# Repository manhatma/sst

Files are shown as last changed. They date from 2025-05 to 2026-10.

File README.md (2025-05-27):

Sufni Suspension Telemetry
==========================

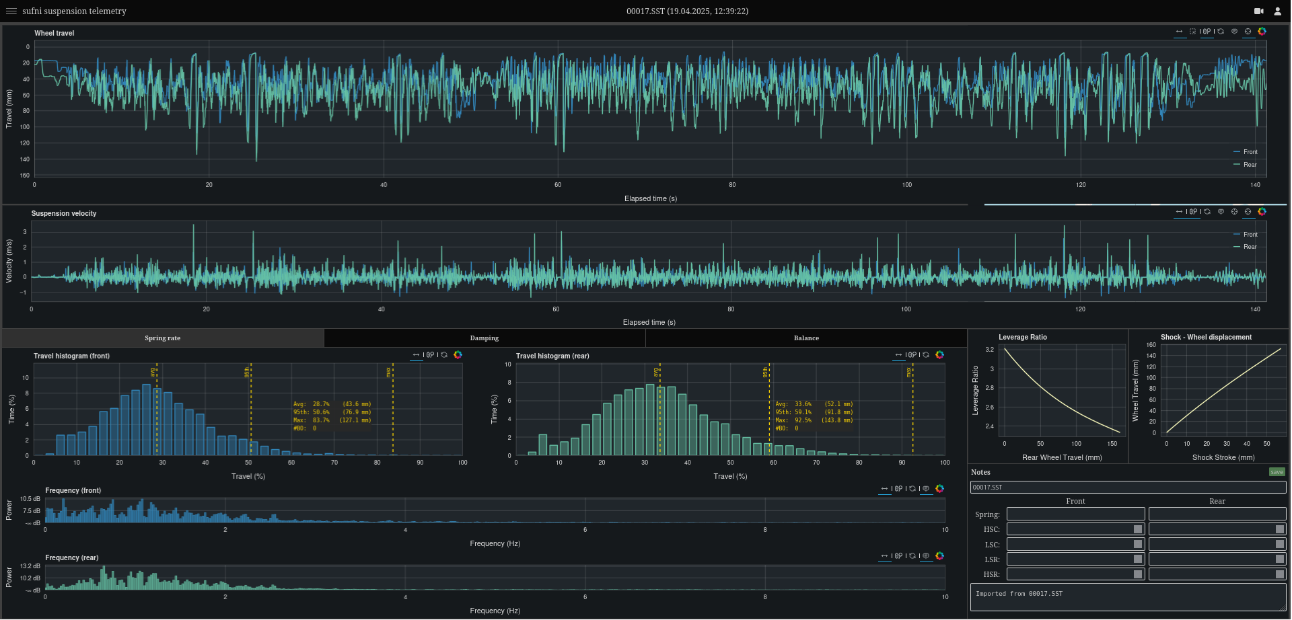
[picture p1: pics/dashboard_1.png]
dashboard

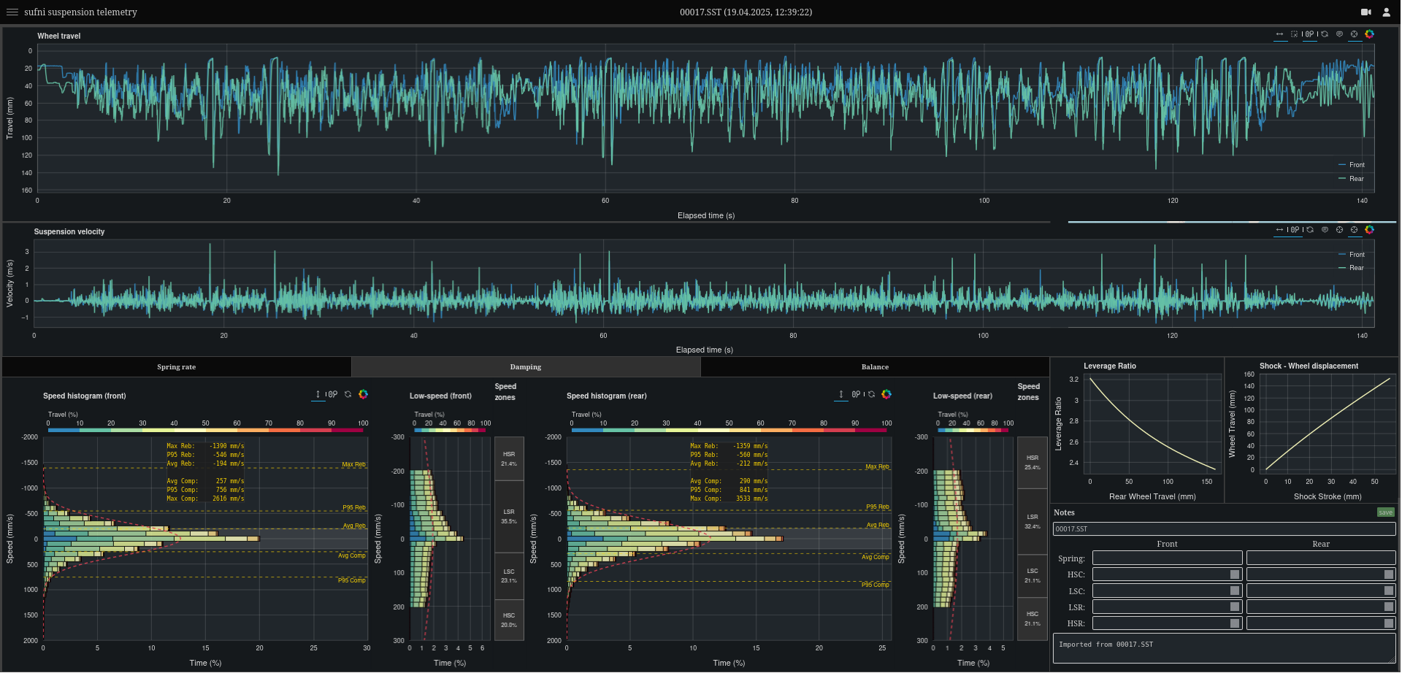
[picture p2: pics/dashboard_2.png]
dashboard


Sufni\* Suspension Telemetry is a mountain bike suspension telemetry system that
was born out of sheer curiosity. The [data acquisition unit](https://github.com/sghctoma/sst/wiki/02-Data-Acquisition-Unit) is built around the
Raspberry Pi Pico W and uses affordable off-the-shelf components, so anybody
with a bit of soldering skills can build it.

Contrary to most (all?) suspension telemetry systems, Sufni uses rotary encoders
to measure movement. They are cheap, reasonably accurate, and can reach pretty
high sample rates. An additional benefit is that on some frames they are easier
to attach to rear shocks than linear sensors, because they can fit into much
tigther spaces.

The DAQ uses a WiFi network to send recorded sessions to the backend server.
When processing is done, data can be analyzed on the [web user interface](https://github.com/sghctoma/sst/wiki/03-Dashboard) that
provides plots useful for setting up the spring rate, damping and the bike's
overall balance. GPX tracks can also be uploaded, and MP4 videos can be opened
from the local machine. These are synchronized to the travel plot, so you can
easily find how your suspension behaved on a certain part of the trail.

The user interface has two additional functionalities:

 - New bike setups can be created, and they can be associated with a DAQ unit
   based on the Pico's uniqe identifer.
 - Normalized (travel percentage, or a number between 0 and 1) data can also be
   [imported](https://github.com/sghctoma/sst/wiki/04-Importing-normalized-data) from CSV files, so you can use the webapp without being tied to
   Sufni's hardware.

Please refer to the wiki for a [quickstart guide](https://github.com/sghctoma/sst/wiki/01-Quickstart-guide), build instructions, and a full
tour on the user interface, plots etc.

\* *The word "sufni" (pronounced SHOOF-nee) means tool shed in Hungarian, but
also used as an adjective denoting something as DIY, garage hack, etc.*

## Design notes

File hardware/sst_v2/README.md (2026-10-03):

# SST v2 Mainboard — Rev. 3 (KiCad)

DAQ-Mainboard für Sufni Suspension Telemetry: 24-bit-ADC für Fork- und Shock-Poti,
Takt für vier IMUs, microSD, RTC, Pico 2 W. Entwurfsgrundlage und Begründungen:
`firmware/docs/plan-ads131m04-icm42686.md`.

```bash
open -a "KiCad" /Users/niels/Telemetry/sst/hardware/sst_v2/sst_v2.kicad_pro
```

Nur diesen Ordner bearbeiten. Vor Skript-Änderungen KiCad schließen
(`~*.lck`), sonst überschreibt die GUI beim Speichern.

## Platine

60 × 90 mm, 4 Lagen, 1,6 mm FR4, ENIG. 4× M3-NPTH (H1–H4).

Platzierung:

- Oben: Pico 2 W auf Buchsenleisten, U1 bei (134,4 / 59,8). Der Körper liegt bei x 84,7–137,1 mm. Das Antennenende liegt am linken Platinenrand (Kante 84,5 mm), wie Raspberry Pi es empfiehlt. Das USB-Ende liegt bei x 137,1 mm. Vor dem USB-Ende liegen 7,4 mm Platine (Rand 144,5 mm).
- Links: Poti-Eingang (J_POT1 am Rand, ESD D2–D4, CMCs), darunter Analogblock (LDO, ADC, Opamp, RC-Netz). Der Analogblock liegt weit weg von Funkmodul und SMPS des Pico.
- Mitte: RTC-Batterie BT1 unter dem Pico, Öffnung zum Pico. Der Bereich zwischen BT1 und den Pico-Buchsenleisten ist frei von Bauteilen, damit die Zelle heraus- und hineingleitet.
- Rechts: OLED- und Taster-Stecker am Rand neben ihren Pico-Pins, Buzzer BZ1, Stromversorgung (D1, D_VSYS1, C26), microSD. Der Körper von J_SD1 endet 0,25 mm vor der Platinenkante.
- Oberkante (x 113–123,6 mm, y 48,3–55,2 mm, zwischen Q_RP1 und J_DEBUG1, außerhalb des Pico): Lader U_CHG1 mit C_CHG1/C_CHG2, R_PROG, R_STAT1/R_STAT2. Thermalfläche: Zone „Lader Thermal“ (GND, F.Cu, Priorität 2, volle Anbindung) über den Laderbereich und den Streifen über J_DEBUG1, gefüllt 0,77 cm² zusammenhängend (0,49 cm² im Laderbereich). Sechs GND-Vias 0,6/0,3 mm links neben dem VSS-Pad (Pin 2) zur GND-Lage In1. +VBUS und +VBAT kommen auf B.Cu, F.Cu bleibt dort fast ganz GND.
- Unter dem Pico: R50 (ADC_RST) bei (110,0 / 62,3) neben GP7 (Pin 10). Soft-Power-Steuerung (U_PWR1, C_PWR1, Q_PWR2, Q_PWR3, R_PWR2–R_PWR4, D_PWR1) und Fuel Gauge (U_FG1, C_FG1) zwischen den Buchsenleisten bei x 120–135 mm, y 61–74 mm (Bauhöhe ≤ 1,1 mm, Buchsenleisten 8,5 mm). `sst_v2.kicad_dru` erlaubt die Courtyard-Überdeckung mit U1 nur für diese Teile.
- Unter der unteren Pico-Buchsenleiste (außerhalb des Pico): Lastschalter Q_PWR1 (119,6 / 82,1) mit Gate-Pull-up R_PWR1 (122,9 / 82,1), direkt vor C26.
- Pico-Antenne (Ende gegenüber USB, x < 94 mm, am linken Rand): Rule Area „Pico antenna: keepout“ auf allen Kupferlagen, ohne Leiterbahnen, Vias und Pours. Sie deckt den Raum zwischen den Buchsenleisten (x 84,5–94,0 mm, y 61,3–76,1 mm) und das Pico-Ende über die volle Breite ab (x 84,5–85,1 mm, y 57,1–80,2 mm). Der Rand von 1 mm liegt außerhalb der Platine, die Fläche endet an der Kante. Die Streifen der Buchsenleisten bleiben frei, damit die Leitungen an Pin 17–24 nach außen laufen. In1 (GND) und In2 (+3V3_DIG) haben dort eine Aussparung.
- Fiducials FID1–FID3 (1 mm, Maske 3 mm) auf F.Cu: (135,95 / 54,8), (89,5 / 106,8), (136,95 / 101,3). Alle ≥ 5 mm von der Kante, außerhalb von Pico und Steckern.
- Montagelöcher: Alle Courtyards liegen ≥ 3,5 mm von der Bohrungsmitte (Platz für Schraubenkopf oder Scheibe Ø 7 mm).
- Unten: IMU-Stecker, Taktteiler und Taktpuffer.
- Digitalleitungen (IMU, SD, UI) laufen außerhalb des Analogblocks. Die ADC-SPI-Leitungen laufen im Poti-Block nur auf B.Cu, getrennt durch die GND-Lage In1.

| Lage | Inhalt |
|---|---|
| F.Cu | Bauteile, Signale, GND-Pour |
| In1.Cu | GND, durchgehend |
| In2.Cu | +3V3_DIG; Insel +3V0_ANA unter der analogen Seite von LDO/ADC/Opamp (x 94,3–108,5 mm, y 112,2–132,5 mm, dazu Streifen y 107,8–112,2 mm ab x 84,9 mm). Die digitale Seite von LDO und ADC (x < 94,3 mm) liegt über +3V3_DIG. |
| B.Cu | Signale, GND-Pour |

Fertigungsregeln (PCBWay): Leiterbahn/Abstand ≥ 0,2 mm, Via 0,6/0,3 mm (+3V3_DIG: 0,7/0,4 mm,
Power: 0,8/0,4 mm), Via-Restring ≥ 0,15 mm, Kupfer–Kante ≥ 0,3 mm, Lötstopp-Steg ≥ 0,1 mm
(grüner Lötstopp). Silkscreen: Strichbreite ≥ 0,15 mm, Texthöhe ≥ 0,8 mm (PCBWay-Minimum). `sst_v2.kicad_pro`
prüft Restring und Textstrich mit 0,15 mm, Texthöhe mit 0,8 mm.

## Schaltung

| Block | Bauteile | Kurzbeschreibung |
|---|---|---|
| ADC | U2 ADS131M04 | CH0 Fork, CH1 Shock, CH2 Poti-Speisung (ratiometrisch), CH3 an GND. AVDD 3,0 V, DVDD = Netz +3V3_DVDD aus +3V3_DIG über FB1 (Logikpegel = Pico-Pegel, PWR_FLAG hinter FB1). CAP 220 nF. SYNC/RESET (ADC_RST) über R50 100 Ω an GP7 (ADC_RST_MCU), Pull-up R1, C4. |
| Analog-LDO | U_ANA_LDO1 TPS7A4700 (RGW) | 3,3 V → 3,0 V, ANY-OUT: nur 1P6V (Pin 8) an GND, übrige ANY-Pins offen. SENSE an OUT. NR 10 nF (C25), IN 10 µF (C22), OUT 22 µF (C6). |
| Poti-Speisung | U_AAF1 TLV4333 (A), R32/R33 20k/10k 0,1 %, C35 | 1,0 V Referenz, gepuffert, 47 Ω (R34) auf POT_EXC, Messung über R35/C36 an AIN2P. |
| Schleifer | U_AAF1 (B, C), R36/R37, R8/R14, C9/C12 | Opamp-Puffer, danach 1 kΩ + 10 nF an AINxP. AINxN = Poti-Masse (Remote Sense), R9/R15 0 Ω als Sternpunkt. |
| Poti-Stecker | J_POT1 JST-SH 6 → HR30 6p | 1 POT_EXC, 2 Fork-Schleifer, 3 Fork-Masse, 4 Shock-Schleifer, 5 Shock-Masse, 6 Schirm/GND. ESD D2–D4, CMC L_FORK/L_SHOCK (DLW5BTM251SQ2L). |
| Takt | Y1 ECS-2520MVLC 8,192 MHz, U_DIV1 74HC4040, U_CLKBUF1 74LVC125 | XO → 33 Ω → ADC CLKIN; XO → 4040 Q7 = 32,000 kHz → 2 Puffer → 33 Ω → IMU-CLKIN A/B. |
| IMU | J_IMU_A1/B1 JST-SH 12 → HR30 12p | 1 IMU_3V3 (FB2), 3 SCLK, 5 MOSI, 7 MISO, 8 CLKIN, 10/11 CS, 2/4/6/9/12 GND. 33 Ω in allen DAQ-Ausgängen. |
| Strom | J_BAT1, Q_RP1, Q_PWR1, D1, D_VSYS1 | LiPo (JST-PH) → Q_RP1 DMG2305UX (Verpolschutz) → +VBAT → Q_PWR1 DMG2305UX (Soft-Power-Schalter) → +VBAT_SW (TVS D1, C26–C28) → D_VSYS1 PMEG3020EH → VSYS. D_VSYS1 verhindert, dass USB-VBUS direkt in den Akku speist. Kein externer Schalter mehr (J_PWR1 entfällt). |
| Soft-Power | U_PWR1 MAX16150AUT+T, Q_PWR1 DMG2305UX, Q_PWR2/Q_PWR3 2N7002, R_PWR1–R_PWR4 100k, C_PWR1 100 nF, D_PWR1 RB751S40 | U_PWR1 VCC an +VBAT. Taster SW_L1 → PWR_BTN → PB_IN (interner Pull-up 1,2–2,0 MΩ an VCC). Drücken > 50 ms: OUT (PSW_EN) high → Q_PWR2 zieht PSW_GATE auf GND → Q_PWR1 leitet. R_PWR1 hält Q_PWR1 sonst aus, R_PWR2 hält Q_PWR2 aus, solange OUT undefiniert ist. Aus per Firmware: GP28 (PWR_OFF) high → Q_PWR3 zieht ~CLR low → OUT low. R_PWR4 hält Q_PWR3 ohne Firmware aus. ~CLR-Pull-up R_PWR3 an OUT (Datenblatt-Empfehlung): kein VBAT-Pegel an einem GPIO. Halten > 8 s (Version A): OUT low, Hardware-Aus. ~INT offen. BTN_L (GP4, R27 10k an +3V3_DIG) liegt über D_PWR1 (Anode BTN_L, Kathode PWR_BTN) am Taster: SW_L1 bleibt UI-Taste. |
| Fuel Gauge | U_FG1 MAX17048G+T10, C_FG1 100 nF | VDD (Messeingang) und CELL an +VBAT, dauerhaft versorgt. I2C 0x36 am PIO-I2C (DISP_SDA/DISP_SCL, R25/R26). CTG, QSTRT, EP an GND, ~ALRT offen (kein GPIO frei). |
| Lader | U_CHG1 MCP73831T-2ACI/OT, C_CHG1/C_CHG2 4,7 µF, R_PROG 3,3k, R_STAT1/R_STAT2 10k/10k | Platz an der Oberkante außerhalb des Pico, mit Thermalfläche (GND-Zone 0,77 cm² an VSS, 6 Vias zu In1). VDD an +VBUS (Pico Pin 40), Ausgang an +VBAT (vor dem Schalter): Laden auch bei ausgeschaltetem Gerät (Q_PWR1 offen). 4,20 V, 300 mA (I = 1000 V / R_PROG; 500 mA mit 2,0k). STAT über Teiler 10k/10k an GP6 (CHG_STAT): Laden = 0 V, fertig = 0,5 × VBUS (2,5 V bei 5,0 V, max. 2,6 V bei 5,25 V), ohne VBUS hochohmig → 0 V. USB kommt über ein Kabel von einer Gehäusebuchse in die Micro-USB-Buchse des Pico. |
| RTC | U3 DS3231SN, BT1 CR1220 | VBAT direkt an der Zelle, RST offen. I2C gemeinsam mit OLED und U_FG1 (PIO, R25/R26 4,7k). |
| microSD | J_SD1 DM3AT | SPI0. Pull-ups: SD_CS 10k (R31), DAT1 47k (R48), DAT2 47k (R49). |
| UI | SW_L1/SW_R1 (JST-SH 2), BZ1 PS1240P02BT, J_OLED1, J_DEBUG1 | Taster mit 10k-Pull-up. SW_L1 ist zusätzlich die Power-Taste (siehe Soft-Power). Buzzer über 47 Ω an GP22. J_DEBUG1: 1 RX (GP1), 2 TX (GP0), 3 GND. SWD direkt am Pico. |
| MCU | U1 Pico 2 W | Steckt in 2× 1×20-Buchsenleisten (8,5 mm). 3V3_EN offen (interner Pull-up). |

### Pico-Pinbelegung

| GP | Netz | GP | Netz |
|---:|---|---:|---|
| 0/1 | UART TX/RX | 14 | IMU_MISO |
| 2/3 | DISP_SDA/SCL (PIO I2C, RTC + OLED + Fuel Gauge) | 15 | IMU_CS0 |
| 4/5 | BTN_L (über D_PWR1 auch Power-Taste)/BTN_R | 16–19 | SD MISO/CS/SCK/MOSI (SPI0) |
| 6 | CHG_STAT (Lader, Teiler 10k/10k) | 20 | ADC_DRDY |
| 7 | ADC_RST_MCU → R50 100 Ω → ADC_RST (SYNC/RESET) | 21 | IMU_CS1 |
| 8/9 | IMU_SCLK/MOSI (PIO-SPI) | 22 | Buzzer |
| 10–12 | ADC SCK/SDI/SDO (SPI1) | 26/27 | IMU_CS2/CS3 |
| 13 | ADC_CS | 28 | PWR_OFF (high = Abschalten, Q_PWR3 → MAX16150 ~CLR) |

## Fertigungsdaten (`fab/`)

- `gerber/` + `sst_v2_gerber.zip`: Gerber (Protel-Endungen), Excellon PTH/NPTH, Bohrpläne, Job-Datei.
- `sst_v2_BOM_PCBWay.csv`, `sst_v2_CPL_PCBWay.csv`: 111 Positionen. Der Pico wird nicht bestückt, nur die Buchsenleisten.
  H1–H4, FID1–FID3 und TP1–TP15 stehen nicht in BOM und CPL.

Bestellhinweis PCBWay:

| Parameter | Wert |
|---|---|
| Größe | 60 × 90 mm (die Job-Datei meldet 60,1 × 90,1 mm wegen der Breite der Konturlinie) |
| Lagen | 4, Lagenzuordnung: L1 `sst_v2-F_Cu.gtl`, L2 `sst_v2-GND.g1`, L3 `sst_v2-PWR.g2`, L4 `sst_v2-B_Cu.gbl` |
| Dicke | 1,6 mm FR4 |
| Oberfläche | ENIG |
| Lötstopp / Bestückungsdruck | grün / weiß |
| Fiducials | FID1–FID3 auf F.Cu |

Export (Ordner `hardware/sst_v2`):

```bash
kicad-cli pcb export gerbers -l "F.Cu,In1.Cu,In2.Cu,B.Cu,F.Paste,B.Paste,F.Silkscreen,B.Silkscreen,F.Mask,B.Mask,Edge.Cuts" --subtract-soldermask -o fab/gerber/ sst_v2.kicad_pcb
kicad-cli pcb export drill --format excellon --excellon-separate-th --excellon-units mm --generate-map --map-format gerberx2 -o fab/gerber/ sst_v2.kicad_pcb
```

## Testpads (Unterseite)

15 SMD-Pads D 1,0 mm (`TestPoint:TestPoint_Pad_D1.0mm`) auf B.Cu, nur B.Mask, keine Paste.
Nicht bestückt: nicht in BOM und CPL (`in_bom no`, `exclude_from_bom`, `exclude_from_pos_files`).
Beschriftung = Wert auf B.Silkscreen (0,8 mm, Strich 0,15 mm, von unten lesbar), Referenz verborgen.
Im Schaltplan als Gruppe „Testpads (Unterseite, nicht bestückt)“ rechts unten.

| TP | Netz | Beschriftung | Lage B-Seite (x/y mm) | Anbindung | Zweck |
|---|---|---|---|---|---|
| TP1 | GND | GND | 93,00 / 121,00 | GND-Pour B.Cu | Masse Analogteil (U2/LDO) |
| TP2 | GND | GND | 110,00 / 57,00 | GND-Pour B.Cu | Masse Stromversorgung (Lader, Q_RP1) |
| TP3 | GND | GND | 89,80 / 126,11 | GND-Pour B.Cu | Masse für Taktmessung, 2,55 mm neben TP6 |
| TP4 | +3V0_ANA | 3V0A | 96,46 / 114,05 | auf vorhandener Via | Analog-LDO-Ausgang |
| TP5 | +3V3_DVDD | DVDD | 86,80 / 128,68 | neue Via im Pad, F.Cu 0,6 mm | ADC-DVDD hinter FB1 |
| TP6 | ADC_CLKIN | CLK | 92,30 / 126,61 | neue Via im Pad, direkt auf der Leiterbahn (kein Stich) | 8,192-MHz-Takt am ADC (zwischen R38 und U2 Pin 17) |
| TP7 | +VBAT_SW | VBSW | 123,38 / 106,85 | Via + 1,0 mm B.Cu | Akku nach Q_PWR1 (Soft-Power) |
| TP8 | +VBAT | VBAT | 115,70 / 52,55 | auf vorhandener Via | Akku vor Q_PWR1 / Laderausgang |
| TP9 | EXC_REF | REF | 104,93 / 110,25 | neue Via im Pad, auf der Leiterbahn | Referenzspannung (R32/R33/C35, U_AAF1 Pin 3) |
| TP10 | POT_EXC | EXC | 90,95 / 87,84 | auf vorhandener Via | Poti-Speisung am Stecker |
| TP11 | FORK_AIN_P | FORK | 100,83 / 126,54 | Via + 1,0 mm B.Cu | ADC-Eingang Gabel |
| TP12 | SHOCK_AIN_P | SHCK | 100,92 / 123,39 | neue Via (F.Cu 0,6 mm) + 1,0 mm B.Cu | ADC-Eingang Dämpfer |
| TP13 | IMU_CLK32K | 32K | 117,75 / 121,65 | neue Via im Pad, auf der Leiterbahn | 32,768-kHz-Takt der IMUs |
| TP14 | IMU_3V3 | IMU | 126,50 / 134,81 | auf vorhandener Via | IMU-Versorgung |
| TP15 | GND | GND | 114,30 / 127,25 | GND-Pour B.Cu | Masse Takt-/IMU-Bereich (U_DIV1) |

Abstand Pad zu Pad ≥ 2,54 mm. Keine Pads in der Pico-Antennenfläche. Vias 228 → 233.

## Prüfstand (2026-10-03)

- ERC: 0 Fehler. 2 Warnungen, bewusst: MP-Pins von SW_L1/SW_R1.
- DRC mit Schaltplan-Parität (`--refill-zones --all-track-errors --severity-all`): 0 Fehler, 0 offene Verbindungen,
  0 Paritätsfehler. 6 Warnungen `lib_footprint_mismatch`, bewusst:
  H1–H4 ohne Courtyard, J_SD1 mit um 0,4 mm gekürzten vorderen Schirm-Pads (Kupfer–Kante 0,3 mm),
  U1 ohne Silkscreen-Linien am USB-Ende (lag bis 2026-10-03 am Platinenrand).
- Alle Referenzen stehen auf dem Silkscreen mit 0,8 mm Höhe und 0,15 mm Strich, von Hand positioniert (2026-10-03). Nur H1, H2 und FID1–FID3 haben die Referenz auf F.Fab. Referenzen unter dem Pico (R2, R27–R29, R41, R42, R44–R46, R50) sind nach dem Aufstecken verdeckt.
- U_AAF1: Referenz im Gehäuseumriss (links davon sitzt jetzt C1).
- U1: Die Silkscreen-Markierung im USB-Bereich unter dem Pico ist entfernt (lag über den früheren Lader-Pads).
- Zonen sind gefüllt gespeichert. Leiterbahnlänge 2658 → 2644 mm, Vias 225 → 228 (Lader an der Oberkante).
- Soft-Power + Fuel Gauge (2026-10-03): ERC und DRC wie oben (keine neue Warnung). Leiterbahnlänge 2649 → 2697 mm, Vias 233 → 250. Neue Verbindungen mit einem Rasterrouter (Raster 0,05 mm, Abstand netzklassengerecht), danach DRC. Neue Referenzen unter dem Pico (U_PWR1, C_PWR1, D_PWR1, Q_PWR2, Q_PWR3, R_PWR2–R_PWR4, U_FG1, C_FG1) sind nach dem Aufstecken verdeckt.
- Pico 7 mm nach links (2026-10-03): ERC und DRC wie oben (keine neue Warnung). Leiterbahnlänge 2697 → 2735 mm, Vias 250 → 264. Details im Review unten.
- Doppelte UUIDs: TP1–TP15 teilten sich 5 UUIDs (Pad und Grafik, 70 Duplikate aus dem Kopier-Skript). Alle Duplikate haben jetzt eigene UUIDs.

## Review Rev. 3 (2026-10-03): Pico 7 mm nach links

| Änderung | Grund |
|---|---|
| U1 (Pico 2 W) 7,0 mm nach links: (141,4 / 59,8) → (134,4 / 59,8). Körper x 84,7–137,1 mm. Vor dem USB-Ende liegen jetzt 7,4 mm Platine (vorher 0,4 mm). | Gehäusegröße: Der 90°-Micro-USB-Stecker brauchte 9 mm über den Platinenrand. Er ragt jetzt 7 mm weniger heraus. |
| Antennenende am linken Rand (Körper 84,7 mm, Kante 84,5 mm). Rule Area „Pico antenna: keepout“ um 7 mm mit verschoben und an der Kante abgeschnitten: x 84,5–94,0 mm (vorher 90,7–101,0 mm). | Raspberry Pi empfiehlt die Antenne am Platinenrand. Unter der Antenne liegt kein Kupfer, auch nicht in In1/In2. |
| R50 6,6 mm nach links: (116,6 / 62,3) → (110,0 / 62,3). | Der Serienwiderstand bleibt direkt an GP7 (Pin 10). ADC_RST_MCU ist 1,5 mm lang. |
| Leitungen am Pico neu geroutet: Rasterrouter (Raster 0,05 mm, Abstand netzklassengerecht, Rip-up bei Konflikten). Entfernt: Leiterbahnen und Vias der Pico-Netze im Band y 56,6–84 mm, dazu IMU_CS0, IMU_MOSI, IMU_SCLK und ADC_RST im selben Band. Die neuen Leitungen schließen an die vorhandenen Leitungen unterhalb von y 84 mm und an der Oberkante an. | Die Pins liegen 7 mm weiter links. Die alten Leitungen kreuzten die neuen Pads. Analogblock und Poti-Block bleiben unverändert. |
| +VBAT (0,5 mm) unter dem Pico 0,62 mm nach rechts. PSW_GATE an Pin 34 vorbei neu gelegt. | Beide Leitungen liefen durch die neuen Pad-Positionen. Die Lücken der Buchsenleisten liegen jetzt 0,62 mm weiter rechts. |
| ADC-SPI im Poti-Block weiter nur auf B.Cu, keine neuen Vias dort. Unter den linken unteren Pico-Pins (y 78,4–85 mm) laufen die SD-Leitungen nur auf F.Cu und die ADC-Leitungen nur auf B.Cu, dort ohne Vias. | Die ADC-Leitungen kommen jetzt zwischen den Buchsenleisten herunter (x 94–102 mm) und laufen unter den SD-Abgängen zum linken Rand. Die GND-Lage In1 trennt beide Gruppen. |
| +VBUS (0,5 mm) von Pin 40 über den Streifen rechts vom Pico (x 135,1–135,7 mm), F.Cu bei y 53,25 mm, B.Cu zum Lader. VSYS (0,5 mm) auf F.Cu von Pin 39 zu D_VSYS1. | Die Power-Leitungen laufen nicht durch die Lücken der Buchsenleisten. |
| 2 GND-Vias 0,6/0,3 mm mit 0,25-mm-Leitung an U1 Pin 3 (128,27 / 58,95) und Pin 28 (103,92 / 78,93). | DRC `starved_thermal`: An Pin 28 war die F.Cu-Pour-Fläche eine Insel. An Pin 3 erreichte nur ein Steg den Pour. |
| Texte „SSDAQ v1 Rev 3“ und „10/2026“ an den rechten Rand (x 139,6 / 142,0 mm). | Der alte Platz links vom Pico liegt jetzt unter dem Pico. |

Ergebnis: ERC 0 Fehler (2 bekannte MP-Warnungen). DRC 0 Fehler, 0 offene Verbindungen, 0 Paritätsfehler, 6 bekannte `lib_footprint_mismatch`. Leiterbahnlänge 2697 → 2735 mm, Vias 250 → 264 (Pico-Netze 1135 → 1175 mm, 33 → 44 Vias). Gerber, Bohrdaten, ZIP, CPL (U1, R50) und `enclosure/sst_v2_board.step` neu erzeugt. BOM unverändert.

## Review Rev. 3 (2026-10-03): Soft-Power MAX16150 + Fuel-Gauge MAX17048

| Änderung | Grund |
|---|---|
| J_PWR1 (externer Schalter) entfernt. Q_PWR1 DMG2305UX als High-Side-Schalter zwischen +VBAT und +VBAT_SW, gesteuert von U_PWR1 MAX16150AUT+T über Q_PWR2 2N7002. | Ein- und Ausschalten mit der linken Panel-Taste. Die Firmware kann das Gerät selbst abschalten. |
| SW_L1 Pin 2 → PWR_BTN (PB_IN). BTN_L über D_PWR1 RB751S40 an PWR_BTN. | Die Taste bleibt UI-Taste. Gedrückt: BTN_L = VF ≈ 0,3 V (low). Losgelassen: Diode sperrt, kein Strom in den GPIO. Pico ohne Spannung: Diode sperrt, nur Leckstrom. |
| GP28: VBAT_SENSE → PWR_OFF. R19/R20/C29 entfernt. GP28 → Q_PWR3 2N7002 → ~CLR. R_PWR3 100k von ~CLR an OUT. | Kein GPIO frei. Die Akkuspannung misst jetzt U_FG1. ~CLR nur an OUT hochgezogen: Im Aus-Zustand liegt kein VBAT-Pegel an einem Pin des Pico. |
| U_FG1 MAX17048G+T10 mit C_FG1 an +VBAT und PIO-I2C (0x36). | Ladezustand (SOC), Zellspannung (VCELL) und Lade-/Entladerate (CRATE) über I2C. |
| Netzklassen-Muster VBAT_SENSE aus `sst_v2.kicad_pro` entfernt. Courtyard-Regel für die Teile unter dem Pico in `sst_v2.kicad_dru`. | Netz existiert nicht mehr. Teile sitzen absichtlich unter dem Pico. |
| Langer Leiterzug von der Oberkante (früher +VBAT_SW ab J_PWR1) ist jetzt +VBAT. Q_PWR1 sitzt am unteren Ende vor C26. | Leistungspfad bleibt 0,5 mm breit und kurz. +VBAT liegt damit auch für U_PWR1 und U_FG1 bereit (Zuleitung 0,3/0,25 mm, µA-Lasten). |

Datenblattwerte:

- **MAX16150A** (Datenblatt Rev 4, 1/21): VCC 1,3–5,5 V. ISB ≤ 20 nA (VCC 5 V, OUT low, −40…+70 °C), 10/40 nA typ/max bis +85 °C. ICC 15/30 µA nur während PB_IN-Erkennung oder INT-Puls. PB_IN-Pull-up 1,2/1,4/2,0 MΩ an VCC, Eingang ±60 V. VIH 0,7 × VCC, VIL 0,3 × VCC. tDB 50 ms, tSO 8 s (±20 %). ~CLR wird bei OUT low ignoriert und nach OUT high für 1,6–2,4 × tINT (51–77 ms). OUT = VCC − 0,1 V bei 20 mA. Das Datenblatt empfiehlt Pull-up von ~CLR/~INT an OUT.
- **Q_PWR1 DMG2305UX:** RDS(on) ≤ 52 mΩ (typ 40) bei VGS −4,5 V, ≤ 100 mΩ (typ 52) bei −2,5 V. Bei leerem Akku (VGS −3,0 V) also ≤ 100 mΩ: 0,5 A → ≤ 50 mV, ≤ 25 mW. VGS(th) −0,5…−0,9 V, IDSS ≤ 1 µA.
- **Q_PWR2/Q_PWR3 2N7002 (Diodes):** VGS(th) 1,0–2,5 V, IDSS ≤ 1 µA (60 V), IGSS ≤ 10 nA. Last nur 42 µA (4,2 V / 100k): bei VGS 3,0 V (Akku leer) bzw. 3,3 V (GP28) sicher durchgeschaltet.
- **D_PWR1 RB751S40 (Nexperia):** VF ≤ 370 mV bei 1 mA. Kurve: ≈ 0,27 V bei 0,33 mA (25 °C), ≈ 0,36 V bei −40 °C. RP2350 VIL ≤ 0,8 V: BTN_L ist sicher low. IR ≤ 0,5 µA bei 30 V. Kurve: ≈ 15 nA bei 4 V / 25 °C, ≈ 1,5 µA bei 85 °C. Spannungsabfall an PB_IN im Aus-Zustand: 15 nA × 1,4 MΩ = 21 mV (25 °C), ≈ 0,4 V bei 60 °C (2,0 MΩ). PB_IN bleibt über 0,7 × VCC.
- **MAX17048** (Datenblatt Rev 7): VDD 2,5–4,5 V. Aktiv 23/40 µA, Hibernate 3/5 µA (VRESET.Dis = 1) bzw. 4 µA typ (Komparator an), Sleep 0,5/2 µA (≤ 50 °C). Sleep nur mit MODE.EnSleep = 1 und SDA und SCL < VIL (0,5 V) für tSLEEP 1,75–2,5 s; eine steigende Flanke an SDA oder SCL weckt den Baustein. SDA/SCL haben 0,2/0,4 µA Pull-down (Erkennung „Bus offen“). Datenpins −0,3…+5,5 V unabhängig von VDD, SDA Open Drain, SCL Eingang: kein Rückspeisen in den 3V3-Bus. VIH 1,4 V. Im Sleep erkennt der Baustein keine Selbstentladung. Laden weckt ihn: USB versorgt den Pico, der Bus geht high.

### Ruhestrom im Aus-Zustand (USB ab, Pico ohne Spannung, 25 °C)

| Teil | typ | max | Bemerkung |
|---|---:|---:|---|
| U_PWR1 MAX16150 (ISB) | < 20 nA | 20 nA | Grenzwert bei 5 V, ≤ 70 °C |
| D_PWR1 Leckstrom über PB_IN-Pull-up | 15 nA | 0,5 µA | max = IR-Grenzwert bei 30 V |
| U_FG1 MAX17048, Sleep (EnSleep = 1) | 0,5 µA | 2 µA | ohne EnSleep: Hibernate 3 µA typ / 5 µA max |
| U_CHG1 MCP73831, Rückstrom (VDD offen) | 0,25 µA | 2 µA | |
| Q_PWR1 IDSS in die +VBAT_SW-Last | < 0,01 µA | 1 µA | max bei −20 V |
| Q_PWR2 IDSS über R_PWR1 | < 0,01 µA | 1 µA | max bei 60 V |
| R_PWR1–R_PWR4, C_PWR1, C_FG1 | 0 | – | ohne Spannung bzw. MLCC |
| **Summe** | **≈ 0,8 µA** | **≈ 6,5 µA** | Hibernate statt Sleep: ≈ 3,3 / 9,5 µA |

1200 mAh / 0,8 µA ≈ 170 Jahre, bei 6,5 µA ≈ 21 Jahre. Die Selbstentladung des LiPo (einige %/Monat) dominiert.

### Firmware-Folgen

1. **Abschalten:** SD-Datei schließen (Puffer schreiben, `f_close`, `f_sync`), dann GP28 high. Ohne USB fällt die Versorgung sofort. Mit USB läuft der Pico weiter: GP28 nach ≥ 100 ms wieder low setzen. Sonst schaltet ein Tastendruck nach der ~CLR-Sperrzeit (≈ 64 ms) sofort wieder ab.
2. **GP28 beim Start:** so früh wie möglich als Ausgang low. R_PWR4 hält Q_PWR3 bis dahin aus.
3. **BTN_L:** bleibt UI-Taste (GP4, aktiv low, Pegel ≈ 0,3 V). Der Einschalt-Druck ist beim Booten oft noch aktiv: BTN_L erst nach dem ersten Loslassen auswerten. Halten > 8 s = Hardware-Aus ohne Dateiabschluss. Darum: bei Halten ≥ 3 s die Datei schließen und selbst über GP28 abschalten.
4. **Akku:** Spannung und Ladezustand aus U_FG1 (VCELL 0x02: 78,125 µV/LSB, SOC 0x04: 1/256 %, CRATE 0x16: 0,208 %/h) statt VSYS-Teiler an GP28. Nach jedem Start STATUS.RI prüfen; wenn gesetzt, Konfiguration schreiben (MODE.EnSleep = 1, ggf. RCOMP) und RI löschen.
5. **Neuer Zustand CHARGING:** Start mit USB (VBUS über CYW43 WL_GPIO2) und ohne USB-Host → Anzeige „CHARGING“, SOC-Balken, Restzeit aus CRATE; „FULL“ bei CHG_STAT high (GP6). Host meldet sich an → MSC wie bisher. SW_L1-Druck → normaler Betrieb (der Druck schaltet zugleich Q_PWR1 ein).

## Review Rev. 3 (2026-09-30)

| Änderung | Grund |
|---|---|
| 23 Vias +3V3_DIG 0,6/0,4 → 0,7/0,4 mm; `min_via_annular_width` 0,15 | PCBWay: Restring ≥ 0,15 mm (vorher 0,10 mm). Keine neuen Abstandsfehler. |
| 347 Silkscreen-Linien 0,12 → 0,15 mm; Referenzen 0,8 → 1,0 mm Höhe, Strich 0,15 mm; `min_text_thickness` 0,15 | PCBWay: Strich ≥ 0,15 mm, Höhe ≥ 0,8 mm, Verhältnis 1:5. |
| R_STAT2 20k → 10k | CHG_STAT-Teiler: „fertig“ = 0,5 × VBUS = 2,6 V bei 5,25 V (mit 20k: 3,5 V über IOVDD 3,3 V). |
| Rule Area „Pico antenna: keepout“: alle Kupferlagen, keine Leiterbahnen, Vias, Pours; volle Pico-Breite + 1 mm am Ende | Vorher nur Pour-Verbot auf F.Cu/B.Cu. ADC_CS, ADC_SCK, ADC_SDI, ADC_SDO liefen durch die Antennenfläche. Neu geroutet (Rasterrouter): ADC_CS/ADC_SCK rechts der Fläche (x > 101 mm), ADC_SDI/ADC_SDO über die Oberkante und links der Fläche (x ≈ 90,1/90,55 mm). Analogblock unverändert. |
| C1 an U_AAF1 Pin 4 (0,55 mm Pad-zu-Pad, vorher 3,8 mm), eigene GND-Via | Abblockung V+ direkt am Pin. POT_EXC dafür auf F.Cu 0,8 mm nach links verlegt. |
| C_CHG1 (VBUS) und C_CHG2 (VBAT) getauscht: C_CHG1 1,6 mm Pad-zu-Pad an U_CHG1 Pin 4 (vorher 4,2 mm) | Eingangskondensator direkt am VDD-Pin. +VBUS läuft von Pin 40 über C_CHG1 zu Pin 4, +VBAT zu C_CHG2 links vorbei. |
| R50 100 Ω 0603 zwischen GP7 (ADC_RST_MCU) und ADC_RST (R1/C4/U2 Pin 11), unter dem Pico an Pin 10 | Serienwiderstand gegen Überschwinger und Querstrom auf der langen Reset-Leitung. |
| Netz +3V0_DVDD → +3V3_DVDD, PWR_FLAG hinter FB1 | Name entsprach nicht der Spannung; ERC-Warnung „power pin not driven“ an U2 Pin 20 entfällt. |
| Fiducials FID1–FID3 (Schaltplan + Layout) | Passermarken für die Bestückung. Freie Plätze mit ≥ 1,6 mm Abstand zu Kupfer und Silkscreen. |
| Titelblock Rev. „3“ (Schaltplan, Layout) | Job-Datei meldete Revision „A“. |
| Lader umgesetzt: U_CHG1, C_CHG1/C_CHG2, R_PROG, R_STAT1/R_STAT2 von unter dem Pico (141/69) an die Oberkante (x 113–123,6, y 48,3–55,2). GND-Zone „Lader Thermal“ 0,77 cm², 6 GND-Vias am VSS-Pad. C_CHG1 0,75 mm Pad-zu-Pad an VDD, C_CHG2 0,72 mm an VBAT, R_PROG 0,68 mm an PROG. +VBUS 49 mm (Pin 40 → F.Cu x 143,1 → B.Cu y 57,5 → Lader), +VBAT ab J_PWR1 10 mm (vorher 34 mm), CHG_STAT gerade zu GP6. Courtyard-Ausnahmen der sechs Teile aus `sst_v2.kicad_dru` entfernt. R42-Referenz links neben R42. | Unter dem Pico staute sich die Wärme (θJA 230 K/W, 0,4–0,6 W beim Laden) ohne Kupferfläche und ohne Luft. Jetzt liegt der Lader frei, mit Kupfer an VSS und Vias zur GND-Lage. |

## Review Rev. 3 (2026-09-27) — behobene Fehler

| Fehler | Behebung |
|---|---|
| TPS7A4700-Symbol mit falscher Pinbelegung (GND-Pin an 3,3 V, OUT/IN vertauscht, ANY-OUT an 3,3 V) | Symbol nach SBVS204G, Footprint Texas RGW0020A, LDO-Bereich neu geroutet, Eingangs-C ergänzt |
| USB-VBUS speiste über die Pico-Schottky in den Akku | D_VSYS1 zwischen +VBAT_SW und VSYS |
| RTC-Backup-Diode verpolt | Diode entfernt, CR1220 direkt an VBAT |
| Buzzer-Footprint 7,6 mm statt 5 mm Raster | Footprint Buzzer_TDK_PS1240P02BT |
| R18 zog 3V3_EN auf die eigene Ausgangsspannung | R18 entfernt |
| DS3231 RST fest an 3,3 V | RST offen |
| ADS131M04 DVDD 3,0 V bei 3,3-V-Logik | DVDD aus +3V3_DIG über FB1 |
| CMC gegenphasig beschaltet (Gleichtaktdämpfung unwirksam) | Beschaltung nach Murata-Ersatzschaltbild: Eingänge ②/③, Ausgänge ①/④ |
| SWD-Pins am Header ohne Verbindung | J_DEBUG1 als 1×3 UART |
| DRC: 40 Lötstopp-Stege, 17 Thermals, 4 Randabstände | Regeln an PCBWay angepasst, volle Anbindung, J_SD1-Pads gekürzt |

Zusätzlich umgesetzt: Verpolschutz Q_RP1, Polymer-Tantal C26, 1 µF direkt an AVDD
(C23), 100 nF direkt an 74HC4040 (C44), DAT1-Pull-up R48, Montagelöcher im Schaltplan,
Silkscreen bereinigt.

## Umplatzierung (2026-09-27)

| Änderung | Grund |
|---|---|
| Pico 2,0 mm nach links | USB-Buchse ragte 1,6 mm über den Platinenrand. |
| Poti-Eingang nach links, OLED/Taster nach rechts | Poti-Leitungen liefen quer über die Platine durch den Digitalbereich; UI-Leitungen ebenso in Gegenrichtung. |
| Analogblock 2 mm nach rechts, In2-Insel verkleinert | Mehr Platz für die ADC-SPI-Leitungen an der digitalen Seite von U2; +3V3-Pads des LDO erreichen die +3V3-Ebene. |
| R34/R35 um 180° gedreht, R2 zum Pico, C26 zu D1/D_VSYS1 | Kürzere Wege für POT_EXC, ADC_CS und +VBAT_SW. |
| R49 (47k) an SD_DAT2 | DAT2 war offen. |
| Y1-3D-Modell SG210 (gleiches 2520-Gehäuse), U1 als Pico W | ECS-Modell fehlt in KiCad 10. |

Neu geroutet: Freerouting für die Digitalnetze (mit Sperrfläche über dem Analogblock), dann die Analognetze;
die lokalen Analogverbindungen um LDO/ADC/Opamp aus dem vorherigen Layout übernommen; Reste mit einem Rasterrouter.
Ergebnis: Leiterbahnlänge 2922 → 2597 mm, Vias 328 → 221; Poti-Analogpfade 350 → 272 mm, 34 → 14 Vias.

## Nacharbeit (2026-09-28)

| Änderung | Grund |
|---|---|
| J_SD1 0,35 mm nach links, 1,25 mm nach oben | Körper ragte 0,1 mm über die Kante; Abstand zu H4. |
| BT1 und BZ1 getauscht, BT1 bei (112,7 / 98,3) | Vor der Öffnung von BT1 lagen C26, R19–R21 u. a.: Die Zelle ließ sich nicht einschieben. Jetzt ist der Weg zum Pico frei. R29 sitzt am Pico-Pin. |
| C3 neben U2 Pin 18 (1,9 mm statt 5,4 mm) | CAP-Kondensator direkt am Pin. |
| C40 neben U_CLKBUF1 VCC (2,7 mm statt 6,8 mm), R39 auf den alten Platz von C40 | Abblockung direkt am IC. U_CLKBUF1 und C33 0,25 mm nach oben. |
| FB1, Y1, C19 von H3 weg; R49, R48 neu gesetzt | Schraubenkopf-Freiraum ≥ 3,5 mm. |
| Lader MCP73831 unter dem Pico, GP6 = CHG_STAT | Laden über USB (Plan „USB-Buchse für Laden + MSC“). Pico-Pin VBUS im Symbol als Power-Ausgang. |

Neu geroutet: alle Digitalnetze mit Freerouting (Sperrfläche über dem Analogblock), Reste mit Rasterrouter.
Keine Digitalleitung im Analogbereich. Leiterbahnlänge 2577 → 2633 mm (Lader +VBAT, 34 mm), Vias 223 → 221.

## Offene Punkte

- **microSD:** Eine gesteckte Karte ragt 5,2 mm über die Platinenkante (Push-Push, Karte zum Greifen). Gehäuse braucht an dieser Stelle einen Schlitz.
- **USB im Gehäuse:** Wasserdichte USB-C-Panelbuchse mit 5,1 kΩ an CC1/CC2 (sonst liefert ein C-auf-C-Netzteil keine Spannung), kurzes Kabel mit 90°-Micro-B-Stecker in den Pico. Seit 2026-10-03 liegen vor dem USB-Ende 7,4 mm Platine. Der Stecker ragt damit 7 mm weniger über die Kante (vorher 9 mm). Maß am Muster prüfen.
- **Lader im Gehäuse:** IC-Temperatur beim Laden (300 mA) im geschlossenen Gehäuse messen. Der Lader sitzt jetzt an der Oberkante mit Thermalfläche 0,77 cm². Wenn U_CHG1 trotzdem zu heiß wird (thermische Regelung senkt den Strom), R_PROG 5k (200 mA).
- **Akku-Polarität** am JST-PH prüfen: Pin 1 = Plus. Q_RP1 schützt bei Verpolung.
- **Gehäuse:** J_POT1 liegt jetzt am linken Rand, J_OLED1/SW_L1/SW_R1 am rechten Rand. Kabelwege im Gehäuse anpassen.
- **Autorouting prüfen:** Die Digitalnetze stammen aus Freerouting, einzelne Reste (IMU_CS0/CS1, SD_MISO/MOSI, +VBAT_SW) und die ADC-SPI-Leitungen am Pico-Ende (2026-09-30) aus einem Rasterrouter mit Glättung. Die Leitungen am Pico (2026-10-03) stammen aus einem Rasterrouter mit Rip-up, ohne Glättung. BTN_R hat 6 Vias. Elektrisch geprüft (DRC), Sichtprüfung im KiCad empfohlen.
- **Testpads Sichtprüfung:** Lage und Beschriftung (B-Seite) im KiCad prüfen. TP4–TP6, TP8–TP10, TP13, TP14 haben eine Via im Pad (offen, nicht bestückt, für Prüfspitzen unkritisch).
- **Soft-Power, Zustand nach Akku-Einstecken:** Laut MAX16150-Datenblatt (Rev 4) ist OUT nach dem ersten Anlegen von VCC nicht festgelegt („use PB_IN or CLR to set OUT“). Das Gerät kann beim Einstecken des Akkus einschalten. Die Firmware schaltet dann normal ab. Am Muster prüfen.
- **Fuel Gauge, Messpunkt:** U_FG1 misst an der +VBAT-Abzweigung ≈ 25 mm hinter Q_RP1, nicht mit eigener Leitung am Akku. Fehler ≈ (Q_RP1 ≈ 52 mΩ + Leiterzug ≈ 25 mΩ) × Laststrom: ≈ 10 mV bei 130 mA, ≈ 40 mV bei 0,5 A Spitze. ModelGauge glättet das. Der SOC unter Last ist etwas zu niedrig.
- **Teile unter dem Pico:** Sichtprüfung und Nacharbeit von U_PWR1, U_FG1 und den Kleinteilen nur ohne gesteckten Pico. Der Pico ist gesteckt, also lösbar.
- **Temperatur im Aus-Zustand:** Der Leckstrom von D_PWR1 steigt stark mit der Temperatur (≈ 1,5 µA bei 85 °C). Ab ≈ 80 °C (IR ≈ 1 µA, Pull-up bis 2,0 MΩ) kann PB_IN unter 0,3 × VCC fallen: Das Gerät schaltet von selbst ein. Die LiPo-Lagergrenze (60 °C) liegt darunter.
- **Gehäuse:** Externer Schalter entfällt. Die linke Panel-Taste (SW_L1) ist die Power-Taste.
- **Firmware:** Soft-Power und Fuel Gauge umsetzen (siehe „Firmware-Folgen“).
- **Firmware:** `PICO_BOARD pico_w` → `pico2_w` (`firmware/CMakeLists.txt`).

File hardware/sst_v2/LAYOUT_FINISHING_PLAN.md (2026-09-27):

# SST v2 — PCB Finishing-Plan

Erledigt. Das Layout Rev. 3 ist vollständig geroutet und DRC-sauber (Stand 2026-09-27).
Beschreibung, Prüfstand und offene Punkte: `README.md`.

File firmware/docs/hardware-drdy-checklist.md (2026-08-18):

# Hardware-Checkliste: DRDY-Verdrahtung + I²C-Pull-ups + AIN1-Abgriff

Umsetzung von AP1 aus [plan-drdy-resampling.md](plan-drdy-resampling.md), plus das,
was AP0 Test 2 physisch voraussetzt, plus der ratiometrische AIN1-Abgriff (eigenes
Thema, aber dasselbe offene Gehäuse). Parallel zur Software-Kette abarbeitbar.

**Abhängigkeit:** Phase A blockiert AP0 Test 2 (der Showstopper-Test zählt Flanken an
GP21/GP27 — ohne Drähte kein Test). Phase B und E sind unabhängig und jederzeit
möglich. Phase 0 muss vor allem anderen laufen.

## Material

| Menge | Teil |
|---|---|
| 4 | Widerstand 2,2 kΩ, 1/4 W (Wert unkritisch, 1,8–2,7 kΩ tut es auch) |
| 2 | Draht DRDY, so kurz wie möglich, AWG 26–30 |
| 2 | Draht GND für Verdrillung (optional, s. A4) |
| 2 | Draht AIN1-Abgriff (Phase E) |

Werkzeug: Lötkolben, Multimeter (Durchgang + Widerstand + DC-Spannung).
Kein Oszilloskop nötig — das macht der Pico in AP0 Test 2.

---

## Phase 0 — vor jedem Eingriff

- [ ] **0.1 Referenzaufnahme.** Ruheaufnahme bei stehendem Fahrwerk mit der
      **jetzigen** Firmware, Datei sichern und eindeutig benennen
      (`ref-vor-drdy.SST`). Ohne sie fehlt in AP8.3 der Vergleich für den
      ~28-Hz-Buckel im Differenzenquotienten — nachträglich nicht mehr herstellbar.
- [ ] **0.2 Fotos vom offenen Gehäuse**, bevor irgendwas abgelötet/verlegt wird.
- [ ] **0.3 VDD-Check am ADS1115-Modul (Gate).** Gerät an, Multimeter zwischen
      Modul-`VDD` und `GND`.
      - **3,3 V → weiter.**
      - **5 V → STOP, nicht mit GP21/GP27 verbinden.** Der ALRT-Pull-up läge dann auf
        5 V und der RP2040 ist nicht 5-V-tolerant. (Sehr unwahrscheinlich: die
        Modul-Pull-ups auf SDA/SCL lägen dann ebenfalls auf 5 V und hätten den Pico
        längst beschädigt. Der Check kostet 10 s, also trotzdem machen.)
      - Beide Module einzeln prüfen.

---

## Phase A — DRDY-Verdrahtung (blockiert AP0 Test 2)

- [ ] **A1 ALRT-Pin identifizieren.** AZ-Delivery-Board, 10-poliger Header, von
      rechts: `VDD, GND, SCL, SDA, ADDR, ALRT, A0, A1, A2, A3`.
      → **ALRT = 6. von rechts, sitzt zwischen `ADDR` und `A0`.**
      Nichts nachrüsten: Pull-up (10 kΩ) ist bestückt und gemessen (AP0).
- [ ] **A2 Fork-Modul `ALRT` → Pico `GP21`** (Header-Pin **27**).
- [ ] **A3 Shock-Modul `ALRT` → Pico `GP27`** (Header-Pin **32**).
      Zuordnung nicht vertauschen — die Intervall-Gate-Schwellen in AP3 sind
      kanalindividuell (Fork ~832 SPS, Shock ~850–859 SPS).
- [ ] **A4 Verlegung — die eigentliche Maßnahme.** Beide Drähte **weg von der
      SD-Verdrahtung GP16–19** (6,75 MHz, burstartig 8 KB alle ~2,4 s → garantiert
      gleichzeitig mit DRDY-Kanten). Die ALRT-Leitung ist mit 10 kΩ hochimpedant, eine
      eingekoppelte falsche fallende Flanke erzeugt ein Phantom-Sample.
      - Nicht parallel zu den SD-Drähten führen; wenn kreuzen, dann im 90°-Winkel.
      - Am Header ist der Abstand unvermeidbar klein (GP19 = Pin 25, GP21 = Pin 27).
        Das ist unkritisch — es geht um die Strecke, nicht um den letzten Zentimeter.
      - Optional, billig, wirksam: jeden DRDY-Draht mit einem GND-Draht verdrillen,
        GND an Pin **28** (nicht Pin 33 = AGND, die soll ruhig bleiben — dort hängt
        die VSYS-Messung mit dran).
- [ ] **A5 Kein Kondensator, kein Serienwiderstand** an DRDY. Filter verschmieren den
      Zeitstempel; Entstörung passiert über das Software-Intervall-Gate (AP3).
      Ausnahme s. „Reserve" unten.

**Danach ist AP0 Test 2 fahrbar.** Erwartung dort: ~8320 Counts (Fork) /
~8500–8590 (Shock) in 10 s, Puls ~8 µs, aktiv low.

---

## Phase B — I²C-Pull-ups (unabhängig, jederzeit)

Grund: der Bus läuft heute mit 1 MHz an 8,5 kΩ (10 kΩ Modul ∥ ~56 kΩ Pico intern)
→ t_r ≈ 216 ns gegen 120 ns Spec. Läuft, aber ohne Marge. Erklärt jedes
`i2c_err_count > 0` in AP8.

- [ ] **B1 Vorher-Messung** (Gerät **aus**), je Bus zwischen SDA und 3V3:
      Erwartung **~10 kΩ**. Bestätigt, dass Modul-Pull-up und 3V3-Rail derselbe Netz
      sind wie gedacht. Gleiches für SCL.
- [ ] **B2 Fork-Bus (i2c0):** 2,2 kΩ von **GP8/SDA** (Pin 11) nach 3V3,
      2,2 kΩ von **GP9/SCL** (Pin 12) nach 3V3.
- [ ] **B3 Shock-Bus (i2c1):** 2,2 kΩ von **GP14/SDA** (Pin 19) nach 3V3,
      2,2 kΩ von **GP15/SCL** (Pin 20) nach 3V3.
- [ ] **B4 Einbauort.** Der Plan sagt Pico-Seite; bei ~10 cm board-to-board und ~30 pF
      ist das elektrisch gleichwertig — also dort löten, wo es mechanisch am besten
      passt. Praktischster 3V3-Abgriff ist die **`VDD`-Pin des jeweiligen Moduls**
      (kommt ohnehin vom Pico-3V3, Pin 36 liegt auf der falschen Seite des Headers).
      Widerstände dann direkt am Modul-Header zwischen `VDD` und `SDA`/`SCL`.
- [ ] **B5 Nachher-Messung** (Gerät aus), gleiche Punkte: Erwartung **~1,8 kΩ**
      (2,2 k ∥ 10 k = 1803 Ω).
      - ~10 kΩ → Widerstand hängt nicht am richtigen Netz.
      - ~2,2 kΩ → Modul-Pull-up fehlt entgegen AP0, nachprüfen.
      - < 100 Ω → Kurzschluss, nicht einschalten.
- [ ] **B6 Nichts auslöten.** Die 10 kΩ auf den Modulen bleiben.

Senkstrom pro Leitung danach 1,83 mA — innerhalb der 3 mA des ADS1115.

**Software-Gegenstück** (macht die SW-Kette, nicht du): Baudrate 1 MHz → 400 kHz in
`linear_ads1115.c:94`. Kostet nichts, weil in Continuous Mode pro DRDY nur ein
2-Byte-Read bleibt (75 µs statt 30 µs, Budget sind 1,2 ms).

---

## Phase C — vor dem ersten Einschalten

- [ ] **C1 Durchgang** ALRT-Fork ↔ GP21, ALRT-Shock ↔ GP27.
- [ ] **C2 Kein Schluss** GP21 ↔ GND, GP21 ↔ 3V3, dito GP27; und keiner der beiden
      gegen die Nachbarpins (GP20 Pin 26, GP22 Pin 29, GP26 Pin 31, GP28 Pin 34).
- [ ] **C3 Kein Schluss** SDA ↔ SCL auf beiden Bussen (Lötbrücke am Modul-Header ist
      der wahrscheinlichste Fehler bei B4).
- [x] **C3b Kein Schluss** `A1` ↔ `A0` und `A1` ↔ `ADDR` (Phase E, Nachbarpins auf
      demselben Header). Ein Schluss A1↔A0 legt die Schleiferleitung auf die Speisung
      und sieht in den Daten wie Dauer-Vollausschlag aus.
- [ ] **C4 Zugentlastung/Fixierung** der neuen Drähte, das Gerät wird bewegt.

## Phase D — nach dem Einschalten, noch mit alter Firmware

- [ ] **D1 ALRT-Ruhepegel.** Multimeter DC an GP21 bzw. GP27 gegen GND:
      **~3,3 V, stabil.** Die alte Firmware lässt `COMP_QUE = QUE_DISABLE`, der
      ALERT-Ausgang ist hochohmig → der Pull-up hält high. Belegt Draht + Pull-up.
      Ein Wert um 0 V oder schwankend = Verdrahtungsfehler.
- [ ] **D2 Normale Aufnahme fahren**, prüfen dass beide Kanäle weiter sauber messen.
      Die Pull-ups können den Bus nicht verschlechtern (nur t_r verkürzen); wenn hier
      etwas kaputt ist, ist es die Verdrahtung, nicht das Konzept.
- [ ] **D3 Gehäuse zu**, aber erst nachdem AP0 Test 2 durch ist — sonst öffnest du
      zweimal.

---

## Phase E — ratiometrischer AIN1-Abgriff (unabhängig)

Eigenes Thema, nicht Teil des DRDY-Plans: die Poti-Speisung wird gemessen statt
angenommen (heute implizit 3,300 V in `resolution: 14.6883`). Zielt auf
**Reproduzierbarkeit** — Speisungsdrift mit Akku und Temperatur wirkt zwischen *und
innerhalb* von Sessions, 1 % = 2,0 mm am 200-mm-Fork. AIN1–AIN3 sind an beiden
Modulen frei.

- [x] **E1 Vorbedingung prüfen (Gate).** DMM Durchgang, Gerät aus: Poti-Klemme „+" am
      Stecker ↔ ADS1115-`VDD` müssen **dasselbe Netz** sein.
      **Poti an 5 V / VSYS ⇒ nicht anschließen** — abs. max. Analogeingang ist
      VDD + 0,3 V. Beide Kanäle einzeln prüfen.
- [x] **E2 A1-Pin identifizieren.** Selbe Pinreihe wie A1 in Phase A, von rechts:
      `VDD, GND, SCL, SDA, ADDR, ALRT, A0, A1, A2, A3`
      → **A1 = 8. von rechts = 3. von links, sitzt zwischen `A0` und `A2`.**
- [x] **E3 Fliegender Draht pro Modul: Poti-„+"-Pin → Modul-`A1`.**
      **Am Stecker abgreifen, nicht irgendwo am 3V3-Netz.** Falls Schutzwiderstand,
      Diode oder Abschalt-FET in Reihe liegt, muss der Abgriff **dahinter** sitzen —
      sonst misst A1 eine andere Spannung als das Poti sieht und der ganze Zweck ist
      weg.
- [x] **E4 Kein Teiler, kein RC, kein Serien-R** — weder auf A1 noch auf A0.
      (Begründung bei A0: ein C auf der Schleiferleitung reißt die Wiper-Stromgrenze
      des ELPM75 und macht den Quellwiderstand positionsabhängig.)
- [x] **E5 Zwischenprüfung ohne Firmware.** DMM DC zwischen Modul-`A1` und Modul-`GND`,
      Gerät an: muss gleich der VDD-Messung aus 0.3 sein (~3,3 V). Abweichung ⇒
      falscher Abgriffspunkt.
- [x] **E6 Abnahme mit Firmware-Support.** A1 muss **26400 counts** lesen
      (3,3/4,096 × 32768 = exakt 26400,0), Fenster **25600–27200**.
      - **32767 → falsche Schiene, sofort trennen.**
      - ~0 → nicht kontaktiert.
      - Wert **nicht als Voltmeter lesen** — er trägt den ADC-Gain-Fehler. Genau ist
        nur das Verhältnis `c_wiper / c_exc`, und genau darin kürzen sich Speisung
        und Gain weg.

> **Phase E abgenommen am 2026-08-18 (Commit `8776e8c`).** Beide Module: Draht
> A1 → Modul-`VDD` gelötet. Firmware-Support umgesetzt in
> `linear_ads1115.c` (c_exc-Messung via MUX SINGLE_1, ratiometrische
> Normalisierung `raw · 26400 / c_exc`, Pointer-Restore auf 0x00) und
> `main.c` (c_exc-Anzeige `CEXC F/S` nach CAL EXP). E6 auf Hardware:
> beide Kanäle im Fenster 25600–27200. Beide Kollisionen mit dem DRDY-Plan
> gelöst: c_exc-Messung in `start()` vor dem DRDY-Arm, Pointer nach jedem
> MUX-Wechsel explizit zurückgesetzt.

**Kein Format-Impact:** `baseline_norm = c_w0 · 26400 / c_exc` passt in dasselbe
`uint16_t` ⇒ CALIBRATION-Datei, `struct record`, `struct header` und der App-Faktor
`200 mm / 2^14,6883` bleiben unverändert. Kein Bump, kein Reprocessing.

### Zwei Kollisionen mit dem DRDY-Plan (für die Software-Kette)

Beides fällt erst auf, wenn beide Änderungen zusammen laufen:

1. **Reihenfolge in `on_rec_start`.** Die `c_exc`-Messung braucht einen MUX-Wechsel
   auf `MUX_SINGLE_1`; mit `COMP_QUE = QUE_1` und den AP2-Thresholds feuert ALERT
   **kanalunabhängig bei jeder Wandlung** — also auch bei den AIN1-Wandlungen. Die
   `c_exc`-Messung muss daher **vor** dem Scharfschalten der DRDY-IRQs und vor dem
   Ring-Vorfüllen (AP5) liegen, sonst landen Speisungswerte als Stützstellen im Ring.
   Symmetrisch in `on_rec_stop`: erst IRQs aus, dann optional messen.
2. **AP2-Pointer-Invariante.** AP2 eliminiert den Pointer-Write pro Read und setzt
   voraus, dass **kein anderer Pfad den Pointer bewegt**. Ein MUX-Wechsel ist ein
   Config-Write auf Pointer 0x01 — verletzt die Invariante. Nach jeder `c_exc`-Messung
   (in `on_rec_start`, `on_rec_stop` **und** in `calibrate_expanded`) muss der Pointer
   explizit auf 0x00 zurückgesetzt werden. Der Plan listet `calibrate_expanded` heute
   als „sicher"; mit Phase E stimmt das nicht mehr.

Ferner unverändert aus dem Rezept: **gleiche PGA** (`ADS1115_PGA_4_096`) für beide
Messungen, sonst kürzt sich der Gain-Fehler nicht mehr weg. Nach MUX-Wechsel erstes
Ergebnis verwerfen und ≥ 2,4 ms warten. `c_exc == 0` oder außerhalb 20000–30000 ⇒
Rückfall auf 26400. **Baseline-Normalisierung ist Pflicht**, nicht optional — ohne sie
tauscht man Skalen- gegen Offsetfehler, und Offset ist beim absoluten Federweg
schlimmer.

---

## Reserve — nur falls `glitch_count ≠ 0` in AP8

Erst dann, nicht vorbeugend: **100 pF von DRDY nach GND**, am Pico-Ende. Die fallende
Flanke wird vom Open-Drain hart getrieben (Entladung ~0,3 µs bei 1 mA), die Verzögerung
ist damit **konstant und auf beiden Kanälen gleich** → kein Skew, kein zusätzlicher
Jitter. Gegen kapazitive Einkopplung aus der SD-SPI wirkt es sofort. Vorher aber
Verlegung nachbessern (A4) — das ist die billigere Maßnahme.

## Was nicht zu tun ist

- Modul-Pull-ups (die vier „103") **nicht** auslöten.
- **Kein C auf der Schleiferleitung** der Potis — bei 2 m/s zieht schon 100 nF ~3,3 µA,
  dieselbe Größenordnung wie die 10-µA-Grenze des ELPM75, und der Quellwiderstand des
  Potis ist positionsabhängig.
- **GP26 nicht** als DRDY verwenden: Slice 5 **Kanal A**, kann keine Flanken zählen,
  und läge auf demselben Slice wie GP27.
- GP13 wäre die einzige Alternative (Slice 6B), kollidiert aber mit dem
  SPI-Display-Build.
- ADDR-Pins nicht anfassen, beide Module bleiben auf 0x48 (getrennte Busse).

## Reihenfolge am Basteltisch

Gehäuse geht genau einmal auf. Löten in einem Rutsch: Phase A (DRDY) + Phase B
(Pull-ups) + Phase E (AIN1). Prüfen in Phase C/D. Erst danach zu — und erst nachdem
AP0 Test 2 durch ist.

Isolierbar bleibt es trotzdem: die Pull-ups können einen laufenden 1-MHz-Bus nicht
verschlechtern (sie verkürzen nur t_r), und der AIN1-Draht ist ohne Firmware-Support
elektrisch wirkungslos. Wenn nach dem Zusammenbau etwas nicht geht, ist es die
Verdrahtung, nicht eine der drei Änderungen an sich.

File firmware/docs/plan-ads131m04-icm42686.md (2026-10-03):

# Plan: ADS131M04 + 4× ICM-42686-P — Rev. 3

Stand 2026-09-04. Ersetzt Rev. 2 (ADS131M02 + 4× MPU6050). Branch
`claude/upgrade-adc-sensor-wGFyG`. Datenblätter unter `firmware/docs/`.

## 0. Was sich gegenüber Rev. 2 ändert und warum

| Rev. 2 | Rev. 3 | Grund (Quelle) |
|---|---|---|
| ADS131M02, 2 Kanäle | **ADS131M04, 3 von 4 Kanälen** (Fork, Shock, Speisung) | Phase E (Commit 8776e8c) misst die Poti-Speisung und normalisiert ratiometrisch (`linear_ads1115.c:250`). Der M02 hat keinen Kanal dafür übrig. |
| Serienwiderstand in der Pot-Speisung, 1,15 V Vollhub | **Gepufferte 1,0-V-Speisung** aus 3V3-Teiler mit RC und Opamp | Pot-Toleranz ±20 % hätte den 1,2-V-FSR überschritten; Ripple des RT6154 (PFM) geht sonst 1:1 ein. |
| 1 kΩ + 100 nF am Schleifer | **Schleifer-Puffer (Opamp), RC erst dahinter** | `hardware-drdy-checklist.md:215`: kein C auf der Schleiferleitung, ELPM75-Schleiferstrom ≤ 10 µA. ADS131M04 hat bei Gain 1 nur 330 kΩ Eingangsimpedanz (SBAS890D Tab. 6.5, Gl. 4), das ergäbe bis 0,75 % positionsabhängigen Fehler. |
| 4× MPU6050 an I2C, 400 kHz, freilaufender Takt | **4× ICM-42686-P an SPI, CLKIN 32 kHz aus dem ADC-Takt** | MPU6050: ±16 g, kein Taktanschluss, I2C über 1 m Kabel. Vorgaben aus dem Interview: ≥ 32 g, harter Sync < 1 ms, Kabel bis 1 m. |
| TCXO ±25 ppm | **CMOS-Oszillator 8,192 MHz** (XO, ±50 ppm reicht) | ADS131M04 hat keinen Quarztreiber (kein XTAL2-Pin, SBAS890D Abschnitt 5), braucht LVCMOS-Takt. Genauigkeit ist egal, alle Raten hängen am selben Takt. |
| MPU-INT je Bus auf einem GPIO | **entfällt** | Zwei Push-Pull-INT auf einer Leitung wären ein Kurzschluss. FIFO wird gepollt, Rate ist durch CLKIN bekannt. |
| 2,2-kΩ-I2C-Pull-ups bleiben | **entfallen** (beide I2C-Blöcke ungenutzt) | Kein I2C-Sensor mehr. |

Gescheiterte Alternative, dokumentiert damit sie nicht wieder aufkommt:
**ICM-45686** (AN-000478 Kap. 7): CLKIN 20–40 kHz, ODR skaliert mit
fCLKIN/32 kHz, ODR-Liste ohne 1000 Hz (800/1600). 1000 Hz bräuchten 20 kHz
oder 40 kHz CLKIN; 8,192 MHz / 20 kHz = 409,6 ist nicht ganzzahlig (Faktor 5
fehlt in 2^13·1000). Nur mit zweitem Takt-IC oder 8:5-Resampling lösbar.
Verworfen zugunsten des ICM-42686-P mit nativer 1-kHz-ODR.

## 1. Verifizierte Datenblattwerte

### ADS131M04 (TI SBAS890D, Mai 2021, `firmware/docs/ads131m04.pdf`)

| Punkt | Wert | Fundstelle |
|---|---|---|
| Gehäuse | TSSOP-20 (PW) oder WQFN-20 (RUK) | Abschn. 5 |
| TSSOP-Pins | 1 AVDD, 2 AGND, 3 AIN0P, 4 AIN0N, 5 AIN1N, 6 AIN1P, 7 AIN2P, 8 AIN2N, 9 AIN3N, 10 AIN3P, 11 SYNC/RESET, 12 CS, 13 DRDY, 14 SCLK, 15 DOUT, 16 DIN, 17 CLKIN, 18 CAP, 19 DGND, 20 DVDD | Fig. 5-2 |
| Takt | LVCMOS an CLKIN, **kein Quarzoszillator**; HR-Modus 0,3 bis 8,4 MHz, nominal 8,192 MHz; tw(CLH/CLL) ≥ 49 ns | Tab. 6.3, 6.6, Abschn. 8.3.x |
| Datenrate | fDATA = fCLKIN / 2 / OSR; OSR 4096 → **1000 SPS** | Tab. 8-3 |
| CLOCK-Register 0x03 | Reset 0x0F0E; Bit 11:8 CH3..CH0_EN, Bit 5 TBM, Bit 4:2 OSR (101b = 4096), Bit 1:0 PWR (10b = HR). Kein XTAL_DIS. | Tab. 8-17 |
| Frame | **immer 6 Wörter** (Status, CH0..CH3, CRC) = 18 Byte bei 24-bit-Wörtern, auch bei deaktivierten Kanälen; Ausgangs-CRC nicht abschaltbar | Abschn. 8.5.1.7, Z. 3063 |
| Eingang, Gain 1 | Absolutbereich AGND − 1,3 V bis AVDD; VIN ±1,2 V; **Differenz-Eingangsimpedanz 330 kΩ** (× 4,096 MHz / fMOD) | Tab. 6.3, 6.5, Gl. 4 |
| Referenz | intern 1,2 V, ±0,1 %, Drift 7,5 typ / 20 max ppm/°C | Tab. 6.5 |
| Rauschen | OSR 4096, Gain 1, HR: **3,38 µV rms**, 108 dB DR (19,4 ENOB) | Tab. 7-1, 7-2 |
| Reset | SYNC/RESET low ≥ **2048 tCLKIN** (250 µs) = Reset; 1 bis 2047 tCLKIN = nur SYNC; danach tREGACQ 5 µs | Tab. 6.6 |
| DRDY | DRDY_FMT = 0 (Pegel): geht bei ungelesenen Daten vor der nächsten Wandlung kurz high, es gibt also immer eine fallende Flanke. DRDY_FMT = 1 (Puls): ungelesene Daten lassen einen Puls ausfallen → **FMT = 0 verwenden** | Abschn. 8.5.1.5 |
| Lesezeitpunkt | Nicht lesen, während eine Wandlung fertig wird (DRDY-Puls wird sonst unterdrückt) → Frame direkt nach DRDY, dauert 18 B / 8 MHz ≈ 18 µs von 1000 µs | Z. 3572 |
| SPI | SCLK-Periode ≥ 40 ns bei DVDD 2,7–3,6 V (25 MHz); Mode 1 | Tab. 6.6 |
| CAP | 220 nF nach DGND (DVDD > 2,7 V) | Abschn. 10.1 |
| Abblockung | AVDD und DVDD je 1 µF direkt am Pin | Abschn. 10.3 |
| ID-Register | Reset 24xxh, CHANCNT = 4 | Abschn. 8.6.1 |

### ICM-45686 (nur zur Dokumentation der Ablehnung, AN-000478 Rev. 1.0)

CLKIN 20–40 kHz auf Pin 9 (geteilt mit INT2/FSYNC, `PADS_INT2_CFG_OVRD_VAL = 2`),
RTC_CONFIG 0x26 Bit 5 RTC_MODE, Bit 6 RTC_ALIGN (Phasen-Reset mehrerer Geräte),
FIFO 2 kB / 8 kB, Pakete 16 B oder 20 B (Hi-Res). ODR-Liste 6400 … 1,5625 Hz
in Zweierschritten, ohne 1000 Hz (TDK-Treiber `inv_imu_defs.h`, Zephyr
`dt-bindings/sensor/icm45686.h`).

### ICM-42686-P (TDK DS-000348, `firmware/docs/ds-000348-icm-42686-p-datasheet.pdf`)

| Punkt | Wert | Fundstelle |
|---|---|---|
| Gehäuse, Pins | LGA-14. 1 AP_SDO/AD0, 4 INT1, 5 VDDIO, 6 GND, 7 RESV→GND, 8 VDD, **9 INT2/FSYNC/CLKIN**, 11 RESV→GND, 12 AP_CS, 13 AP_SCLK, 14 AP_SDI; 2, 3, 10 RESV (NC oder GND) | Abschn. 4.1 |
| Bereiche | Accel ±32 g (1024 LSB/g, 16 bit) bis ±2 g; Gyro ±4000 dps bis ±31,25 dps | Tab. 1, 2 |
| Rauschen | Accel 70 µg/√Hz, Gyro 5,3 mdps/√Hz | Abschn. 1 |
| ODR | 32 k … 12,5 Hz in Zweierschritten plus 500 Hz, **1 kHz nativ**; mit CLKIN skaliert ODR um fCLKIN/32 kHz, bei 32,000 kHz exakt | Abschn. 12.5 |
| CLKIN | **31 bis 50 kHz** (Tab. 4 und Abschn. 3.7, Note 1: „expected results based on design"), tHIGH ≥ 1 µs; Genauigkeit ODR mit CLKIN ±50 ppm statt ±1 % (PLL) bzw. ±8 % (RC) | Tab. 4, Abschn. 3.7, 12.1 |
| CLKIN aktivieren | Bank 0 INTF_CONFIG1 (0x4D) Bit 2 RTC_MODE = 1; Bank 1 INTF_CONFIG5 (0x7B) Bit 2:1 PIN9_FUNCTION = 10b | Abschn. 12.5, 14/15 |
| Timestamp im RTC-Modus | TMST_RES = 0 (1 µs): Werte um 32,768/fRTC skalieren; bei 1 kHz und 32 kHz liest man 976/977 → 1000 µs | Abschn. 12.5 |
| FIFO | physisch 2048 B, Lesecache 2 Pakete, Treiberpuffer 2080 B; Pakete 16 B (Accel+Gyro+Temp+TMST) oder 20 B Hi-Res | Abschn. 6.1, 6.2 |
| Hi-Res (FIFO_HIRES_EN) | 19 bit Gyro, 18 bit Accel; **erzwingt ±32 g und ±4000 dps**, 4096 LSB/g und 65,5 LSB/dps | Abschn. 6.1 |
| INT-Pins | INT1/INT2 je Push-Pull oder Open-Drain | Abschn. 4.1 |
| SPI | 3- oder 4-Draht, SCLK ≤ 24 MHz, Mode 0/3 | Abschn. 9, Note 4 |
| Versorgung | VDD 1,71–3,6 V, VDDIO 1,71–3,6 V | Abschn. 1 |
| WHO_AM_I | 0x44 | Zephyr `icm4268x_reg.h` |

Zum Vergleich liegen ICM-42688-P (DS-000347) und ICM-45686 (DS-000577)
ebenfalls unter `firmware/docs/`.

### 74HC4040 (Nexperia Rev. 8, 2024)

fmax min 6 MHz bei 2,0 V, 30 MHz bei 4,5 V; bei 3,3 V interpoliert ≥ 15 MHz.
8,192 MHz am CP-Eingang ist sicher. Q7 (÷256, Pin 13) = **32,000 kHz**. Nexperia zählt ab Q0 = ÷2; Q8 wäre ÷512 = 16 kHz und läge unter dem CLKIN-Minimum 31 kHz.

## 2. Systemarchitektur

### 2.1 Taktbaum (ein Oszillator, alles phasenstarr)

```
XO 8,192 MHz (CMOS, 3,3 V)
 ├─ 33 Ω ─► ADS131M04 CLKIN      fMOD 4,096 MHz, OSR 4096 → 1000 SPS
 └─ 74HC4040 CP, Q7 = 32,000 kHz
      └─ 74LVC125 (4 Puffer, je 33 Ω) ─► 4× ICM-42686-P Pin 9 (CLKIN)
                                          RTC_MODE = 1, ODR 1000 Hz exakt
```

Beide Raten sind Ganzzahlteiler desselben Takts: ADC 8,192 M / 8192, IMU
32 k / 32. Frequenzdrift zwischen Poti- und IMU-Strom ist damit null.
Phasenversatz zwischen den IMUs ist konstant und kleiner als eine Periode; er
wird beim Aufnahmestart über TMST_STROBE je IMU gemessen und im Header
abgelegt (M5). Aktivierung je IMU: RTC_MODE (Bank 0, 0x4D Bit 2) und
PIN9_FUNCTION = CLKIN (Bank 1, 0x7B Bit 2:1). FIFO-Zeitstempel sind im
RTC-Modus um 32,768/32 zu skalieren (DS-000348 Abschn. 12.5).

### 2.2 Analog-Frontend (Potis)

```
3V3 ─ 23 kΩ ─┬─ 10 kΩ ─ GND        1,0 V Nennwert, RC mit 10 µF (fc ≈ 2 Hz)
             ├─ 10 µF ─ GND         filtert RT6154-PFM-Ripple
             └─►│+  OPA2333 A │──┬─► Pot-Speisung Fork (Kabel)
                └──────────────┘  ├─► Pot-Speisung Shock (Kabel)
                                  └─ 1 kΩ ─┬─ AIN2P (c_exc)   AIN2N ─ AGND
                                           └─ 10 nF ─ AGND

Schleifer Fork (Kabel) ─►│+  OPA2333 B │─ 1 kΩ ─┬─ AIN0P   AIN0N ─ Pot-GND-Ader Fork
                          └─────────────┘        └─ 10 nF ─ AGND
Schleifer Shock          ─► gleich mit OPA2333 C ─ AIN1P / AIN1N ─ Pot-GND-Ader Shock
```

- **Speisung 1,0 V**: 17 % Headroom zu 1,2 V FSR, unabhängig vom
  Poti-Widerstand (Fork VLP 200 mm und Shock ELPM75 haben verschiedene Werte).
- **Schleifer-Puffer**: Schleiferstrom = Opamp-Biasstrom (pA) plus
  Kabelkapazität (≈ 3 nA bei 2 m/s), weit unter den 10 µA des ELPM75. Die
  330 kΩ des ADC belasten nur noch den Opamp-Ausgang.
- **RC 1 kΩ + 10 nF hinter dem Puffer** (fc 16 kHz): Kickback-Reservoir für
  den Switched-Cap-Eingang, kein Anti-Alias im Nutzband. Der Serien-R ergibt
  mit 330 kΩ 0,3 % Gain-Fehler, identisch auf allen drei Kanälen → kürzt sich
  in `raw · 26400 / c_exc`.
- **Opamp-Wahl**: RRIO, Ib ≤ 100 pA, VOL bei µA-Last < 1 mV. Kandidaten
  OPA2333/TLV2333 (Zero-Drift, 10 µV Offset) oder MCP6004 (Budget, 4,5 mV
  Offset, wird per Baseline kalibriert). Vierfach-Opamp deckt alle drei
  Kanäle ab.
- **Remote Sense**: AINxN auf die Pot-GND-Ader am Stecker, nicht auf AGND.
  Kompensiert den Masseversatz im Kabel. Eingangsbereich AGND − 1,3 V lässt
  das zu.
- **Skalierung**: `value16 = raw_wiper · 26400 / raw_exc`, Vollhub = 26400
  counts wie beim ADS1115 (Phase E). Rauschen: 3,38 µV rms auf 37,9 µV/count
  → 0,09 counts rms (ADS1115: ≈ 1 count).
- **Schutz**: 1 kΩ Serien-R vor jedem Opamp-Eingang plus ESD-Diode (z. B.
  PESD3V3) an den Kabel-Eingängen.

### 2.3 IMU-Bus (SPI-Stern, 4 Knoten, je 1 m Kabel)

- Pico → PIO-SPI (PIO1, 1 SM, Mode 0, **2 MHz**, DMA über DREQ_PIO1_TX/RX).
  Hardware-SPI1 bleibt beim ADS131M04 (bestehender Treiber).
- Gemeinsam: SCLK, MOSI, MISO, CLKIN, 3V3, GND. Je Knoten: CS.
- Kabel je IMU-Paar 11 Adern + Schirm auf einem 12-poligen Stecker (2.6). Serien-R 33 Ω an
  allen Treiberausgängen auf dem DAQ, 33 Ω an MISO auf jeder Sensor-PCB.
- Sensor-PCB: ICM-42686-P (LGA-14), 100 nF + 1 µF an VDD, 100 nF an VDDIO,
  33 Ω an MISO, 10 kΩ Pull-up an CS (Bus bleibt definiert, wenn der Knoten
  fehlt). Footprint für KX134-1211 (±64 g) vorsehen, nicht bestücken.
- Datenrate: 4 × 1000 × 20 B = 80 kB/s (Hi-Res) bzw. 64 kB/s (16 bit).
  Bei 2 MHz SCLK ≈ 32 % Busauslastung. Burst alle 50 ms je IMU: 50 Pakete =
  1000 B, FIFO 2 kB → 50 ms Reserve gegen Scheduler-Verspätung.
- Bei Fehlern am Aufbau (Reflexionen, Übersprechen): erst SCLK auf 1 MHz
  und Slew-Rate-Limit (RP2040 `gpio_set_slew_rate`), dann Kabel.

### 2.4 Pin-Map Pico W (SPI_MICROSD = ON, I2C-Display)

| GPIO | Funktion | Anmerkung |
|---|---|---|
| 0, 1 | UART debug | unverändert |
| 2, 3 | PIO0 I2C (RTC, OLED, Fuel Gauge MAX17048 0x36) | Fuel Gauge ab Rev. 3 (2026-10-03) |
| 4, 5 | Buttons | GP4 (BTN_L) zusätzlich Power-Taste über D_PWR1 an MAX16150 PB_IN; > 8 s halten = Hardware-Aus |
| 6 | CHG_STAT (Lader U_CHG1 MCP73831) | Input. Teiler 10k/10k (max. 2,6 V bei VBUS 5,25 V): Laden = 0, fertig = 1. Nur bei VBUS auswerten (ohne VBUS hochohmig → 0). Im SPI-Display-Build belegt Display-RST den Pin. |
| 7 | ADS131 SYNC/RESET | Output über R50 100 Ω in Serie (Netz ADC_RST_MCU → ADC_RST), 10 kΩ Pull-up am ADC |
| 8 | IMU SCLK (PIO1) | |
| 9 | IMU MOSI (PIO1) | |
| 10 | ADS131 SCLK (SPI1) | |
| 11 | ADS131 DIN (SPI1 TX) | |
| 12 | ADS131 DOUT (SPI1 RX) | |
| 13 | ADS131 CS | GPIO, 10 kΩ Pull-up |
| 14 | IMU MISO (PIO1) | |
| 15 | IMU CS0 | |
| 16–19 | SPI0 MicroSD | unverändert |
| 20 | ADS131 DRDY | Input, Raw-IRQ, fallende Flanke |
| 21 | IMU CS1 | (im ADS1115-Build: Fork-DRDY) |
| 22 | Buzzer | unverändert |
| 26 | IMU CS2 | |
| 27 | IMU CS3 | (im ADS1115-Build: Shock-DRDY) |
| 28 | PWR_OFF (Soft-Power) | Output, aktiv high: Q_PWR3 zieht MAX16150 ~CLR low → Gerät aus. Beim Start sofort low (R_PWR4 100k Pull-down). Siehe `hardware/sst_v2/README.md` (Rev. 3, 2026-10-03). |
| 29 | VSYS/3 | unverändert |

`SPI_DISPLAY` kollidiert mit GPIO 10–13 → `#error` bleibt.

### 2.5 DMA und IRQ

| Ressource | Nutzer |
|---|---|
| DMA-Kanäle | ADS131: TX + RX (SPI1), IRQ auf DMA_IRQ_0. IMU: TX + RX (PIO1), ohne IRQ, Completion gepollt. SD-Lib: DMA_IRQ_1 (`.DMA_IRQ_num`). cyw43: eigene. |
| GPIO-IRQ | DRDY über `gpio_add_raw_irq_handler`, koexistiert mit Pushbutton-Callback |
| PIO | PIO0 SM0: I2C. PIO1: cyw43 (1 SM) + IMU-SPI (1 SM). |
| Core 0 | DRDY-ISR → DMA-ISR (Poti-Sample in Puffer), IMU-Burst-Scheduler im RECORD-Handler |
| Core 1 | SD-Writes (unverändert), zusätzlich IMU-Blöcke (M5) |

Poti-Pfad läuft komplett in ISRs und wird von nichts blockiert. IMU-Pfad
läuft ohne IRQ per DMA, Polling im 50-ms-Raster.

### 2.6 Steckverbinder

Vorgaben: mindestens IP65, Ziel IP67. Fork und Shock auf einem gemeinsamen
Stecker, je zwei IMUs auf einem gemeinsamen Stecker, damit modular nur mit
Potis oder mit Potis plus zwei IMUs gemessen werden kann. Einbaubuchse am
Gehaeuse, kein Pigtail. Mindestens 1000 Steckzyklen. Budget bis 40 EUR je
Verbindungspunkt. Loetkelch, kein Crimpwerkzeug. Kein Stecken unter Spannung.

**Gewaehlt: Hirose HR30**, gedichteter Push-Pull-Rundsteckverbinder aus PPS.
Alle Werte unten aus `firmware/docs/HR30_Catalog_en_HR30_CAT.pdf`
(Ausgabe Okt. 2025).

| Kriterium | 6-polig (Schale 6) | 12-polig (Schale 7/8) |
|---|---|---|
| Schutzart | IPX7 gesteckt (1 m, 30 min), IPX8 (2 m, 14 d) gesteckt oder mit Kappe | dito |
| Steckzyklen | 1000, danach Kontaktwiderstand ≤ 30 mΩ (Loettyp) | dito |
| Kontaktwiderstand neu | ≤ 30 mΩ (Loettyp), ≤ 15 mΩ (Crimp) | dito |
| Nennwerte | 2 A, 100 V AC / 140 V DC | 2 A, 30 V AC / 42 V DC |
| Temperatur | −25 bis +85 °C Betrieb, −10 bis +60 °C Lagerung | dito |
| Flansch aussen | ø 12 mm, Sechskant SW 10 | ø 15 mm, SW 13 |
| **Panelbohrung** | **ø 8,05 mm +0,05** mit Flaeche, Gewinde M8 × 0,75 | **ø 11,05 mm +0,05**, M11 × 1 |
| **Panelstaerke** | **0,7 bis 2,0 mm** | **0,7 bis 3,0 mm** |
| Anzugsmoment | 0,5 Nm | 0,8 Nm |
| Bauhoehe gesteckt ab Panel | 32,3 mm | 42,1 mm |
| Kabeldurchmesser | ø 4,2 bis 5,0 mm (Standard), ø 3,5 bis 4,3 mm (Variante PA) | ø 6,2 bis 7,0 mm |
| Loetkelch innen | ø 0,8 mm | ø 0,6 mm |
| Gewicht Paar | 6 g | 9 g |
| UV | 2000 h Sonnenlichtbewitterung bestanden | dito |

Verworfen:

- **M8 und M12** (auch das heutige Lutronic 1220): nach IEC 61076-2-101/-104
  typisch 100 bis 500 Steckzyklen, Schraubverriegelung ist am Rad
  unpraktisch. Verfehlt die 1000er-Vorgabe.
- **binder 720 / M9 IP67**: kompakt und guenstig, aber nur "mehr als 500"
  Steckzyklen.
- **Fischer MiniMax 06** (ø 10 mm, bis 12 Kontakte, IP68, > 5000 Zyklen,
  360°-Schirmung) und **ODU MINI-SNAP**: technisch besser und kleiner, aber
  weit ueber Budget und meist crimppflichtig. Ausweichoption, falls der
  Bauraum die 12-poligen HR30 nicht hergibt.

#### Bestellnummern (Loettyp, Buchsenkontakte am Gehaeuse)

Paarungsregel des Katalogs: gleiche Schalengroesse, gleiche Polzahl, und zu
einem Stecker mit Stiftkontakten gehoert eine Buchse mit Buchsenkontakten.
Bei 12 Polen kodiert die Schalengroesse das Geschlecht, Schale 8 fuehrt
Buchsenkontakte in der Einbaubuchse.

| Position | Poti (6-polig) | IMU-Paar (12-polig), 2× |
|---|---|---|
| Einbaubuchse Gehaeuse | HR30-6R-6S(71) | HR30-8R-12S(31) |
| Kabelstecker | HR30-6P-6P(31), ø 4,2–5,0 mm | HR30-8P-12P(71), ø 6,2–7,0 mm |
| Kabelstecker duenn | HR30-6PA-6P(71), ø 3,5–4,3 mm | — |
| Kappe Einbaubuchse | HR30-6R-C(31) | HR30-7R-C(31) (passt auf 7R und 8R) |
| Kappe Kabelstecker | HR30-6P-C(31) | HR30-8P-C(31) |
| Loethilfe | HR30-6R-6S-T01, HR30-6P-6P-T01 | — (nur fuer Crimptypen gelistet) |
| Klemmzange Kabelklemme | HR30-6P-T02 | HR30-8P-T02 |

Preis rund 8 USD je Haelfte, also etwa 20 EUR je Verbindungspunkt inklusive
Kappe. Die beiden Klemmzangen sind Einmalkosten und **nicht optional**: sie
stellen das vorgeschriebene Moment an der Kabelklemme her, von dem die
Dichtigkeit abhaengt.

#### Poti-Stecker: HR30, 6-polig

| Kontakt | Signal |
|---|---|
| 1 | Speisung 1,0 V (gemeinsam fuer beide Potis) |
| 2 | Schleifer Fork → AIN0P |
| 3 | Poti-Masse Fork → AIN0N |
| 4 | Schleifer Shock → AIN1P |
| 5 | Poti-Masse Shock → AIN1N |
| 6 | Schirm, nur DAQ-seitig auf AGND |

Kabel: drei verdrillte Paare unter gemeinsamem Schirm, Aussendurchmesser
ø 4,2 bis 5,0 mm. Paar 1 Schleifer Fork mit Poti-Masse Fork, Paar 2
Schleifer Shock mit Poti-Masse Shock, Paar 3 Speisung mit Schirmbeidraht.
Litze AWG 26, Leiterdurchmesser passt in den Loetkelch ø 0,8 mm.

Begruendung der Aderzahl: Die getrennten Masse-Rueckleitungen auf AIN0N und
AIN1N sind der eigentliche Genauigkeitsgewinn, denn sie nehmen Kabel- und
Kontaktwiderstand der Masse komplett aus der Messung. Eine zusaetzliche
Sense-Ader fuer die Speisung wurde geprueft und **verworfen**: bei 1,0 V an
zwei Potis fliessen zusammen unter 400 µA, ueber 1 m AWG 26 (0,14 Ω) plus
zwei Kontakte (2 × 30 mΩ aus der Steckzyklen-Pruefung) sind das 0,2 Ω und
damit 80 µV oder 80 ppm Verstaerkungsfehler. Auf 200 mm Hub entspricht das
0,016 mm und liegt zwei Groessenordnungen unter der Poti-Linearitaet. Der
sechste Kontakt bringt als Schirm mehr, weil die Schleiferleitung
ungepuffert mit bis zu 1,25 kΩ Quellwiderstand ueber 1 m neben den
IMU-Kabeln mit 2-MHz-SPI, dem Schaltregler und dem WLAN-Radio laeuft.

#### IMU-Paar-Stecker: HR30, 12-polig (2 Stueck)

| Kontakt | Signal |
|---|---|
| 1 | 3V3 |
| 2 | GND (Rueckleitung 3V3) |
| 3 | SCLK |
| 4 | GND (Paar zu SCLK) |
| 5 | MOSI |
| 6 | GND (Paar zu MOSI) |
| 7 | MISO |
| 8 | CLKIN |
| 9 | GND (Paar zu CLKIN) |
| 10 | CS_A |
| 11 | CS_B |
| 12 | Schirm, nur DAQ-seitig auf AGND |

Acht Signale waeren das Minimum; die vier freien Kontakte der 12-poligen
Schale gehen in dedizierte Rueckleitungen fuer SCLK, MOSI und CLKIN. Das ist
der Grund, 12-polig statt 10-polig zu nehmen — beide sitzen in derselben
Schale, die Mehrkontakte kosten keinen Bauraum. MISO teilt sich die
Rueckleitung mit CLKIN, weil MISO als einziges Signal vom Sensor getrieben
wird und nur waehrend des Bursts schaltet.

Kabel: 6 Paare geschirmt, Aussendurchmesser ø 6,2 bis 7,0 mm. Litze AWG 28,
damit der Leiter sicher in den Loetkelch ø 0,6 mm passt. Der Innenwiderstand
von 1 m AWG 28 liegt bei 0,22 Ω; bei 4 IMUs zu je 1 mA sind das 0,9 mV auf
der 3V3-Ader, unkritisch fuer VDD 1,71 bis 3,6 V des ICM-42686-P.

Der gemeinsame Bus (3V3, GND, SCLK, MOSI, MISO, CLKIN) liegt auf beiden
Steckern parallel. Ist nur ein Paar gesteckt, bleibt am zweiten Stecker ein
offener MISO-Stub von wenigen Zentimetern auf dem DAQ-Board; das ist
unkritisch. Die Pull-ups an CS auf den Sensor-PCBs halten den Bus auch bei
fehlendem Knoten definiert.

#### Randbedingungen fuer Gehaeuse und Aufbau

- **Panelstaerke 0,7 bis 3,0 mm** ist die harteste Vorgabe. Eine gefraeste
  oder gedruckte Wand ist meist dicker und braucht an der Bohrung eine
  Ansenkung auf 2 mm (6-polig) bzw. 3 mm (12-polig) auf mindestens
  Sechskant-Schluesselweite plus Dichtungsauflage.
- **Gehaeusekante**: Flansche ø 12 + 2 × ø 15 mm ergeben 42 mm, mit
  Schluesselflaechen und Steckabstand rund 50 mm. Panelbohrungen sind nur
  ø 8,05 und 2 × ø 11,05 mm.
- **Einbautiefe innen** etwa 8 mm (6-polig) bzw. 9 mm (12-polig) ab
  Panelinnenseite, plus Loetkelche und Zugentlastung der Litzen.
- **Nach aussen** ragt der gesteckte Verbinder 32,3 mm (Poti) bzw. 42,1 mm
  (IMU) ab Panelflaeche. Bei Montage am Flaschenhalter nach unten oder zum
  Rahmen hin ausrichten, damit nichts am Bein streift.
- **Kein Verguss hinter der Einbaubuchse.** Der Katalog verbietet Potting am
  Verdrahtungsbereich ausdruecklich: der O-Ring kann sich beim Abziehen des
  Steckers loesen, danach ist die Dichtigkeit hin.
- **Schutzkappen sind Pflicht**, nicht Zubehoer: im Poti-only-Betrieb sind
  beide IMU-Buchsen offen. Mit Kappe haelt HR30 IPX8. Dabei die
  mitgelieferte Dichtung der Buchse weglassen, die Kappe bringt ihre eigene
  mit.
- **Kein Stecken unter Spannung.** Der Katalog schreibt es selbst vor
  ("Turn off power to the circuit before connecting or disconnecting").
  Damit entfaellt jede Anforderung an eine Kontaktsequenz.
- **Steckkraft mindestens 30 N**, danach nicht mehr als 30 N Zug auf den
  gesteckten Verbinder. Das Kabel braucht am Rahmen eine eigene
  Zugentlastung, der Stecker ist keine.
- **Kabelaussendurchmesser muss im Fenster liegen**, sonst haelt weder
  Klemmung noch Dichtung. Vor der Bestellung des Kabels pruefen, notfalls
  auf die Variante HR30-6PA (ø 3,5–4,3 mm) ausweichen.
- **Schrumpfschlauch** ueber den Loetstellen nur mit gestecktem Gegenstueck
  erwaermen, sonst verformt sich der C-Ring der Verriegelung.

## 3. Meilensteine

Jeder Meilenstein baut und bootet für sich.

### M0 — Config-Plumbing

- `hardware_config.h`: `ADS131_SENSORS`-Block (SPI1, CS 13, DRDY 20, RESET 7,
  `#error` bei SPI_DISPLAY), `IMU_ICM42686`-Block (PIO1, SCLK 8, MOSI 9,
  MISO 14, CS 15/21/26/27).
- `CMakePresets.json`: Preset `spi_card-i2c_disp-ads131m04-icm42686`
  (+ `-debug`), `ADS131_SENSORS=ON`, `IMU_ICM42686=ON`.
- `CMakeLists.txt`: Flags, `hardware_spi hardware_dma hardware_pio`,
  Quellenauswahl. Vorlage: Diff des Branches `ads131m02-upgrade`.

### M1 — ADS131M04-Treiber, ratiometrisch

Basis: `linear_ads131m02.c` aus `ads131m02-upgrade` (Frame-Helfer,
Registerzugriff, DRDY→DMA-Kette, Standby/Wake). Änderungen:

- Frame 18 Byte (6 Wörter), CH0 = Fork, CH1 = Shock, CH2 = Speisung, CH3 aus.
  CLOCK = 0x0716 (CH2..0 an, OSR 4096, HR). MODE = 0x0110 (RESET-Flag
  gelöscht, 24 bit, DRDY_FMT 0). GAIN = 0. ID-Prüfung CHANCNT == 4.
- ISR: `raw_exc` mitlesen, `value16 = raw · 26400 / raw_exc` (Clamp
  `raw_exc` ≥ 2^20, sonst Kanal als fehlend markieren). Baseline-Abzug wie
  gehabt, 0xFFFE-Kappung, 0xFFFF reserviert.
- `check_availability()` ohne blockierende SPI-Zugriffe während des
  Samplings: Lebendigkeit aus dem Sample-Zähler (letztes DMA-Ende < 10 ms).
  Der alte Branch pausiert dafür den DRDY-IRQ; das kostet je Aufruf ein
  Sample und entfällt.
- `last_c_exc()`-Getter für die CEXC-Anzeige in `on_cal_exp` (heute
  `linear_sensor_ads1115_last_c_exc`, `main.c:131`), gleiche Signatur.
- Reset ≥ 300 µs low, danach 10 µs, dann Konfiguration.
- main.c gegen den heutigen Stand: Alarm-Callback `data_acquisition_cb`
  (`main.c:251`) unter `#ifndef ADS131_SENSORS`, `ads131_begin/end` in
  `on_rec_start`/`on_rec_stop`, `SAMPLE_RATE` → `ads131_sample_rate()`,
  Standby/Wake in `on_sleep`/`on_waking`. CAL-Magic `'C','A','L',2` wie im
  alten Branch, gilt für alle Builds.
- CMake: `sst.h`-as5600-Guard und Link-Bedingung um `ADS131_SENSORS`
  erweitern.

Verifikation: DRDY-Periode 1,000 ms; Frame 18 B; 10-min-Aufnahme
`(size − 16) / 4 = 600000 ± 1`; CEXC-Anzeige ≈ 26400 ± 3 % (Fenster wie
Phase E E6); Vergleich mit ADS1115-Board: Zählweite gleich; Sleep/Wake ohne
Sofort-Aufwachen.

### M2 — Analog-Bringup (Hardware, kein Code)

Opamp-Board mit Speisung und Pufferung, Remote Sense, ESD. Messpunkte:
Speisung 1,00 V ± 2 %, Ripple < 1 mV bei PFM-Betrieb (Aufnahme aus,
`SMPS_FORCE_PWM` low), Schleifer-Puffer-Offset < 1 mV bei Pot am Anschlag,
Rauschen im Stillstand < 0,5 counts rms.

### M3 — ICM-42686-P: Treiber, PIO-SPI, CLKIN, 1 kHz, RAM-Ring

- `firmware/src/sensor/icm42686.c/.h` (neu, ~500 LOC), PIO-SPI-Programm
  (`pio_spi` aus pico-examples, CPHA 0) mit DMA-Helfern.
- Init je IMU: WHO_AM_I == 0x44, Soft-Reset, Bank 1 INTF_CONFIG5
  PIN9_FUNCTION = 10b (CLKIN), Bank 0 INTF_CONFIG1 RTC_MODE = 1, ODR 1 kHz
  für Accel und Gyro, AAF laut Datenblatt, FIFO Stream + TMST +
  FIFO_HIRES_EN. Hi-Res legt ±32 g und ±4000 dps fest (4096 LSB/g,
  65,5 LSB/dps), die FS-Register sind dann ohne Wirkung. Nicht antwortende
  IMUs: `available = false`.
- Scheduler auf Core 0 im RECORD-Handler (`state_handlers[RECORD]`, heute
  `dummy`, `main.c:936`): alle 50 ms je IMU FIFO_COUNT lesen (kurz,
  blockierend), Burst per DMA, nächste IMU nach Completion. Overflow-Bit
  prüfen, Zähler.
- **Clip-Zähler** je IMU und Achse (|a| ≥ 0,98 · FSR) für die Entscheidung
  über den KX134-Footprint.
- Sync: beim Start FIFO-Reset aller IMUs, dann TMST_STROBE je IMU und
  ADS131-Sample-Index festhalten → Phasenversatz pro IMU.
- Daten: RAM-Ring 128 Samples je IMU, Debug-Dump über UART/TCP. Noch nicht
  in .SST.
- Sleep: PWR_MGMT0 alle Sensoren aus in `on_sleep`, Re-Init in `on_waking`.

Verifikation: SPI-Analyzer: 4 CS-Zyklen pro 50 ms, Bursts ≈ 1000 B; Rate
= 1000/s ± 0,01 % je IMU über 10 min (nur noch Zähl-, keine Taktabweichung);
keine FIFO-Overflows; Poti-Sample-Count währenddessen weiterhin
`600000 ± 1`; DRDY-Jitter unverändert.

### M4 — entfällt (Buzzer vorhanden)

### M5 — Erweitertes Dateiformat

Header Version 4; IMU-Blöcke als eigener Stream in der Datei (nicht in
`struct record`, damit gosst/Dashboard für Version 3 unverändert bleiben):
pro IMU-Burst ein Block mit IMU-Index, ADC-Sample-Index des ersten Samples,
Anzahl, dann Hi-Res-Pakete. Core-1-Protokoll um `IMU_DUMP` erweitern.
SD-Last ≈ 84 kB/s. gosst: Reader für Version 4, Phasenversatz aus Header
anwenden, IMU-Daten als Zeitreihen auf dem 1-kHz-Raster der Potis.

## 4. Stückliste Frontend (neu gegenüber Rev. 2)

| Bauteil | Zweck |
|---|---|
| ADS131M04 PW (TSSOP-20) | ADC, 3 Kanäle genutzt |
| XO 8,192 MHz, CMOS 3,3 V (z. B. SiT2024, ECS-2520MV) | Master-Takt |
| 74HC4040 | ÷256 → 32 kHz |
| 74LVC125 | 4× CLKIN-Puffer für die Kabel |
| OPA2333 ×2 oder OPA4333 (alternativ MCP6004) | Speisung + 2 Schleifer-Puffer |
| 4× ICM-42686-P auf Sensor-PCB | IMU, Footprint KX134-1211 vorsehen |
| Hirose HR30, 6-polig, Einbaubuchse + Kabelstecker + Kappe | Poti-Stecker Fork/Shock, IP67, 1000 Zyklen (2.6) |
| Hirose HR30, 12-polig, Einbaubuchse + Kabelstecker + Kappe, 2× | Je ein IMU-Paar, IP67, 1000 Zyklen (2.6) |
| Kabel Poti: 3 Paare geschirmt, AWG 26, Mantel ø 4,2–5,0 mm | Fenster der HR30-Kabelklemme |
| Kabel IMU: 6 Paare geschirmt, AWG 28, Mantel ø 6,2–7,0 mm | Lötkelch ø 0,6 mm |
| Klemmzangen HR30-6P-T02 und HR30-8P-T02 | Einmalkosten, nötig für die Dichtigkeit |

## 5. Risiken und offene Punkte

1. **CLKIN-Spezifikation des ICM-42686-P trägt Note 1** („expected results
   based on design, not guaranteed in production"). 32,000 kHz liegt mittig
   im Bereich 31–50 kHz; beim M3-Bringup ODR-Lock am Analyzer nachweisen.
2. **SPI über 1 m Kabel bei 2 MHz.** Am Aufbau mit Analyzer prüfen; Fallback
   1 MHz. Datenrate reicht dann noch (64 % Auslastung mit Hi-Res).
3. **Opamp-Ausgang nahe 0 V.** Bei Pot am unteren Anschlag muss der Puffer
   unter 1 mV kommen; mit µA-Last erfüllt, im M2-Bringup messen.
4. **`multicore_fifo_push_blocking` im ISR** (unverändert aus Rev. 2): 2 s
   Reserve bei 2048er-Puffer, mit IMU-Blöcken (M5) neu bewerten.
5. **Clipping > 32 g.** Poti-Ableitung zeigte bis 80 g, vermutlich
   rauschbedingt überschätzt. Clip-Zähler aus M3 entscheidet über KX134.
6. **CALIBRATION-Migration** erzwingt einmalige Neukalibrierung auf allen
   Boards, auch ADS1115. In Release-Notes aufnehmen.
7. **Panelstaerke der HR30-Einbaubuchsen: 0,7 bis 3,0 mm.** Das legt die
   Gehaeusewand an den drei Bohrungen fest bzw. erzwingt eine Ansenkung.
   Muss ins Gehaeusedesign, bevor bestellt wird. Alle uebrigen
   Steckverbinderwerte sind gegen `firmware/docs/HR30_Catalog_en_HR30_CAT.pdf`
   verifiziert (2.6).
8. **DMA-Budget**: 4 eigene Kanäle + SD + cyw43; `dma_claim_unused_channel(true)`
   macht Engpass beim Boot sichtbar.

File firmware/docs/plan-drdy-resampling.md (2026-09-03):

# Plan: DRDY-Zeitstempel + Resampling auf Quarzraster (860 Hz bleibt)

> **AP0 Test 2 bestanden am 2026-08-13.** Gemessen mit `drdy_probe` am Gerät:
> `F=8324 S=8677 | PW 8/8 us | T 1201/1152 us | XCHK OK`.
> DRDY pulst auf beiden Kanälen, 8 µs breit, **aktiv low**. GPIO-IRQ und
> PWM-Flankenzählung am selben Pin stören sich nicht (`XCHK OK`).
>
> | | Fork | Shock |
> |---|---|---|
> | ADC-Rate | **832,4 SPS** | **868,1 SPS** |
> | ADC-Periode | **1201 µs** | **1152 µs** |
> | Intervall-Gate (0,8 × T) | **961 µs** | **922 µs** |
>
> Der Shock-ADC läuft **schneller** als der Poll-Takt vor AP5 (860,585 Hz). Er verwirft
> heute ~7,4 Wandlungen pro Sekunde, statt zu duplizieren. Der Fork dupliziert
> ~28/s. Die Zahlen ersetzen alle Schätzwerte weiter unten.

*Stand 2026-08-13: Raster auf exakt 860,000 Hz festgelegt. AP6, AP7 und AP7b
entfallen dadurch; `sample_rate = 860` beschreibt die Zeitachse exakt.*

*Stand 2026-08-14: AP8 abgeschlossen -- Punkte 1-5 und 7 bestanden, Punkt 6
statisch verifiziert (Bridge prueft nur das Magic). Offen bleiben nur die
opportunistische Rausch-Wiederholung bei teilentladenem Akku (AP8.4, kein
Blocker) und die Nebenbefunde.*

*Stand 2026-08-13: AP0 bis AP3 auf Hardware verifiziert; 400-kHz-Empfehlung aus
AP1 verworfen, Bus bleibt bei 1 MHz; Jitter gemessen statt angenommen.*

*Historischer Stand 2026-08-13: Code-Referenzen gegen den damaligen Plan geprüft
([protokoll-hw-verifikation-drdy.md](protokoll-hw-verifikation-drdy.md), Abschnitt 4):
gosst-`CurrentProcessingVersion` ist inzwischen 9 (Bump → 10), Sufni.Bridge ist 30
(Bump → 31). Zeilennummern in AP3/AP7/AP7b nach dem Dead-Band-Umbau (gosst) und
dem Bridge-Refactoring neu erhoben. Hardware-Annahmen unverändert bestätigt.*

*Stand 2026-07-28: Aufnahmelänge ≤ ~10 min bestätigt → uint32-Wrap entschärft
(AP3, AP8, Risiken). AP7 um das Sufni.Bridge-Paket erweitert — die Bridge darf
mitgeändert werden, bleibt aber aus anderem Grund beim additiven Feld.*
*Stand 2026-07-27: Review eingearbeitet — t_0-Vorzeichen korrigiert (AP5),
Mixed-Preset-Abstraktion (AP5), Ring 16 statt 8, Glitch-Gate pro Kanal.*

## Ziel

Die ADC-Uhr wird beobachtet statt angenommen. ADS1115 läuft weiter frei in
`MODE_CONTINUOUS` / `RATE_860_SPS`; jede Wandlung bekommt beim DRDY-Impuls einen
Quarz-Zeitstempel. Ausgabe auf exaktem 860-Hz-Raster, Catmull-Rom-interpoliert.

**Erreicht:** keine Duplikate, ehrliche Zeitachse, Fork/Shock-Skew höchstens 37 µs
und vor allem konstant statt mit 28,2 Hz wandernd (heute ±1,2 ms),
konstantes Sample-Alter (~3,6 ms, s. AP5), Ausfälle werden gezählt statt verschluckt.

**Nicht erreicht (bewusst):** effektive Bandbreite bleibt ~416 Hz (setzt der ADC),
und vor dem ADC sitzt weiterhin kein Antialiasing-Filter. Beides bleibt offen.

## Ausgangslage

| | Wert |
|---|---|
| Poll-Takt vor AP5 | 860,585 Hz (`-1000000/860` = 1162 µs, Integer-Division) |
| Raster ab AP5 | exakt 860,000 Hz (Restakkumulator 1162/1163 µs) |
| Header deklariert | 860 Hz |
| Wandlung Fork real | 832,4 SPS (gemessen AP0) |
| Wandlung Shock real | 868,1 SPS (gemessen AP0) |
| Schwebung Fork | 28,2 Hz → 28 Duplikate/s |
| Schwebung Shock | 7,4 Hz → 7,4 verworfene Wandlungen/s |
| Geschwindigkeitsfehler in gosst | ~3,4 % |
| Fork/Shock-Zeitversatz | wandert um bis zu ±1,2 ms mit der Schwebung |
| Reale Aufnahmelänge | Größenordnung Minuten, max ~10 min |

## Arbeitspakete

Firmware-Kette AP0→AP5 ist seriell. AP6, AP7 und AP7b entfallen mit dem exakten
860-Hz-Raster; danach folgt direkt AP8.

---

### AP0 — Vorabverifikation am Baustein

**Vor jeder Firmware-Arbeit.** Modul ist ein AZ-Delivery ADS1115
(„16BIT I2C ADC+PGA", blaues CJMCU-Layout).

**Am Foto bereits geklärt:**

- **ALRT ist auf den Header geführt** — Pinreihe von rechts:
  `VDD, GND, SCL, SDA, ADDR, ALRT, A0, A1, A2, A3`. Kein Antasten am Chip nötig.
- 4× „103" (10 kΩ) bestückt. Kanonische Belegung dieses Boards: SDA-Pull-up,
  SCL-Pull-up, ALERT-Pull-up, ADDR-Pull-down. Der ADDR-Pull-down passt zu
  `i2c_addr = 0x48` in `linear_ads1115.c:36` → stützt die Zuordnung.
- Der Pull-up-Wert ist für ALRT unkritisch: getriggert wird auf die **fallende**
  Kante, die treibt der Open-Drain-Ausgang hart. Nur die RC-langsame Freigabeflanke
  hängt am Widerstand, und die zählt nicht.

**Gemessen:**

1. ~~ALRT gegen VDD~~ → **10 kΩ, Pull-up bestückt ✓**. Belegt damit auch die
   Zuordnung der vier „103": SDA-PU, SCL-PU, ALRT-PU, ADDR-PD. Kein Nachlöten.
3. ~~Modulposition~~ → **beide Module sitzen im DAQ-Gehäuse ✓**. I²C und ALRT sind
   kurz und board-to-board, nur das analoge Sensorsignal geht durchs Kabel.
   Buskapazität ~30 pF.

**Erledigt:**

2. ~~Der Showstopper-Test.~~ → **bestanden ✓**: 8324 Counts Fork, 8677 Counts Shock, DRDY-Puls auf beiden Kanälen 8 µs breit und aktiv low, Kreuzcheck PWM- gegen ISR-Zähler ohne Differenz (`XCHK OK`).

   Die gemessene **kanalindividuelle** ADC-Rate liefert das Intervall-Gate in AP3:
   961 µs für Fork, 922 µs für Shock.

**Abbruchkriterium:** keine Pulse → Plan hinfällig, zurück auf Variante B
(Single-Shot-Retrigger, ~780 Hz).

*Umgebungsabhängig — läuft am Gerät, nicht delegierbar.*

---

### AP1 — Hardware

**DRDY:**

- ALRT Fork → **GP21**, ALRT Shock → **GP27**
- Pull-ups sind auf dem Modul bestückt (AP0), nichts nachzurüsten
- `firmware/src/fw/hardware_config.h`: `FORK_PIN_DRDY` / `SHOCK_PIN_DRDY` neben die
  bestehenden `*_PIN_SDA/SCL`-Blöcke
- **DRDY-Drähte im Gehäuse von der SD-Verdrahtung (GP16–19, 6,75 MHz) wegführen** —
  billigste Maßnahme gegen die Einkopplung aus AP3

**Warum genau diese Pins.** Die RP2040-PWM-Slices können Flanken in Hardware zählen
(`PWM_DIV_B_FALLING`) — aber nur auf dem **B-Kanal**, also nur auf **ungeraden**
GPIOs, und beide müssen auf **verschiedenen Slices** liegen. GP21 = Slice 2B,
GP27 = Slice 5B. Kein Konflikt mit der Buzzer-PWM (GP22 = Slice 3).

Das ist die Voraussetzung für AP0 Test 2 ohne Oszilloskop und liefert darüber hinaus
im finalen Build einen kostenlosen Gegencheck zu `drdy_count` aus dem ISR: divergieren
Hardware-Zähler und ISR-Zähler, verliert die ISR Kanten.

(GP26 wäre Slice 5 **Kanal A** — kann nicht zählen und läge auf demselben Slice wie
GP27. Vorbehalt zu GP21: in einem SDIO-Build wäre das D2; der aktive Preset ist
SPI-MicroSD, also frei. Alternative GP13 = Slice 6B, kollidiert dafür mit dem
SPI-Display-Build.)

Freie GPIOs im aktiven Preset `spi_card-i2c_disp-linear_fork-linear_shock`:
6, 7, 10–13, 20, 21, 26–28. Belegt: 2–5, 8, 9, 14–19, 22, 23–25, 29.

**I²C-Pull-ups — Nebenbefund aus AP0, unabhängig von DRDY:**

`linear_ads1115.c:94` fährt den Bus mit 1 MHz (Fast-mode Plus, t_r max 120 ns). Die
Modul-Pull-ups sind 10 kΩ, parallel zum Pico-internen ~56 kΩ also ~8,5 kΩ:

Module sitzen im Gehäuse (AP0 Test 3), Buskapazität ~30 pF. Pull-ups sind
10 kΩ (Modul) ∥ ~56 kΩ (Pico intern) = 8,5 kΩ:

| Rp | 30 pF | 50 pF | 1 MHz (120 ns) | 400 kHz (300 ns) |
|---|---|---|---|---|
| 8,5 kΩ (Bestand) | 216 ns | 360 ns | ✗ | grenzwertig |
| **+ 2,2 kΩ parallel → 1,8 kΩ** | 46 ns | 76 ns | ✓ | ✓ |

Die 2,2-kΩ-Widerstände sind eingelötet. Parallel zu den 10 kΩ der Module ergeben
sie gemessene 1,8 kΩ je Leitung. Damit liegt die Anstiegszeit bei 1 MHz innerhalb
der Fast-mode-Plus-Spec.

→ **2,2 kΩ von SDA und SCL nach 3V3, je Bus, auf der Pico-Seite, sind eingelötet.**
Nichts wurde ausgelötet. Senkstrom 1,8 mA, klar innerhalb der 3 mA des ADS1115.

→ **Der Plan empfahl hier 400 kHz. Die Messung in AP3 widerlegt das.** Der Bus
bleibt bei 1 MHz. 400 kHz verlängert den Read und damit die ISR-Kollision. Die
maximale Zeitstempelabweichung steigt von 37 µs auf 81 µs. Der Anteil über 35 µs
steigt von 0,19 % auf 7,7 %. Mit 1,8-kΩ-Pull-ups bleiben `i2c_err_count` und
`glitch_count` bei 1 MHz null.

Die Pico-internen Pull-ups sind in `linear_ads1115.c:101`–`102` per `gpio_disable_pulls` abgeschaltet.

Aufwand: 2 Drähte, 4 bedrahtete Widerstände.

**Erledigt:** DRDY-Leitungen und 2,2-kΩ-Pull-ups sind eingebaut. Effektiver
Pull-up-Widerstand: gemessene 1,8 kΩ je Leitung. Der Bus bleibt bei 1 MHz.

---

### AP2 — ADS1115-Treiber: DRDY scharfschalten, Read verschlanken

Datei: `firmware/src/sensor/linear_ads1115.c`

- In `linear_sensor_ads1115_init` nach `ads1115_write_config`:
  - `Hi_thresh = 0x8000` (Pointer 0x03), `Lo_thresh = 0x0000` (Pointer 0x02)
  - `COMP_QUE` von `QUE_DISABLE` (0b11, Lib-Default) auf `QUE_1` (0b00)
  - `COMP_POL` low, nicht latchend — beides Default, nur nicht überschreiben
- `pico-ads1115` kann weder Thresholds noch Comparator (Setter sind in
  `include/ads1115.h:112` auskommentiert) → zwei kleine Helper analog
  `ads1115_read_adc_debug`, das Config-Wort direkt maskieren
- **Pointer-Write eliminieren:** `ads1115_read_adc_debug` schreibt den Pointer bei
  jedem Read neu. Der Pointer bleibt aber auf 0x00 stehen, wenn ihn niemand ändert
  → einmalig in `init` setzen, danach reiner 2-Byte-Read. Spart 20 µs pro ISR.
  Invariante dokumentieren: kein anderer Pfad darf den Pointer bewegen —
  `check_availability` (1-Byte-Read ohne Pointer-Write, `linear_ads1115.c:119`)
  und `calibrate_expanded` (läuft vor RECORD) sind sicher.

---

### AP3 — Ringpuffer + Zeitstempel-ISR

Neue Datei: `firmware/src/sensor/drdy_ring.c` / `.h`

```c
struct sample { uint32_t t_us; uint16_t v; };
```
Ring pro Kanal, **16 Einträge** (128 B/Kanal), Power-of-two-Maske, Single-Producer
(ISR) / Single-Consumer (Timer-CB), `head` volatile. 8 würden rechnerisch reichen
(9,6 ms Fenster gegen ~6 ms Bedarf inkl. Konsument-Verspätung), 16 kosten 64 B mehr
und nehmen das Thema komplett vom Tisch.

**Zeitarithmetik (Wrap-Regel, gilt für AP3–AP5).** `timerawl` wrappt nach 71,6 min
— und zwar ab **Boot**, nicht ab Aufnahmestart, der Wrap kann also durchaus in eine
Aufnahme fallen. Entschärft ist er trotzdem: reale Aufnahmen sind Minuten lang
(max ~10 min = 6·10⁸ µs), verglichen werden ohnehin nur Zeitpunkte innerhalb des
Rings (~ms). Jede auftretende Differenz liegt damit um Größenordnungen unter
2³¹ µs (35,8 min) → **modulare uint32-Arithmetik ist hier per Konstruktion exakt**,
kein Sonderfall, kein Langzeittest nötig.

Kostet eine Klammer, also mitnehmen: Vergleiche ausschließlich über
`(int32_t)(a - b)`; `t_k` wird in AP5 mit 1162/1163-µs-Schritten und bewusst als
wrappende uint32-Rechnung fortgeschrieben.
**Nirgends `absolute_time_t` oder 64-bit-Zeit einmischen** — genau das (und nacktes
`a < b`) wäre der einzige Weg, den Wrap doch noch sichtbar zu machen.

ISR-Reihenfolge ist die tragende Annahme des ganzen Entwurfs:

```c
uint32_t t = timer_hw->timerawl;   // ZUERST — nur das ist zeitkritisch
uint16_t v = i2c_read_2bytes();    // ~30 µs, darf spät sein
ring[head & MASK] = (struct sample){t, v};
__dmb();
head++;
```

Der Read darf verzögert werden, weil das Conversion-Register den Wert bis zur
nächsten fertigen Wandlung hält → ~1,2 ms Budget für 30 µs Arbeit.

Zähler: `drdy_count`, `late_count` (neuer DRDY bevor der vorige Read fertig war),
`i2c_err_count`, `glitch_count` (s.u.).

**Intervall-Gate gegen Störeinkopplung.** Der ALERT-Pull-up ist 10 kΩ (AP0), die
Leitung also hochimpedant. Eine eingekoppelte falsche fallende Kante erzeugt ein
Phantom-Sample, das eine echte Stützstelle *verdrängt* und die Interpolation
verfälscht.

Der einzige relevante Störer ist **SD-SPI** (6,75 MHz, GP16–19): burstartig 8 KB alle
~2,4 s, also garantiert gleichzeitig mit DRDY-Kanten. WLAN ist während RECORD zwar
bestromt, aber nicht assoziiert und im Power-Save (`main.c:823`, `main.c:608`) — kein
RF. Die Buzzer-PWM stoppt nach dem Starton (`buzzer.c:54`), GP22 liegt statisch.
Beide vernachlässigbar.

Abwehr: DRDY verwerfen, wenn er weniger als 0,8× der in AP0 gemessenen ADC-Periode
**des jeweiligen Kanals** nach dem vorherigen kommt: Fork 832,4 SPS, Periode
1201 µs, Gate 961 µs; Shock 868,1 SPS, Periode 1152 µs, Gate 922 µs. Eine globale
Schwelle wäre für den schnelleren Kanal zu locker. Ein kürzeres Intervall ist
physikalisch unmöglich. Ein Vergleich, `glitch_count` hoch, fertig. Kein
Software-Entprellen, das würde den Zeitstempel verschmieren. Die
Schmitt-Trigger-Eingänge des RP2040 sind ohnehin aktiv.

Der Zähler ist primär **Diagnose**: bleibt `glitch_count` über eine lange Aufnahme
auf 0, ist die Verdrahtung sauber. Die billigste Maßnahme ist ohnehin Layout, nicht
Software — siehe AP1.

**IRQ-Registrierung:** `pushbutton.c:59` belegt via
`gpio_set_irq_enabled_with_callback` den *einen globalen* GPIO-Callback.
→ `gpio_add_raw_irq_handler_with_order_priority` für die beiden DRDY-Pins, hält
`pushbutton.c` unangetastet.

**Beide ISRs auf Core0.** Core1 macht blockierende SD-Writes, die die 1,2-ms-Grenze
reißen können.

> **AP3 auf Hardware verifiziert am 2026-08-13.** `drdy_count` traf exakt die
> AP0-Erwartung: 8324 Fork und 8677 Shock in 10 s. `late_count`, `i2c_err_count`
> und `glitch_count` blieben in allen Läufen null. Ein Ringdump zeigte echte
> Wandlungswerte und bestätigte damit die Pointer-Invariante.
>
> | Größe | 400 kHz | 1 MHz |
> |---|---:|---:|
> | max. Abweichung | 81 µs | 37 µs |
> | Anteil Samples > 5 µs daneben | 10,6 % | 5,3 % |
> | Anteil Samples > 35 µs daneben | 7,7 % | 0,19 % |
> | Anteil Samples > 75 µs daneben | 0,41 % | 0 |
> | `i2c_err_count` / `glitch_count` / `late_count` | 0 | 0 |
>
> Beide blockierenden DRDY-ISRs laufen auf Core0. Kollidieren zwei DRDY-Impulse,
> wartet der zweite Read auf den ersten. 1 MHz verkürzt dieses Warten. Kontrollen
> mit jeweils nur einem aktiven Kanal ergaben 9 µs und 1 µs maximale Abweichung.
> Sie bestätigen die Kollision als alleinige Ursache. Der Restjitter von 37 µs
> ist inhärent und wird in AP4 als Stützstellenabstand-Ungleichheit sichtbar.

---

### AP4 — Catmull-Rom-Resampler

Gleiche Datei. `resample(channel, t_k) → uint16`

- Intervall `[t_i, t_{i+1}] ∋ t_k` im Ring suchen (Vergleiche wrap-sicher, s. AP3);
  CR braucht zusätzlich `i-1` und `i+2` → 4 Stützstellen, Auswerte-Latenz
  3 ADC-Perioden des langsameren Kanals = 3 × 1201 µs = 3603 µs ≈ 3,6 ms
  (Offset aus AP5)
- `u = (t_k − t_i) / (t_{i+1} − t_i)` in Q16
- `v = ½·( 2P₁ + (−P₀+P₂)u + (2P₀−5P₁+4P₂−P₃)u² + (−P₀+3P₁−3P₂+P₃)u³ )`
- int32/int64-Arithmetik, kein Float nötig (RP2040 hat keine FPU).
  ~20 Ops pro Kanal pro Tick → 34 k Ops/s von 125 MHz, nicht messbar
- Gemessener Jitter höchstens 37 µs gegen 1152 µs Intervall, also 3,2 %; 95 % der
  Intervalle liegen innerhalb 5 µs. Das echte `u` enthält den Jitter bereits;
  ignoriert wird nur die Ungleichheit der Abstände zwischen vier Stützstellen.

**Randfälle:**

| Fall | Verhalten |
|---|---|
| < 4 Stützstellen im Ring | letzten Wert halten, Zähler hoch |
| `t_k` vor dem Ring | sollte nach korrektem `t_0` nicht vorkommen, Zähler hoch |
| `t_k` hinter dem Ring (ADC steht) | letzten Wert halten, Zähler hoch |
| Loch im Ring (Glitch-Gate / I²C-Fehler) | Intervall wird ~2 Perioden breit, uniform-CR verzerrt lokal — hinnehmen, `glitch_count`/`i2c_err_count` zeigen es; bei erwartetem 0 kein Thema |
| Kanal nicht verfügbar | `0xFFFF` wie heute |

**Wichtig:** Baseline-Subtraktion und Clamp auf 0 stehen heute in
`linear_sensor_ads1115_measure` (`linear_ads1115.c:162`). Beides muss **nach** der
Interpolation laufen — clampt man die Stützstellen, verzerrt man die Kurve.
Im Ring stehen Rohwerte.

> **AP4 auf dem Host geprüft am 2026-08-13.** Die Datei `drdy_ring.c` wurde mit
> Pico-SDK-Stubs auf dem Rechner übersetzt und gegen eine Float-Referenz geprüft.
>
> Die Q16-Festkommarechnung liefert bei u=0 exakt P1 und bei u=1 exakt P2. Eine
> Gerade als Stützstellenfolge wird exakt reproduziert. Eine Konstante bleibt exakt
> konstant.
>
> Der Host-Test maß nur den über alle `u` gemittelten Versatz. Das war der Fehler.
> Entscheidend ist die Abhängigkeit von `u`: Der abschneidende Versatz läuft von 0
> bei u=0 auf -0,88 LSB bei u=0,9 und springt bei u=1 zurück auf 0. `u` durchläuft
> diesen Bereich mit der Schwebungsfrequenz. Der Versatz wird damit zu einem
> Sägezahn von 0,9 LSB, im Ruhesignal von rund 1 LSB.
>
> Eine Aufnahme mit der abschneidenden Variante zeigte die Linie im Signal mit
> +18,4 dB (Fork, 27,32 Hz) und +16,6 dB (Shock, 7,97 Hz). Die alte Firmware hatte
> im Signal keine solche Linie. Die Simulation der ganzen Kette reproduziert den
> Befund und sagt für die gerundete Variante den Rauschboden voraus. Deshalb wird
> gerundet. Der `u`-abhängige Versatz sinkt auf praktisch null, die maximale
> Abweichung von der Float-Referenz von 2,00 auf 0,97 LSB.
>
> Bei Extremstützstellen mit einem Wechsel zwischen -32768 und 32767 läuft das
> Ergebnis auf -40960 bis 40958. Catmull-Rom überschwingt an Stufen um bis zu
> 25 Prozent. Der Clamp auf den int16-Bereich ist damit notwendig, nicht
> vorsorglich.
>
> Bei 16 Ringeinträgen sind die Intervalle 1 bis 13 nutzbar. Das sind 13 Intervalle
> oder rund 15,6 ms Vorgeschichte. Der Auswerte-Offset von 3,6 ms aus AP5 liegt
> komfortabel darin.
>
> `t_k` vor dem Fenster, `t_k` hinter dem Fenster und weniger als vier Stützstellen
> lösen jeweils den richtigen Zähler aus und halten den letzten Wert. Ein
> uint32-Überlauf der Zeitstempel mitten im Ring ändert nichts am Ergebnis. Die
> Wrap-Regel aus AP3 trägt.
>
> Das Torn-Prädikat wurde einzeln gegen zwölf Fälle geprüft. Dabei überholt die ISR
> den Consumer während des Kopierens. Die Fälle enthalten einen Überlauf von
> `head` selbst. Das Prädikat trifft in allen Fällen zu. Im Einzelthread lässt sich
> der Fall nicht fahren. Deshalb erfolgte die getrennte Prüfung.
>
> Ein Loch im Ring verzerrt lokal, stürzt aber nicht ab. Das ist so vorgesehen.
>
> Das Testprogramm liegt außerhalb des Repos. Es gibt im Firmware-Teil noch keine
> Testinfrastruktur.

---

### AP5 — Grid-Timer und Startsequenz

Datei: `firmware/src/fw/main.c`

- **Mixed-Presets:** `data_acquisition_cb` (`main.c:157`) ist preset-übergreifend —
  `linear_fork-as5600_shock` und `as5600_fork-linear_shock` existieren in
  `CMakePresets.json`. Deshalb kein `resample()`-Call und kein `#ifdef` direkt im
  Callback, sondern optionale Ops in `sensor.h`: `sample_at`, `ready` und `stop`.
  Statische Inline-Helfer verwenden bei `NULL` weiterhin `measure()`, `true` bzw.
  keine Aktion. So bleiben AS5600 und EvoMini unangetastet. ADS1115 implementiert
  Ring-Resampling + Baseline/Clamp (Reihenfolge aus AP4), Ring-Füllstand und
  IRQ-Abschaltung.
- Das Raster läuft **exakt mit 860,000 Hz**. Weil
  `1000000 = 860 · 1162 + 680`, ist jeder Schritt zunächst 1162 µs lang; ein
  Restakkumulator addiert 680 und macht den Schritt bei Überlauf über 860 zu
  1163 µs. Das Muster wiederholt sich nach 43 Ticks über exakt 50000 µs und
  sammelt unabhängig von der Aufnahmedauer keinen Fehler an. `t_k` bleibt eine
  wrappende uint32-Rechnung gemäß AP3.
- Ein selbst neu gestellter Alarm ersetzt den Wiederhol-Timer. Der Callback gibt
  den nächsten Schritt **negativ** zurück. Damit plant das SDK relativ zum
  vorgesehenen Auslösezeitpunkt; ein positiver Wert wäre relativ zur Jetztzeit
  und würde Verspätung und Interrupt-Jitter in der Zeitachse aufsummieren.
  `get_absolute_time()` kommt im Callback nicht vor.
- `on_rec_start` (`main.c:407`): DRDY-IRQs aktivieren → warten, bis alle
  **verfügbaren** Kanäle ≥ 4 Samples im Ring haben (Timeout ~100 ms; „beide" wäre
  bei nur einem bestückten Sensor ein Dauer-Timeout — `start_sensors` lässt einen
  genügen, `main.c:201`) → **`t_0` = jetzt **−** 3 ADC-Perioden des langsameren
  Kanals = jetzt − 3 × 1201 µs = jetzt − 3603 µs** → Timer starten.

  **Das Vorzeichen ist tragend.** Auswertung von `t_k` setzt voraus, dass `i+2`
  schon gewandelt ist: `t_k ≤ W − 2·T_adc` (W = Wanduhrzeit im Callback). Läge
  `t_0` in der Zukunft (+2), stünde jedes `t_k` dauerhaft ~1,2 ms vor dem neuesten
  Sample — jeder Tick fiele still in den Hold-Fallback, sähe aus wie heute (inkl.
  Duplikaten), nur mit explodierendem Zähler. −3 statt −2: eine Periode
  Jitter-Reserve. Sample-Alter damit konstant ~3,6 ms, abgeleitet aus der
  Fork-Periode als langsamerem Kanal.
- `absolute_time_t` wird beim Start nur verwendet, um den ersten Alarm zu
  terminieren. Direkt daneben wird `grid_t_k_us = timerawl - 3603` gelesen; die
  Rasterrechnung selbst mischt keine 64-bit-Zeit ein.
- `on_rec_stop` (`main.c:441`): Alarm abbrechen, DRDY-IRQs ausschalten und alle
  Ringzähler beider ADS1115-Kanäle debug-ausgeben. Nichtnull-Fehlerzähler werden
  mit Kanal, Kürzel und Wert kurz auf dem Display sichtbar gemacht.
- Der Dateiversionswert steigt von 3 auf 4. Headerformat und -größe bleiben
  unverändert; der Bump kennzeichnet lediglich Dateien aus dem DRDY-Verfahren.

---

### AP6 — Entfallen (ehemals Dateiformat v4)

**Entfallen.** Dieses Arbeitspaket existierte nur, um die 0,585-Hz-Abweichung des
1162-µs-Takts nach unten durchzureichen. Das exakte Raster stimmt mit
`sample_rate = 860` überein; gosst, Bridge und Dashboard brauchen kein neues
Periodenfeld. Der Versionsbump 3 → 4 bleibt als Kennzeichen ohne Formatänderung.

Der folgende Text dokumentiert den früheren, nicht mehr umzusetzenden Ansatz.

Die Rasterperiode 1162 µs = 860,585 Hz ist kein ganzzahliges Hz. Der Header hat aber
2 Byte implizites Padding (Alignment vor `time_t`) — sichtbar in
`gosst/formats/sst/sst.go:14`. Da rein die Periode.

**Firmware** `src/fw/sst.h`:
```c
struct header {
    char     magic[3];
    uint8_t  version;          // 3 -> 4
    uint16_t sample_rate;      // bleibt 860, für alte Leser
    uint16_t sample_period_us; // NEU, war Padding: 1162
    time_t   timestamp;
};
```
Plus Initialisierung in `main.c:267`. Keine Größenänderung, voll rückwärtskompatibel.

**gosst** `formats/sst/sst.go`: `Padding` → `SamplePeriodUs`; bei `Version >= 4`
Rate = `1e6 / SamplePeriodUs`, sonst wie bisher aus `SampleRate`.

Nebeneffekt: der Integer-Divisions-Fehler ist damit strukturell unmöglich.

**Zweiter Konsument des Headers: Sufni.Bridge.** Die Bridge parst die rohe .SST-Datei
selbst, nicht nur den Blob — `Sufni.Bridge/Models/Telemetry/RawTelemetryData.cs:27`.
Im Code geprüft, AP6 ist für sie unkritisch:

- **Kein Version-Gate** — validiert wird nur das Magic (Zeile 40), `Version` wird bloß
  durchgereicht. Der Bump 3→4 bricht nichts.
- Bytes 6–8 werden explizit als Padding übersprungen (Zeile 37), `HeaderSize = 16`
  (Zeile 22) bleibt. Das neue Feld ist für die Bridge unsichtbar.

Ohne Bridge-Anpassung liest sie weiter `sample_rate` = 860 statt der 1162 µs, bleibt
also bei **0,068 %** Fehler (heute 3,4 %) — tolerierbar. Da die Bridge geändert werden
darf, ist das Feld dort trotzdem vorgesehen: → **AP7b**.

---

### AP7 — Entfallen (ehemals gosst auf Fließkomma-Rate)

**Entfallen.** Die Fließkomma-Rate war nur wegen der 0,585-Hz-Abweichung des
früheren 1162-µs-Rasters nötig. Mit exakt 860,000 Hz ist `sample_rate = 860`
bereits vollständig; gosst und Dashboard bleiben unverändert.

Der folgende Text dokumentiert den früheren, nicht mehr umzusetzenden Ansatz.

**Empfohlener Weg bleibt additiv statt Typwechsel.** `Meta.SampleRate uint16` im Blob
**stehen lassen** und ein neues Feld `SampleRateHz float64` danebenlegen. Alte Blobs
dekodieren, das neue Feld ist bei ihnen 0 → Fallback auf `float64(SampleRate)`.

**Die Begründung hat sich verschoben, das Ergebnis nicht.** Sufni.Bridge darf
mitgeändert werden, „fremder Consumer" zieht als Argument also nicht mehr. Der
eigentliche Grund ist ein anderer: die Bridge ist nicht nur Leser, sondern
**auch Produzent** des Blobs (`TelemetryData.cs:735` / `:833`
`MessagePackSerializer.Serialize(this)`) und hat eine **eigene** Pipeline mit
eigenem `CurrentProcessingVersion = 30` (`TelemetryData.cs:180`). Ein Typwechsel
`SampleRate` uint16→float64 im Blob erzwingt damit ein **Lockstep-Deploy** beider
Seiten: eine alte Bridge stolperte über einen Float unter dem Key `SampleRate`
(C#-Property ist `int`, `TelemetryData.cs:187`), eine neue gosst-Version über die
uint16-Blobs, die jede noch nicht aktualisierte Bridge weiter schreibt. Additiv
kennt dieses Problem nicht — beide Seiten dürfen unabhängig ausgerollt werden.

Kosten der Alternative, falls doch jemand „sauber" will: `int SampleRate` → `double`
schlägt auf ~110 Fundstellen in 26 Dateien der Bridge durch, u. a.
`ComputeVelocity(double[], int)` (`TelemetryData.cs:494`), `FilterStrokes`
(`Strokes.cs:241`), die Cache-Spalten `int? SampleRate` (`SessionCache.cs:288/307`)
sowie zwei heute ganzzahlige Divisionen (`SQLiteDatabaseService.cs:1097`,
`ImportSessionsViewModel.cs:340`). Nicht empfohlen.

Umzustellen in gosst (Signaturen `uint16` → `float64`):

| Funktion | Ort |
|---|---|
| `calculateDerivative` | `psst.go:226` |
| `forkVelocityZeroThreshold` | `psst.go:127` |
| `shockVelocityZeroThreshold` | `psst.go:131` |
| `rearWheelVelocityZeroThreshold` | `psst.go:135` |
| `rejectSingleSampleSpikes` | `psst.go:269` |
| `reprocessSuspension` | `psst.go:630` |
| `filterStrokes` (`rate`, nicht `sampleRate`) | `stroke.go:397` |
| `coveredByAirtime` | `airtimes.go:8` |

(Die Funktionen `rearWheelVelocityZeroThreshold` und
`rejectSingleSampleSpikes` kamen mit dem Dead-Band-Umbau dazu. Beide tragen
ebenfalls den Parameter `sampleRate uint16`.)

(Zeilen Stand 2026-08-13. Die Threshold-Funktionen tragen seit dem Dead-Band-Umbau
einen zusätzlichen Parameter `travelPerLsb float64`; die Umstellung betrifft
weiterhin nur `sampleRate uint16` → `float64`.)

~32 Fundstellen in 4 Dateien, durchweg Divisionen/Multiplikationen; die
`float64(...)`-Casts fallen weg.

Weiter:
- `gosst-http.go:40` `Session.SampleRate` → `float64`, JSON-Feld `sample_rate` bleibt
- `CurrentProcessingVersion` 9 → 10 (`psst.go:106`), damit alte Blobs neu gerechnet werden
- **Fallback ist dauerhaft, nicht übergangsweise:** solange die Bridge Blobs ohne
  `SampleRateHz` schreiben darf, muss gosst den 0-Fall auf ewig behandeln
- **Dashboard (optional, analog AP7b):** Die Blob-Dekodierung ist unkritisch.
  `_dfd` in `dashboard/app/telemetry/psst.py:142` setzt unbekannte Keys per
  `setattr`. Das neue Feld `SampleRateHz` landet sauber am Objekt. Nichts bricht.
  Das Dashboard liest aber weiter `t.SampleRate`. Das bleibt bei der additiven
  Lösung 860. Der Ratenfehler bleibt damit wie bei der Bridge ohne AP7b bei
  0,068 %. Der Fix ist klein: `SampleRateHz float` in die `Telemetry`-Dataclass
  (`dashboard/app/telemetry/psst.py:131`) aufnehmen, eine Property
  `rate = SampleRateHz or SampleRate` ergänzen und die Aufrufstellen umhängen:
  `dashboard/app/api/session/routes.py:99`, `:199` und `:416`,
  `dashboard/app/telemetry/balance_metrics.py:124`,
  `dashboard/app/telemetry/travel.py:498` und `:506`,
  `dashboard/app/telemetry/misc_plots.py:223` sowie
  `dashboard/app/telemetry/fft.py:67`.

---

### AP7b — Entfallen (ehemals Sufni.Bridge, symmetrisch additiv)

**Entfallen.** Wie AP6 und AP7 diente dieses Paket ausschließlich dazu, die
0,585-Hz-Abweichung weiterzureichen. Beim exakten 860-Hz-Raster benötigt die
Bridge weder ein Zusatzfeld noch einen Processing-Version-Bump.

Der folgende Text dokumentiert den früheren, nicht mehr umzusetzenden Ansatz.

Sufni.Bridge ist nicht Teil dieses Repositories. Dessen oberste Ebene enthält nur
`caddy`, `dashboard`, `firmware`, `gosst`, `pics` und `test_utils`. AP7b braucht ein
separates Checkout.

Zweck: die Bridge rechnet ihre eigene Verarbeitung ebenfalls mit der exakten Rate und
gibt sie in selbst geschriebenen Blobs weiter. Ohne AP7b bleibt sie funktionsfähig,
nur mit 0,068 % Ratenfehler und ohne `SampleRateHz` in ihren Blobs.

1. `Models/Telemetry/RawTelemetryData.cs`: Bytes 6–8 (heute Padding-Kommentar,
   Zeile 37) als `ushort SamplePeriodUs` lesen; `double SampleRateHz` =
   `Version >= 4 ? 1e6 / SamplePeriodUs : SampleRate`. Magic-Check und
   `HeaderSize = 16` bleiben unangetastet.
2. Durchreichen an den `TelemetryData`-Konstruktor in den drei Einlesepfaden:
   `MassStorageTelemetryFile.cs:53`, `NetworkTelemetryFile.cs:32`,
   `StorageProviderTelemetryFile.cs:67`.
3. `TelemetryData`: `double SampleRateHz` **neben** `int SampleRate` (Zeile 187)
   — Map-Mode (`keyAsPropertyName: true`, Zeile 173) heißt: alte Blobs liefern 0 →
   Fallback auf `SampleRate`, exakt die gosst-Semantik. In `ComputeVelocity`
   (`:494`), `FilterStrokes` (`Strokes.cs:241`) und den Plots die neue Property
   verwenden. `Parameters.WhLambdaForCutoff` nimmt bereits `double`
   (`Parameters.cs:267`) — dort nichts zu tun.
4. `CurrentProcessingVersion` 30 → 31 (`TelemetryData.cs:180`), sonst behalten
   gecachte Blobs ihre mit 860 gerechneten Geschwindigkeiten.

Die Whittaker-Referenzrate `WhReferenceSampleRate = 860.0` (`Parameters.cs:250`)
bleibt, wie sie ist: 860 → 860,585 verschöbe λ um 0,14 %, unterhalb jeder Relevanz.

---
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

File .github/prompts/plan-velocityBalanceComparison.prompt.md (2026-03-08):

## Plan: Add Velocity Balance Comparison to Comparison Tab

The "Travel hist. comp." tab currently shows a full-width travel histogram comparison (+ FFT below). We split it into a two-column 50/50 layout: left keeps the existing histogram+FFT, right adds a new combined velocity balance comparison diagram showing compression and rebound trendlines in a single chart. Compression trendlines sit above x-axis (positive velocity), rebound below (negative velocity), with a horizontal zero-line separating them. Lines only, no scatter dots.

---

### Phase 1: New Bokeh figure — `velocity_balance_comparison_figure()`

**File:** [dashboard/app/telemetry/balance.py](dashboard/app/telemetry/balance.py)
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

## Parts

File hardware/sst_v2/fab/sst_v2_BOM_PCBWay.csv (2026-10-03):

Item # | Designator | Qty | Manufacturer | Mfg Part # | Description / Value | Package/Footprint | Type
1 | BT1 | 1 | Keystone | 3001 | Battery holder CR1220, THT | BatteryHolder_Keystone_3001_1x12mm | THT
2 | BZ1 | 1 | TDK | PS1240P02BT | Piezo buzzer 12 mm, 5 mm pitch, THT | Buzzer_TDK_PS1240P02BT_D12.2mm_H6.5mm | THT
3 | C2,C23,C38 | 3 | any |  | Capacitor 1uF X7R 25V 0603 | 0603 | SMD
4 | C3 | 1 | any |  | Capacitor 220nF X7R 25V 0603 | 0603 | SMD
5 | C1,C4,C5,C19,C28,C30,C32,C34,C37,C39,C40,C42,C44,C_FG1,C_PWR1 | 15 | any |  | Capacitor 100nF X7R 50V 0603 | 0603 | SMD
6 | C6 | 1 | any |  | Capacitor 22uF X7R 10V 0805 (LDO output, >=10 uF effective at 3 V) | 0805 | SMD
7 | C22 | 1 | any |  | Capacitor 10uF X5R 10V 0603 (LDO input) | 0603 | SMD
8 | C27,C31,C33,C35,C41 | 5 | any |  | Capacitor 10uF X7R 16V 0805 | 0805 | SMD
9 | C9,C12,C20,C24,C25,C36 | 6 | any |  | Capacitor 10nF C0G 50V 0603 | 0603 | SMD
10 | C21 | 1 | any |  | Capacitor 4.7uF X7R 16V 0805 | 0805 | SMD
11 | C26 | 1 | KEMET | T520D107M010ATE040 | Polymer tantalum 100 uF 10 V, case D (7343-31) | CP_EIA-7343-31_Kemet-D | SMD
12 | C_CHG1,C_CHG2 | 2 | any |  | Capacitor 4.7uF X5R 16V 0805 (Lader VBUS/VBAT) | 0805 | SMD
13 | D1 | 1 | Littelfuse | SMAJ5.0CA | TVS 5 V bidirectional, SMA | D_SMA | SMD
14 | D2-D4 | 3 | Nexperia | PESD5V0S2BT,215 | ESD protection 5 V, bidirectional double, low leakage, SOT-23 (pin 1 = line, pin 3 = GND, pin 2 unused) | SOT-23 | SMD
15 | D_PWR1 | 1 | Nexperia | RB751S40,115 | Schottky 40 V 120 mA, low leakage, SOD-523 (BTN_L -> PWR_BTN) | D_SOD-523 | SMD
16 | D_VSYS1 | 1 | Nexperia | PMEG3020EH,115 | Schottky 30 V 2 A, SOD-123F (blocks USB VBUS backfeed into LiPo) | D_SOD-123F | SMD
17 | FB1,FB2 | 2 | Murata | BLM18PG471SN1D | Ferrite bead 470 R @100 MHz, 0603 | 0603 | SMD
18 | J_BAT1 | 1 | JST | B2B-PH-K-S(LF)(SN) | JST PH 2-pin vertical, THT | JST_PH_B2B-PH-K_1x02_P2.00mm_Vertical | THT
19 | J_DEBUG1 | 1 | generic | PinHeader 1x3 2.54 mm | Male pin header 1x3 (UART RX/TX/GND), 2.54 mm, vertical, THT | PinHeader_1x03_P2.54mm_Vertical | THT
20 | J_IMU_A1 | 1 | JST | BM12B-SRSS-TB(LF)(SN) | JST SH 12-pin vertical, SMD | JST_SH_BM12B-SRSS-TB_1x12-1MP_P1.00mm_Vertical | SMD
21 | J_IMU_B1 | 1 | JST | BM12B-SRSS-TB(LF)(SN) | JST SH 12-pin vertical, SMD | JST_SH_BM12B-SRSS-TB_1x12-1MP_P1.00mm_Vertical | SMD
22 | J_OLED1 | 1 | JST | BM04B-SRSS-TB(LF)(SN) | JST SH 4-pin vertical, SMD | JST_SH_BM04B-SRSS-TB_1x04-1MP_P1.00mm_Vertical | SMD
23 | J_POT1 | 1 | JST | BM06B-SRSS-TB(LF)(SN) | JST SH 6-pin vertical, SMD | JST_SH_BM06B-SRSS-TB_1x06-1MP_P1.00mm_Vertical | SMD
24 | J_SD1 | 1 | Hirose | DM3AT-SF-PEJM5 | microSD socket, push-push | microSD_HC_Hirose_DM3AT-SF-PEJM5 | SMD
25 | L_FORK_CMC1,L_SHOCK_CMC1 | 2 | Murata | DLW5BTM251SQ2L | Common-mode choke 250 R @100 MHz, 5 A | L_CommonModeChoke_Murata_DLW5BTMxxxSQ2x_5x5mm | SMD
26 | Q_PWR2,Q_PWR3 | 2 | Diodes Inc. | 2N7002-7-F | N-MOSFET 60 V, SOT-23 (Soft-Power Gate-Treiber / PWR_OFF) | SOT-23 | SMD
27 | Q_RP1,Q_PWR1 | 2 | Diodes Inc. | DMG2305UX-7 | P-MOSFET -20 V, SOT-23 (Q_RP1 LiPo-Verpolschutz, Q_PWR1 Soft-Power-Schalter) | SOT-23 | SMD
28 | R1-R3,R27,R28,R31,R47,R_STAT1 | 8 | any |  | Resistor 10k 1% 0603 | 0603 | SMD
29 | R8,R14,R35-R37 | 5 | any |  | Resistor 1k 1% 0603 | 0603 | SMD
30 | R9,R15 | 2 | any |  | Resistor 0R 1% 0603 | 0603 | SMD
31 | R25,R26 | 2 | any |  | Resistor 4.7k 1% 0603 | 0603 | SMD
32 | R29,R34 | 2 | any |  | Resistor 47R 1% 0603 | 0603 | SMD
33 | R32 | 1 | Susumu | RG1608P-203-B-T5 | Resistor 20k 0.1% thin film, 0603 | 0603 | SMD
34 | R33 | 1 | Susumu | RG1608P-103-B-T5 | Resistor 10k 0.1% thin film, 0603 | 0603 | SMD
35 | R38-R46 | 9 | any |  | Resistor 33R 1% 0603 | 0603 | SMD
36 | R48,R49 | 2 | any |  | Resistor 47k 1% 0603 (microSD DAT1/DAT2 pull-up) | 0603 | SMD
37 | R50 | 1 | any |  | Resistor 100R 1% 0603 (ADC_RST-Serienwiderstand) | 0603 | SMD
38 | R_PROG | 1 | any |  | Resistor 3.3k 1% 0603 (Ladestrom 300 mA) | 0603 | SMD
39 | R_PWR1-R_PWR4 | 4 | any |  | Resistor 100k 1% 0603 (Soft-Power: Gate-Pull-up, Pull-downs, CLR-Pull-up) | 0603 | SMD
40 | R_STAT2 | 1 | any |  | Resistor 10k 1% 0603 (CHG_STAT-Teiler) | 0603 | SMD
41 | SW_L1 | 1 | JST | BM02B-SRSS-TB(LF)(SN) | JST SH 2-pin vertical, SMD | JST_SH_BM02B-SRSS-TB_1x02-1MP_P1.00mm_Vertical | SMD
42 | SW_R1 | 1 | JST | BM02B-SRSS-TB(LF)(SN) | JST SH 2-pin vertical, SMD | JST_SH_BM02B-SRSS-TB_1x02-1MP_P1.00mm_Vertical | SMD
43 | U1 | 2 | Samtec (or equivalent) | SSW-120-01-T-S | Female socket header 1x20, 2.54 mm, 8.5 mm, THT - 2 pcs per board for Raspberry Pi Pico 2 W (Pico NOT supplied/assembled) | RaspberryPi_Pico_Common_THT | THT
44 | U2 | 1 | Texas Instruments | ADS131M04IPWR | ADC 24-bit 4-ch, TSSOP-20 | TSSOP-20_4.4x6.5mm_P0.65mm | SMD
45 | U3 | 1 | Analog Devices / Maxim | DS3231SN# | RTC, SOIC-16W | SOIC-16W_7.5x10.3mm_P1.27mm | SMD
46 | U_AAF1 | 1 | Texas Instruments | TLV4333IDR | Quad op-amp, SOIC-14 | SOIC-14_3.9x8.7mm_P1.27mm | SMD
47 | U_ANA_LDO1 | 1 | Texas Instruments | TPS7A4700RGWR | LDO, VQFN-20 (RGW) | Texas_RGW0020A_VQFN-20-1EP_5x5mm_P0.65mm_EP3.15x3.15mm | SMD
48 | U_CHG1 | 1 | Microchip | MCP73831T-2ACI/OT | Li-Po charger 4.20 V, SOT-23-5 | SOT-23-5 | SMD
49 | U_CLKBUF1 | 1 | Nexperia | 74LVC125APW,118 | Quad buffer, TSSOP-14 | TSSOP-14_4.4x5mm_P0.65mm | SMD
50 | U_DIV1 | 1 | Nexperia | 74HC4040PW,118 | 12-stage counter, TSSOP-16 | TSSOP-16_4.4x5mm_P0.65mm | SMD
51 | U_FG1 | 1 | Analog Devices / Maxim | MAX17048G+T10 | Fuel Gauge 1S Li+, I2C 0x36, TDFN-8 2x2 mm EP | TDFN-8-1EP_2x2mm_P0.5mm_EP0.8x1.2mm | SMD
52 | U_PWR1 | 1 | Analog Devices / Maxim | MAX16150AUT+T | Pushbutton On/Off Controller, 50 ms / 8 s, SOT-23-6 | SOT-23-6 | SMD
53 | Y1 | 1 | ECS | ECS-2520MVLC-081.92-BN-TR | Oscillator 8.192 MHz CMOS, 2.5x2.0 mm | Oscillator_SMD_ECS_2520MV-xxx-xx-4Pin_2.5x2.0mm | SMD

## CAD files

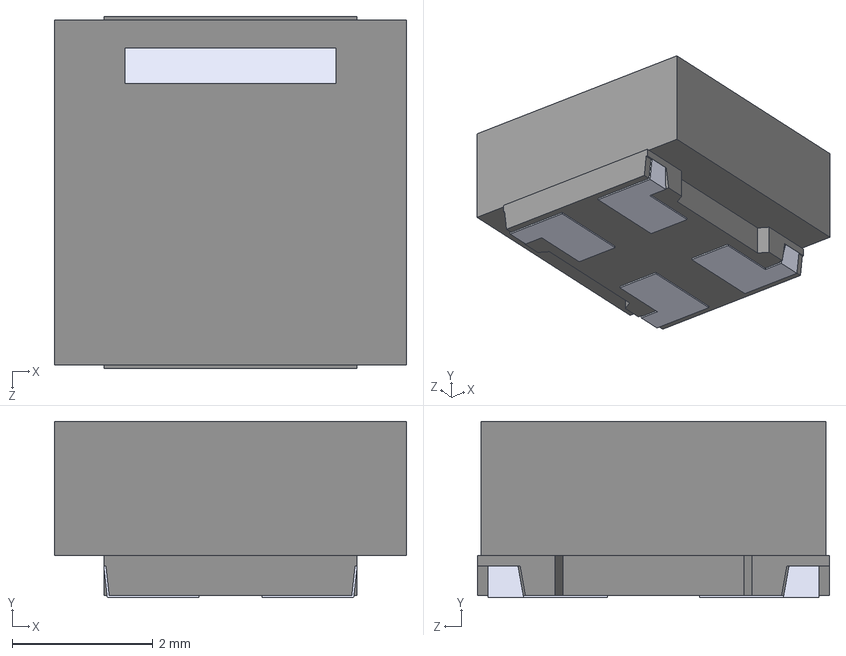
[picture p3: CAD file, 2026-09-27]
hardware/sst_v2/3d/DLW5BTM251SQ2L.step
5.00 x 2.50 x 5.00 mm

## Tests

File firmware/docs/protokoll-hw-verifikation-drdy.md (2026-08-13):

# Protokoll: Verifikation der Hardware-Annahmen (DRDY-Plan)

Datum: 2026-08-13. Geprüft vor Umsetzung von
[hardware-drdy-checklist.md](hardware-drdy-checklist.md) /
[plan-drdy-resampling.md](plan-drdy-resampling.md) AP0/AP1.
Methode: jede Annahme galt als falsch, bis Code, Datenblatt oder Rechnung
sie bestätigt hat.

## Ergebnis

**Die Hardware-Checkliste ist freigegeben.** Kein Fehler in den
Hardware-Annahmen gefunden. Drei Software-Referenzen des Plans sind
veraltet (Abschnitt 4). Sie blockieren die Hardware nicht.
AP0 Test 2 bleibt zwingendes Gate vor der Firmware-Kette.

## 1. Pins und Firmware (gegen Code geprüft)

| # | Annahme | Quelle | Befund |
|---|---|---|---|
| 1 | Fork = i2c0, SDA GP8, SCL GP9 | `hardware_config.h:68` | ✓ — B2 korrekt |
| 2 | Shock = i2c1, SDA GP14, SCL GP15 | `hardware_config.h:78` | ✓ — B3 korrekt |
| 3 | SD-SPI: spi0, 6,75 MHz, GP16–19 | `hardware_config.h:47` | ✓ — Störer aus A4 real |
| 4 | SDIO-Build hätte D2 auf GP21 | `hardware_config.h:56` (D0=19, D2=D0+2) | ✓ — aktiver Preset ist SPI (`CMakePresets.json:39`), GP21 frei |
| 5 | Buzzer GP22 | `buzzer.h:6` | ✓ |
| 6 | Buzzer nach Startton statisch | `buzzer.c:11` (silence-Alarm setzt Level 0) | ✓ mit Hinweis, s. Abschnitt 5 |
| 7 | I²C-Takt 1 MHz | `linear_ads1115.c:94` | ✓ |
| 8 | Pico-interne Pull-ups aktiv | `linear_ads1115.c:97` | ✓ |
| 9 | Beide Module Adresse 0x48, getrennte Busse | `linear_ads1115.c:36`, `:40` | ✓ — ADDR-Pull-down plausibel |
| 10 | Wiper auf A0, A1 frei | `linear_ads1115.c:106` (`MUX_SINGLE_0`) | ✓ — Phase E kollisionsfrei |
| 11 | PGA 4,096, Continuous, 860 SPS | `linear_ads1115.c:107` | ✓ |
| 12 | Lib-Setter für Comparator fehlen | `external/pico-ads1115/include/ads1115.h:112` | ✓ — auskommentiert |
| 13 | Alte FW lässt COMP_QUE = disable → ALERT hochohmig | Lib-Default 0x8583, FW schreibt COMP-Bits nie (`registers.h:96`, `linear_ads1115.c:106`) | ✓ — D1-Messung (3,3 V Ruhepegel) gültig |
| 14 | `MUX_SINGLE_1` in Lib vorhanden | `registers.h:31` | ✓ |
| 15 | Globaler GPIO-Callback von pushbutton belegt | `pushbutton.c:59` | ✓ — Raw-Handler-Ansatz nötig |
| 16 | Poll-Takt −1000000/860 = 1162 µs = 860,585 Hz | `main.c:137`, `main.c:435` | ✓ |
| 17 | Header: 2 Byte Padding vor 64-bit-Zeit, 16 Byte | `sst.h:29`, `gosst/formats/sst/sst.go:14`, Bridge `RawTelemetryData.cs` (HeaderSize 16, Bytes 6–8 Padding, nur Magic-Gate) | ✓ |
| 18 | SD-Burst 8 KB alle ~2,4 s | `sst.h:47` (2048 × 4 B), 2048/860,585 Hz = 2,38 s | ✓ |
| 19 | WLAN bestromt, nicht assoziiert, Power-Save | `main.c:823`, Kommentar `main.c:608` | ✓ |
| 20 | Belegte GPIOs 2–5, 8, 9, 14–19, 22, 23–25, 29; frei 6, 7, 10–13, 20, 21, 26–28 | alle `gpio_init`/`gpio_set_function`-Stellen + `PICO_BOARD pico_w` (`CMakeLists.txt:17`) | ✓ — Debug-Builds nutzen zusätzlich GP0/1 (UART), berührt GP21/27 nicht |

## 2. RP2040 / Pico-Header (gegen Doku und Rechnung geprüft)

| # | Annahme | Prüfung | Befund |
|---|---|---|---|
| 21 | GP21 = Slice 2B, GP27 = 5B, GP26 = 5A, GP22 = 3A, GP13 = 6B | Slice = (GP>>1)&7, B = ungerade | ✓ alle fünf |
| 22 | Nur B-Kanal zählt Flanken (`PWM_DIV_B_FALLING`) | RP2040-Datenblatt / SDK-Enum | ✓ |
| 23 | GPIO-IRQ greift Pad ab, unabhängig vom Funcsel | RP2040-Datenblatt | ✓ — AP0 verifiziert zusätzlich empirisch |
| 24 | Header-Pins: GP21=27, GP27=32, GP8=11, GP9=12, GP14=19, GP15=20, GND=28, AGND=33, GP19=25, GP20=26, GP22=29, GP26=31, GP28=34, 3V3=36 | offizielles Pinout | ✓ alle 14 Angaben |
| 25 | RP2040 nicht 5-V-tolerant; Schmitt-Eingänge default an; interner Pull-up ~56 kΩ | Datenblatt | ✓ |
| 26 | `timerawl` wrappt nach 71,6 min | 2³² µs | ✓ |

## 3. Elektrik (nachgerechnet)

| # | Annahme | Rechnung | Befund |
|---|---|---|---|
| 27 | 10 k ∥ 56 k = 8,5 kΩ; t_r 216 ns @30 pF, 360 ns @50 pF | t_r = 0,847·RC | ✓ — Fm+ (120 ns) verletzt, Fm (300 ns) grenzwertig, wie im Plan |
| 28 | 2,2 k ∥ 10 k = 1,80 kΩ; 46/76 ns | dito | ✓ — beide Spec-Fenster eingehalten |
| 29 | Senkstrom 1,83 mA < 3 mA (ADS1115 VOL-Spec) | 3,3 V / 1,803 kΩ | ✓ — mit internem Pull-up 1,89 mA, weiter ok |
| 30 | Messwerte B1 ≈ 10 kΩ, B5 ≈ 1,8 kΩ (Gerät aus) | s. o. | ✓ |
| 31 | 26400 Counts = exakt 3,3/4,096·32768 | 32768/4096·3300 = 8·3300 | ✓ — identisch `MAX_ADC_3P3V` (`linear_ads1115.c:15`); 2^14,6883 ≈ 26400 konsistent |
| 32 | `baseline_norm` passt in uint16 | Wiper ≤ Speisung ⇒ ≤ 26400 | ✓ |
| 33 | DRDY-Puls ~8 µs aktiv-low; Hi=0x8000/Lo=0x0000 + COMP_QUE≠11 aktiviert ihn; ALERT bei QUE_DISABLE hochohmig; Abs-Max Analog = VDD+0,3 V | ADS1115-Datenblatt | ✓ — physischer Nachweis bleibt AP0 Test 2 |
| 34 | Fork ~832 / Shock ~850–859 SPS plausibel | Datenraten-Toleranz ±10 %; konsistent mit 28-Hz-Schwebung (860,585 − 832,6 ≈ 28) | ✓ als Hypothese — Messung in AP0 |
| 35 | 10-s-Zählfenster ohne Überlauf | 16-bit-PWM-Zähler, max ~8590 Counts | ✓ — Grenze: Fenster > ~75 s liefe über |

## 4. Abweichungen — Plan veraltet (nur Software, Hardware unberührt)

1. **gosst:** `CurrentProcessingVersion` ist **9** (`psst.go:106`), nicht 7.
   AP7-Bump muss 9 → 10 heißen.
2. **Bridge:** `CurrentProcessingVersion` ist **30** (`TelemetryData.cs:180`),
   nicht 28. AP7b-Bump muss 30 → 31 heißen. `SampleRate` jetzt Zeile 187.
3. **gosst-Signaturen bereits geändert** (Dead-Band-Umbau):
   `forkVelocityZeroThreshold` jetzt `psst.go:127`,
   `shockVelocityZeroThreshold` `:131`, `calculateDerivative` `:226`,
   alle mit Zusatzparameter `travelPerLsb`. AP7-Fundstellenliste vor
   Umsetzung neu erheben.
4. Kleinere Zeilendrifts ohne Wirkung: `main.c:821`→`:823`;
   Bridge `RawTelemetryData.cs` neu geschrieben, Semantik unverändert.

## 5. Hinweis (neu, unkritisch)

`on_rec_start` (`main.c:423`) startet den Buzzer-Chirp vor dem Timer; der
letzte Ton endet per Alarm bis ~150 ms **nach** Timerstart. GP22 toggelt
also mit 4,5 kHz in die ersten DRDY-IRQs hinein. Bewertung: Pin 28 (GND)
liegt zwischen GP22 und GP21, Frequenz niedrig, Intervall-Gate deckt den
Rest — keine Maßnahme nötig. Falls `glitch_count` in AP8 nur am
Aufnahmestart zählt, ist das die erste Verdachtsquelle.

## 6. Nur am Gerät prüfbar (bleibt offen, im Plan so vorgesehen)

- DRDY pulst überhaupt / Polarität / Breite → AP0 Test 2 (Showstopper-Gate).
- Reale SPS je Kanal (Schwellen für das Intervall-Gate) → AP0 Test 2.
- VDD = 3,3 V an beiden Modulen → Phase 0.3.
- Pinreihenfolge am Modul beim Löten gegen Silkscreen prüfen (bisher nur
  per Foto belegt).
- Buskapazität ~30 pF ist Schätzwert; Rechnung hält bis 50 pF
  (400 kHz + 1,8 kΩ), Marge ausreichend.

## Freigabe

Phasen 0, A, B, C, D, E der Checkliste: **umsetzbar wie beschrieben.**
Reihenfolge einhalten: Phase 0 (Referenzaufnahme!) vor jedem Eingriff,
AP0 Test 2 vor der Firmware-Kette.

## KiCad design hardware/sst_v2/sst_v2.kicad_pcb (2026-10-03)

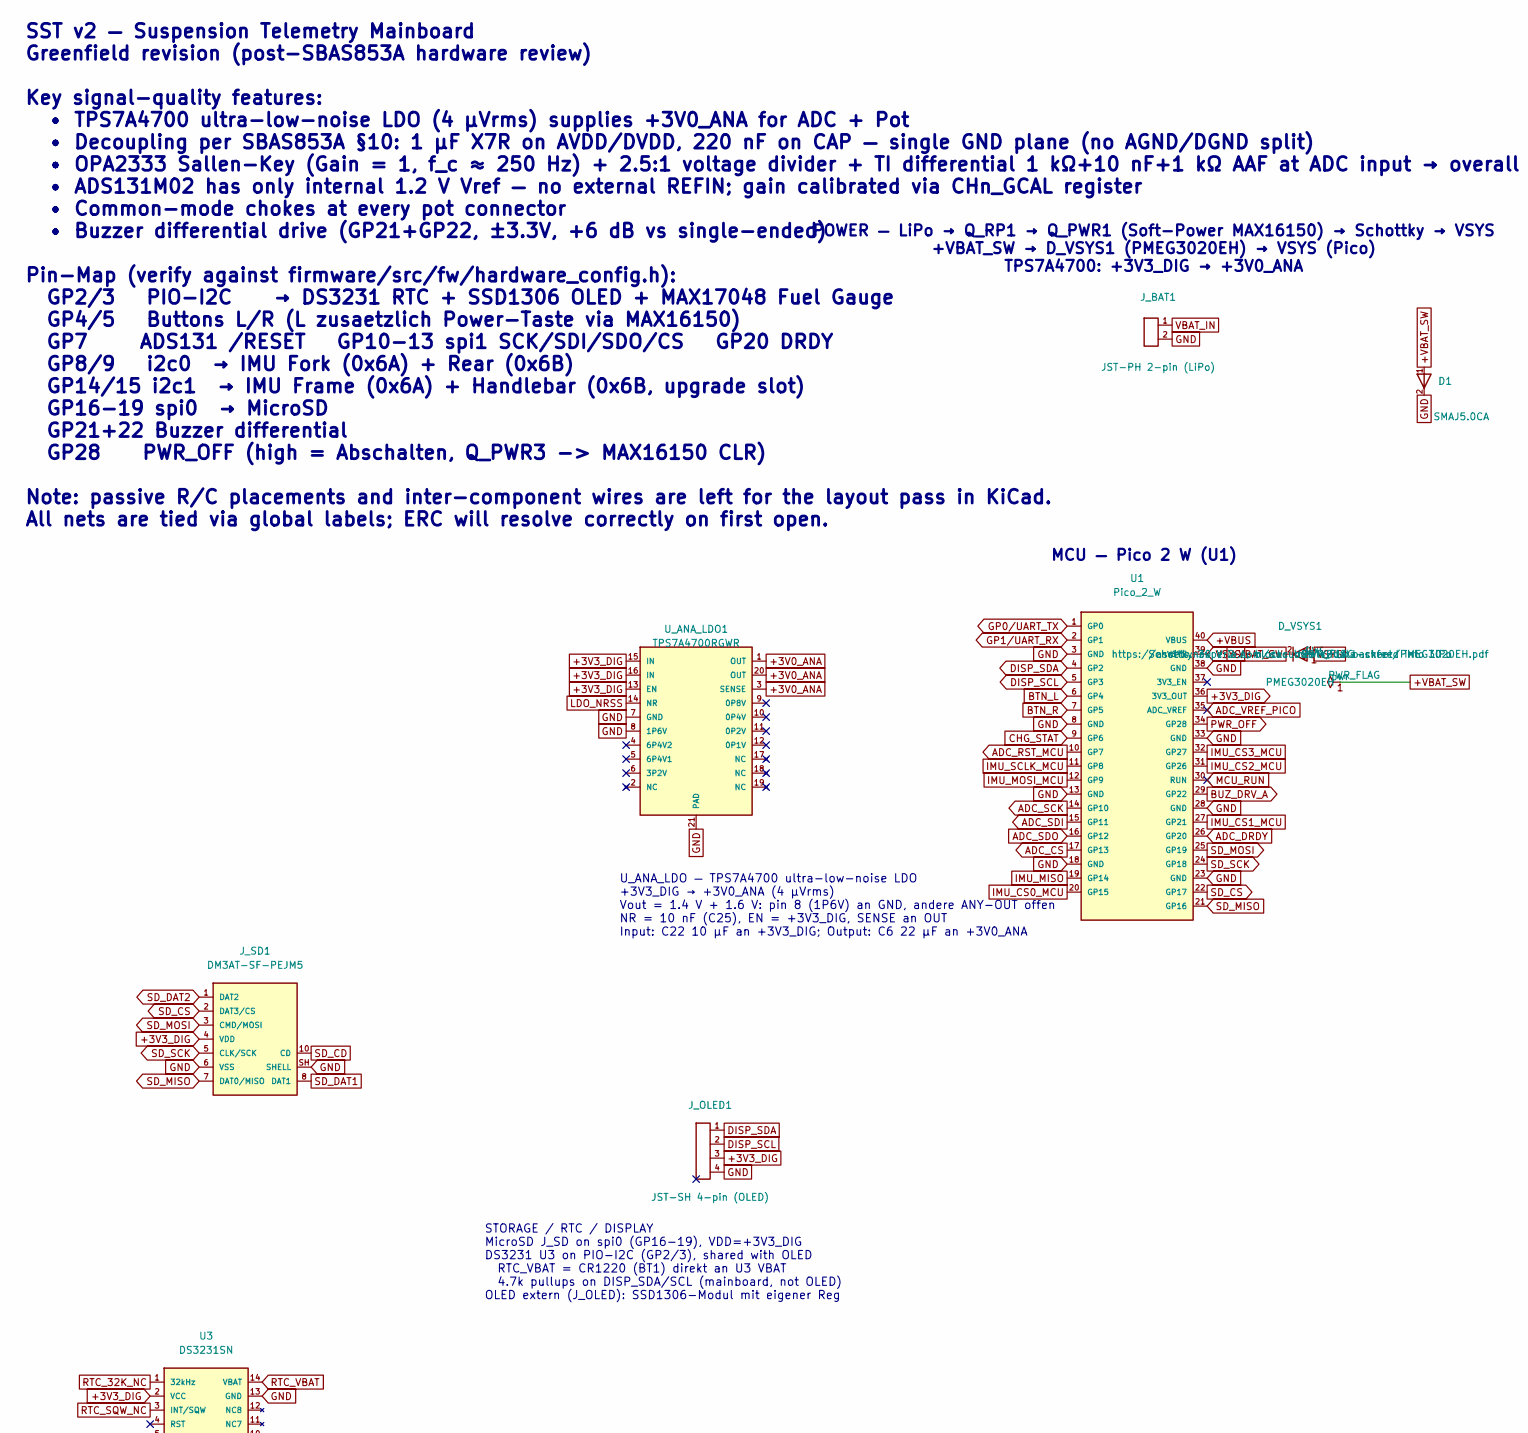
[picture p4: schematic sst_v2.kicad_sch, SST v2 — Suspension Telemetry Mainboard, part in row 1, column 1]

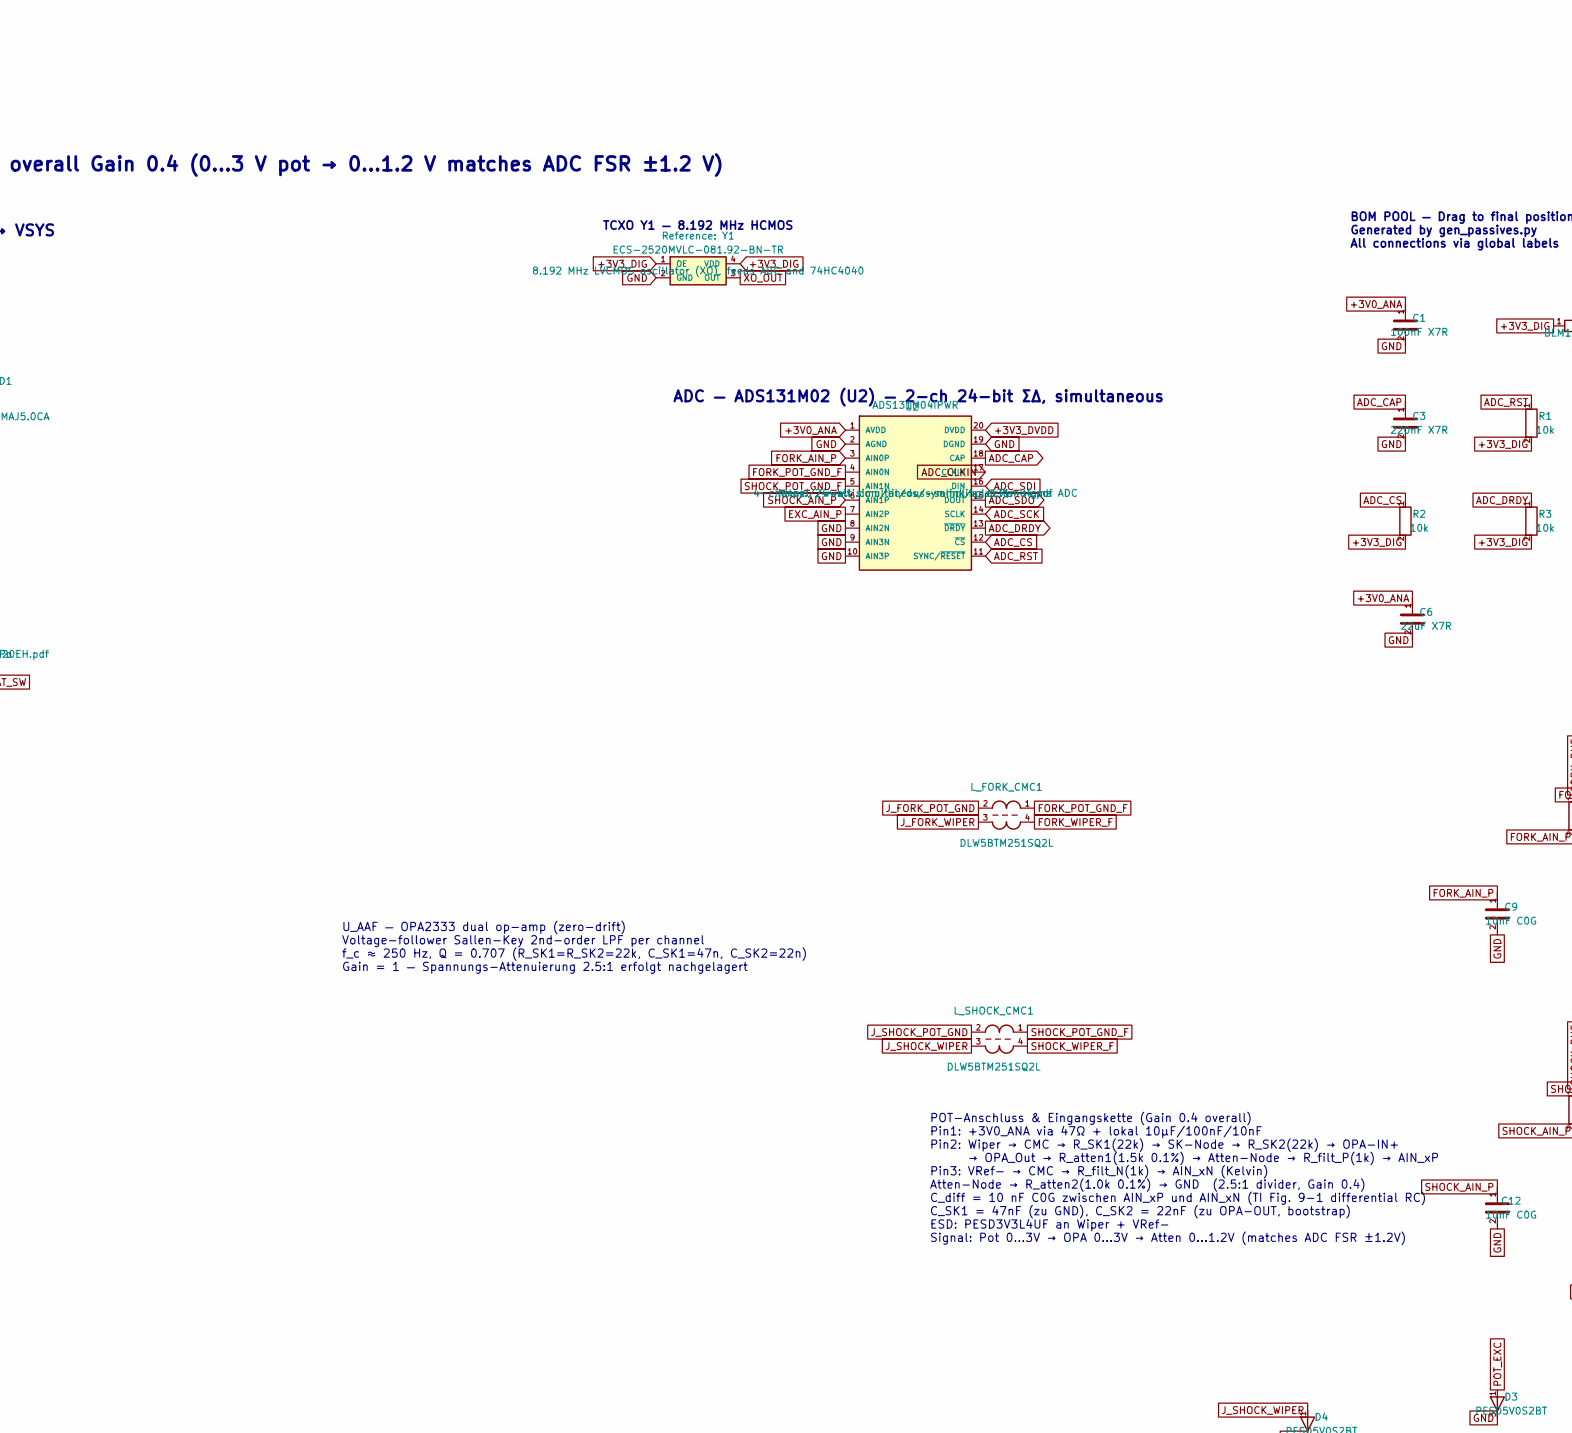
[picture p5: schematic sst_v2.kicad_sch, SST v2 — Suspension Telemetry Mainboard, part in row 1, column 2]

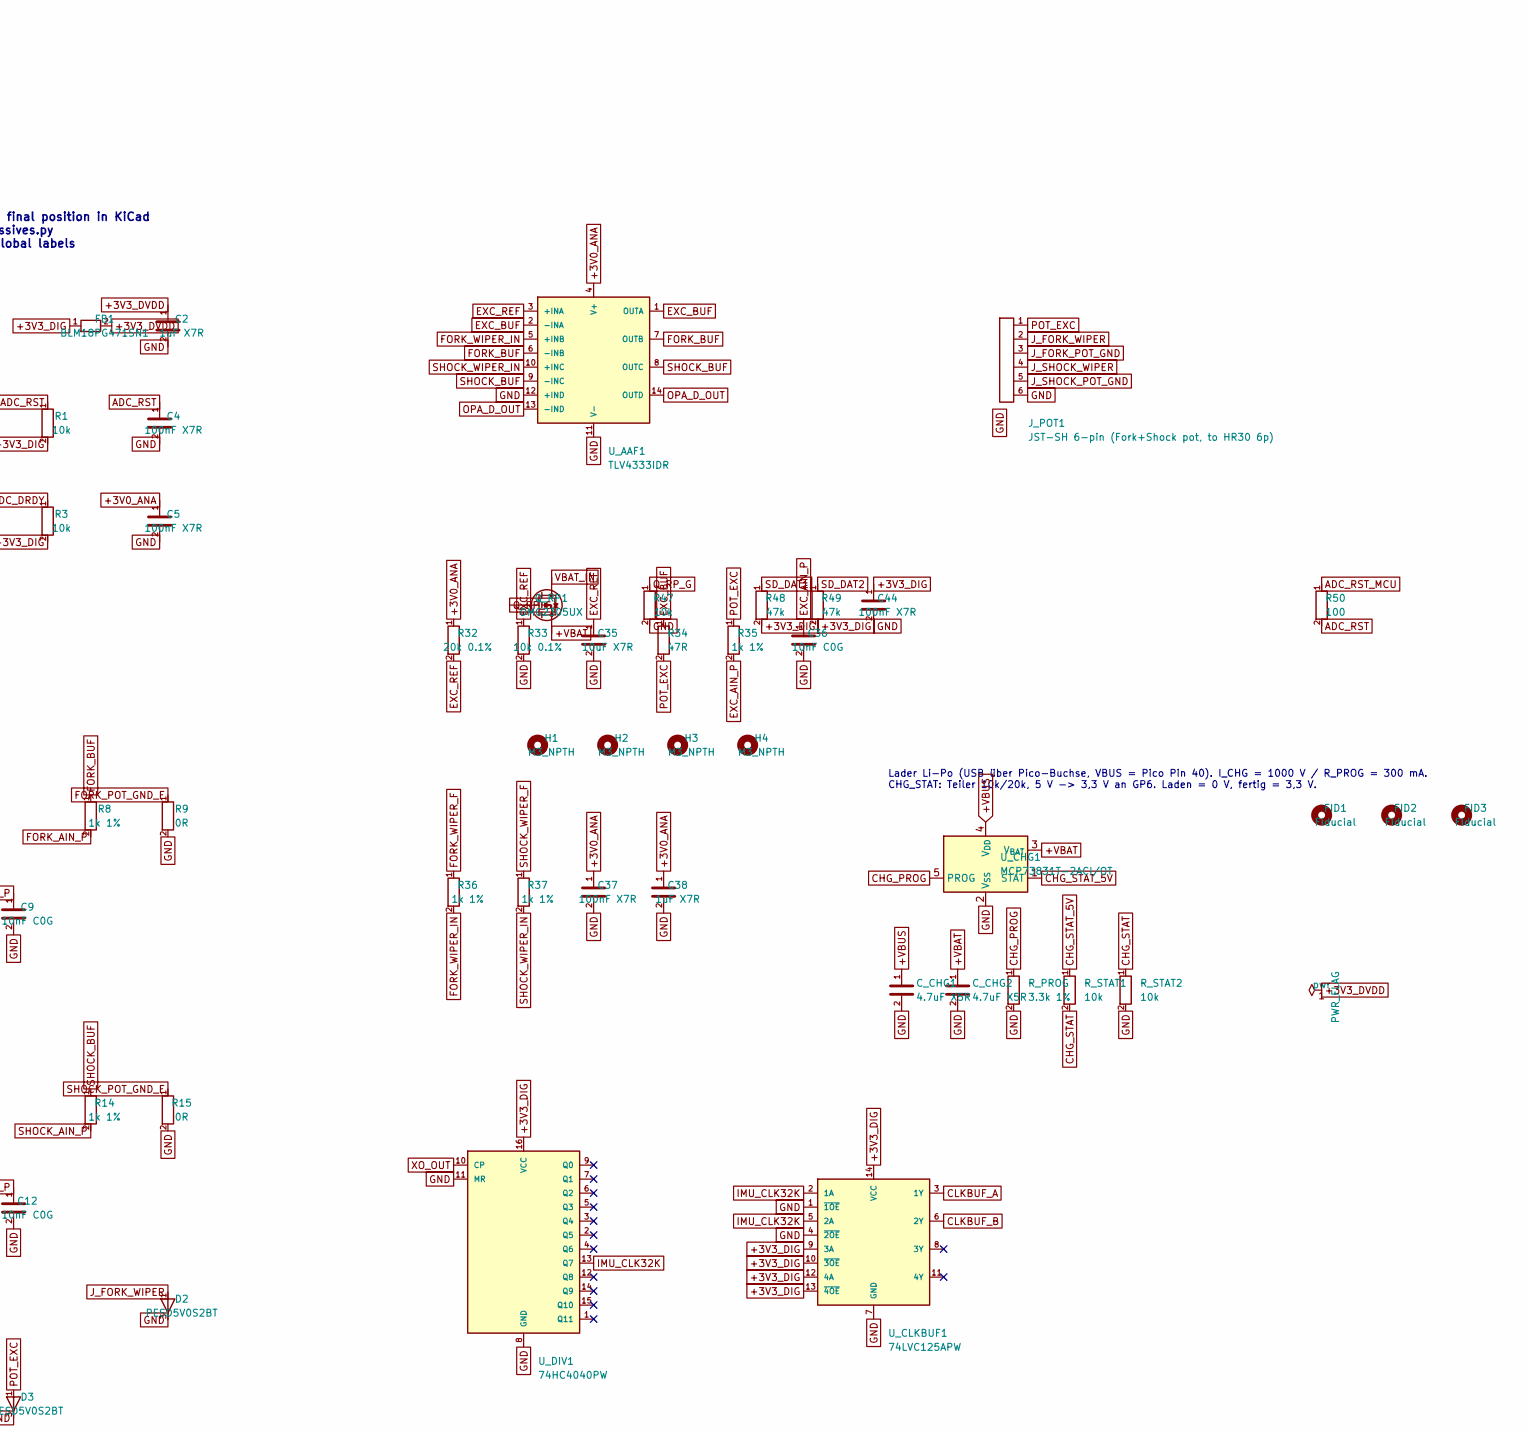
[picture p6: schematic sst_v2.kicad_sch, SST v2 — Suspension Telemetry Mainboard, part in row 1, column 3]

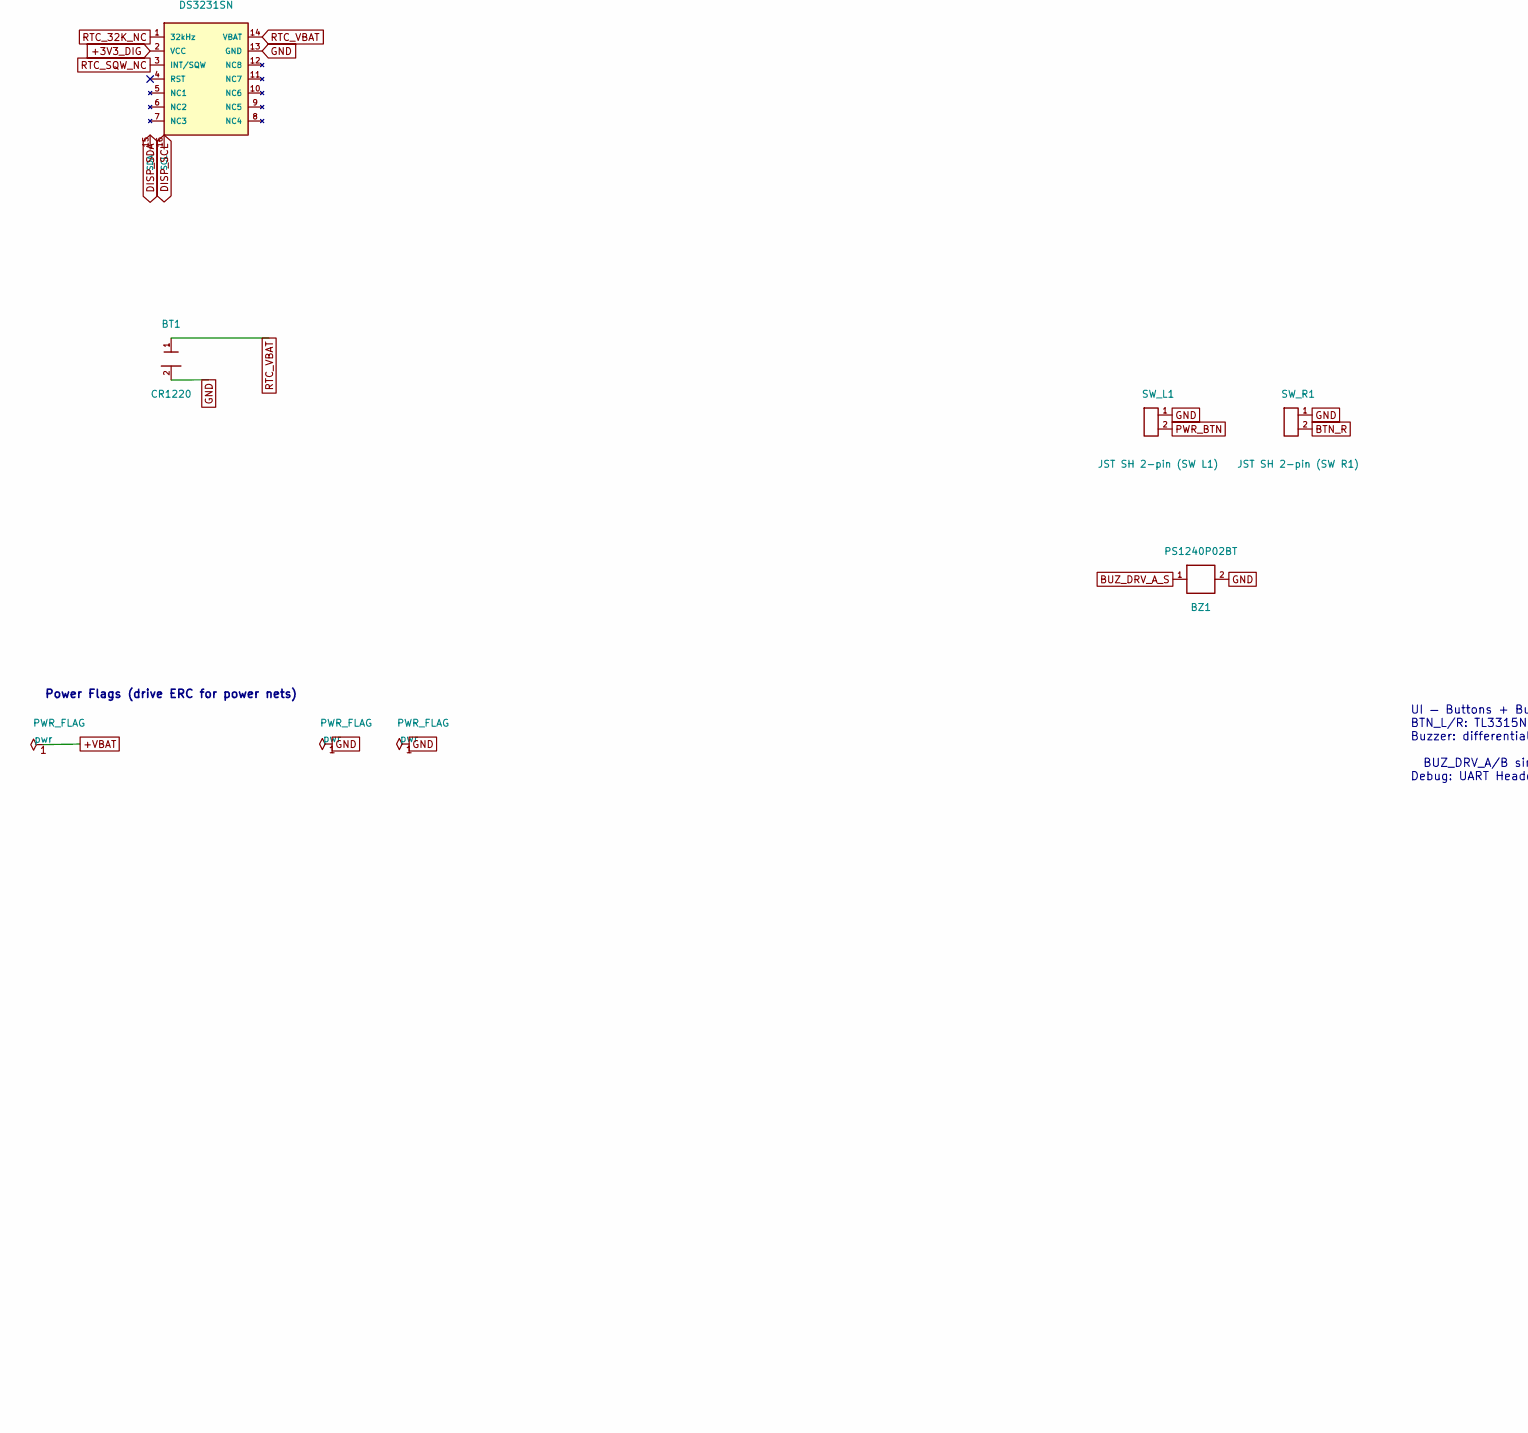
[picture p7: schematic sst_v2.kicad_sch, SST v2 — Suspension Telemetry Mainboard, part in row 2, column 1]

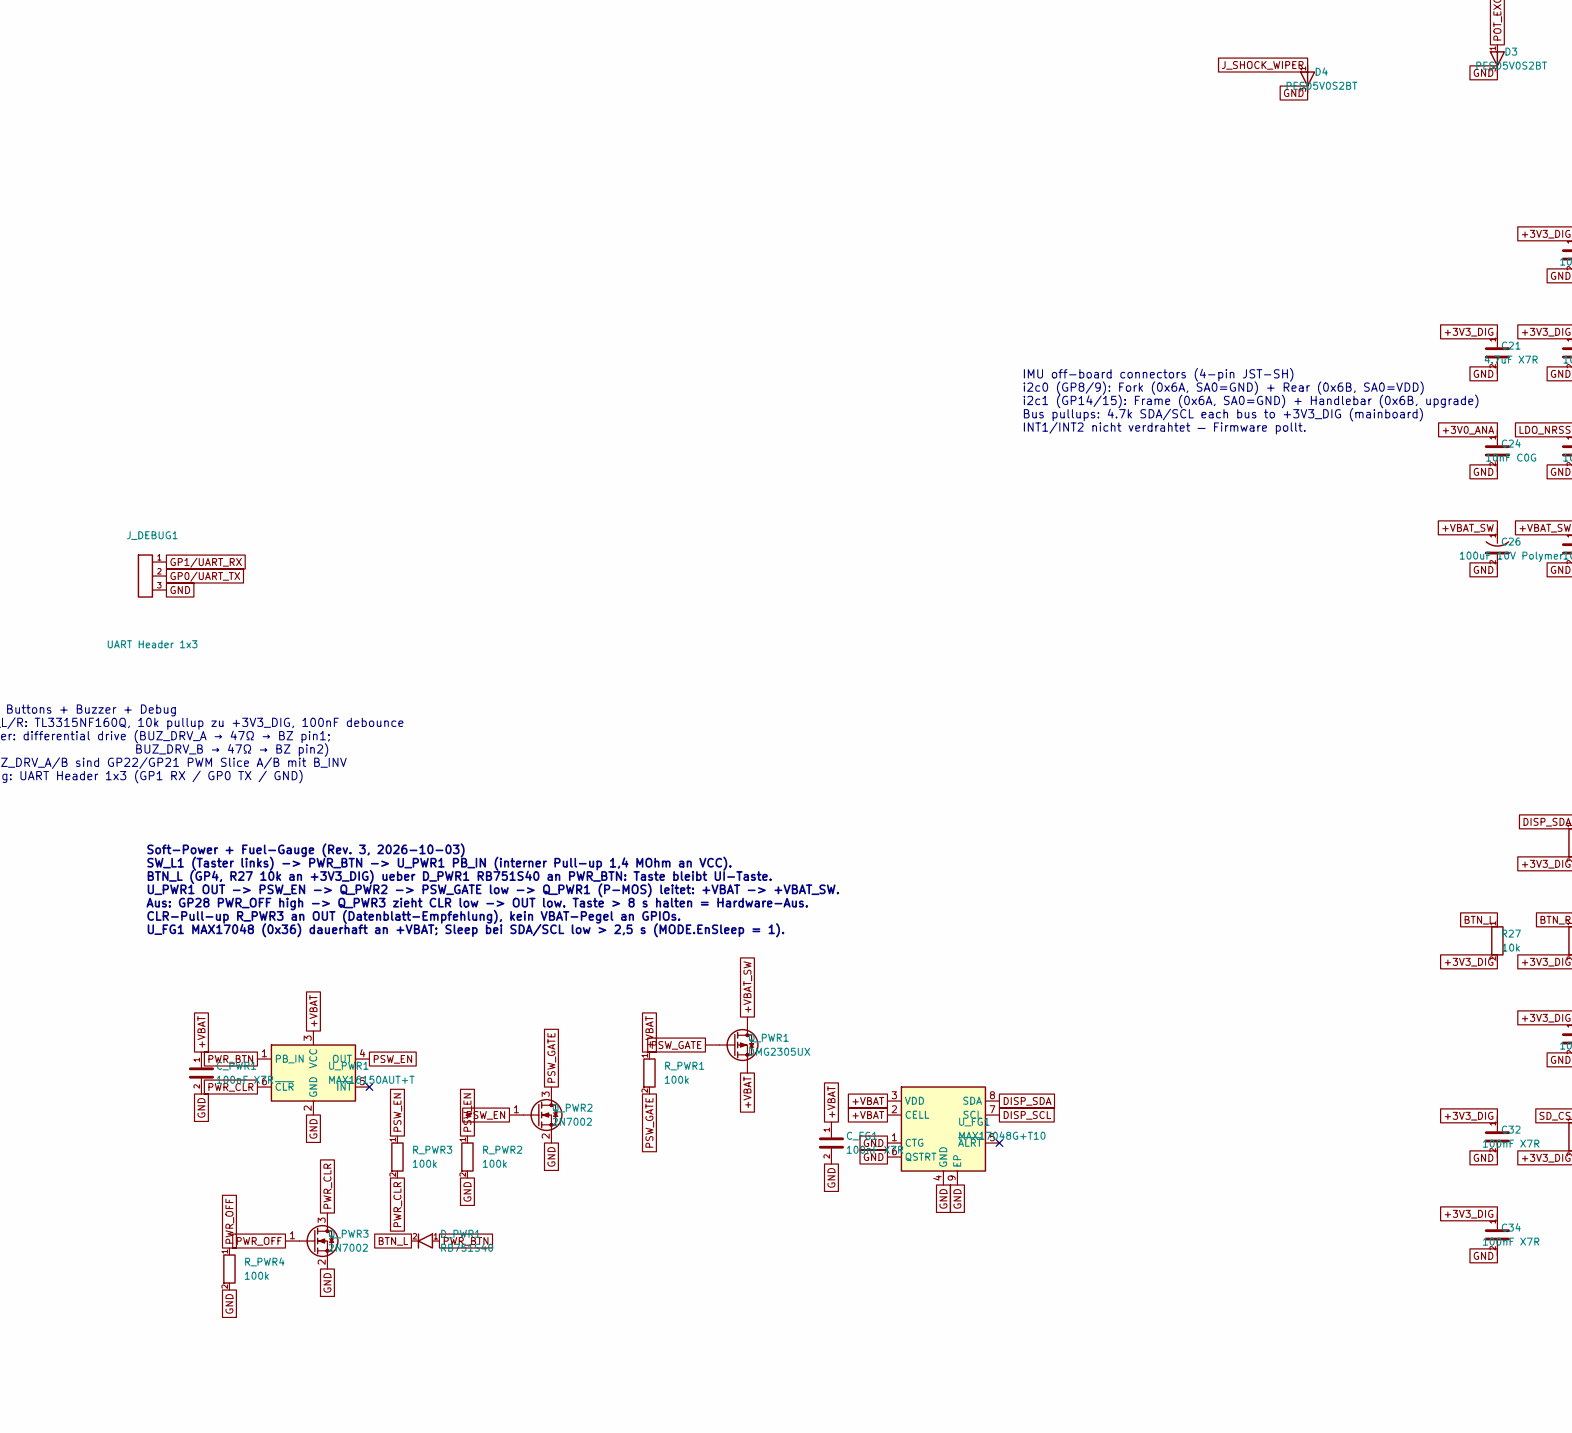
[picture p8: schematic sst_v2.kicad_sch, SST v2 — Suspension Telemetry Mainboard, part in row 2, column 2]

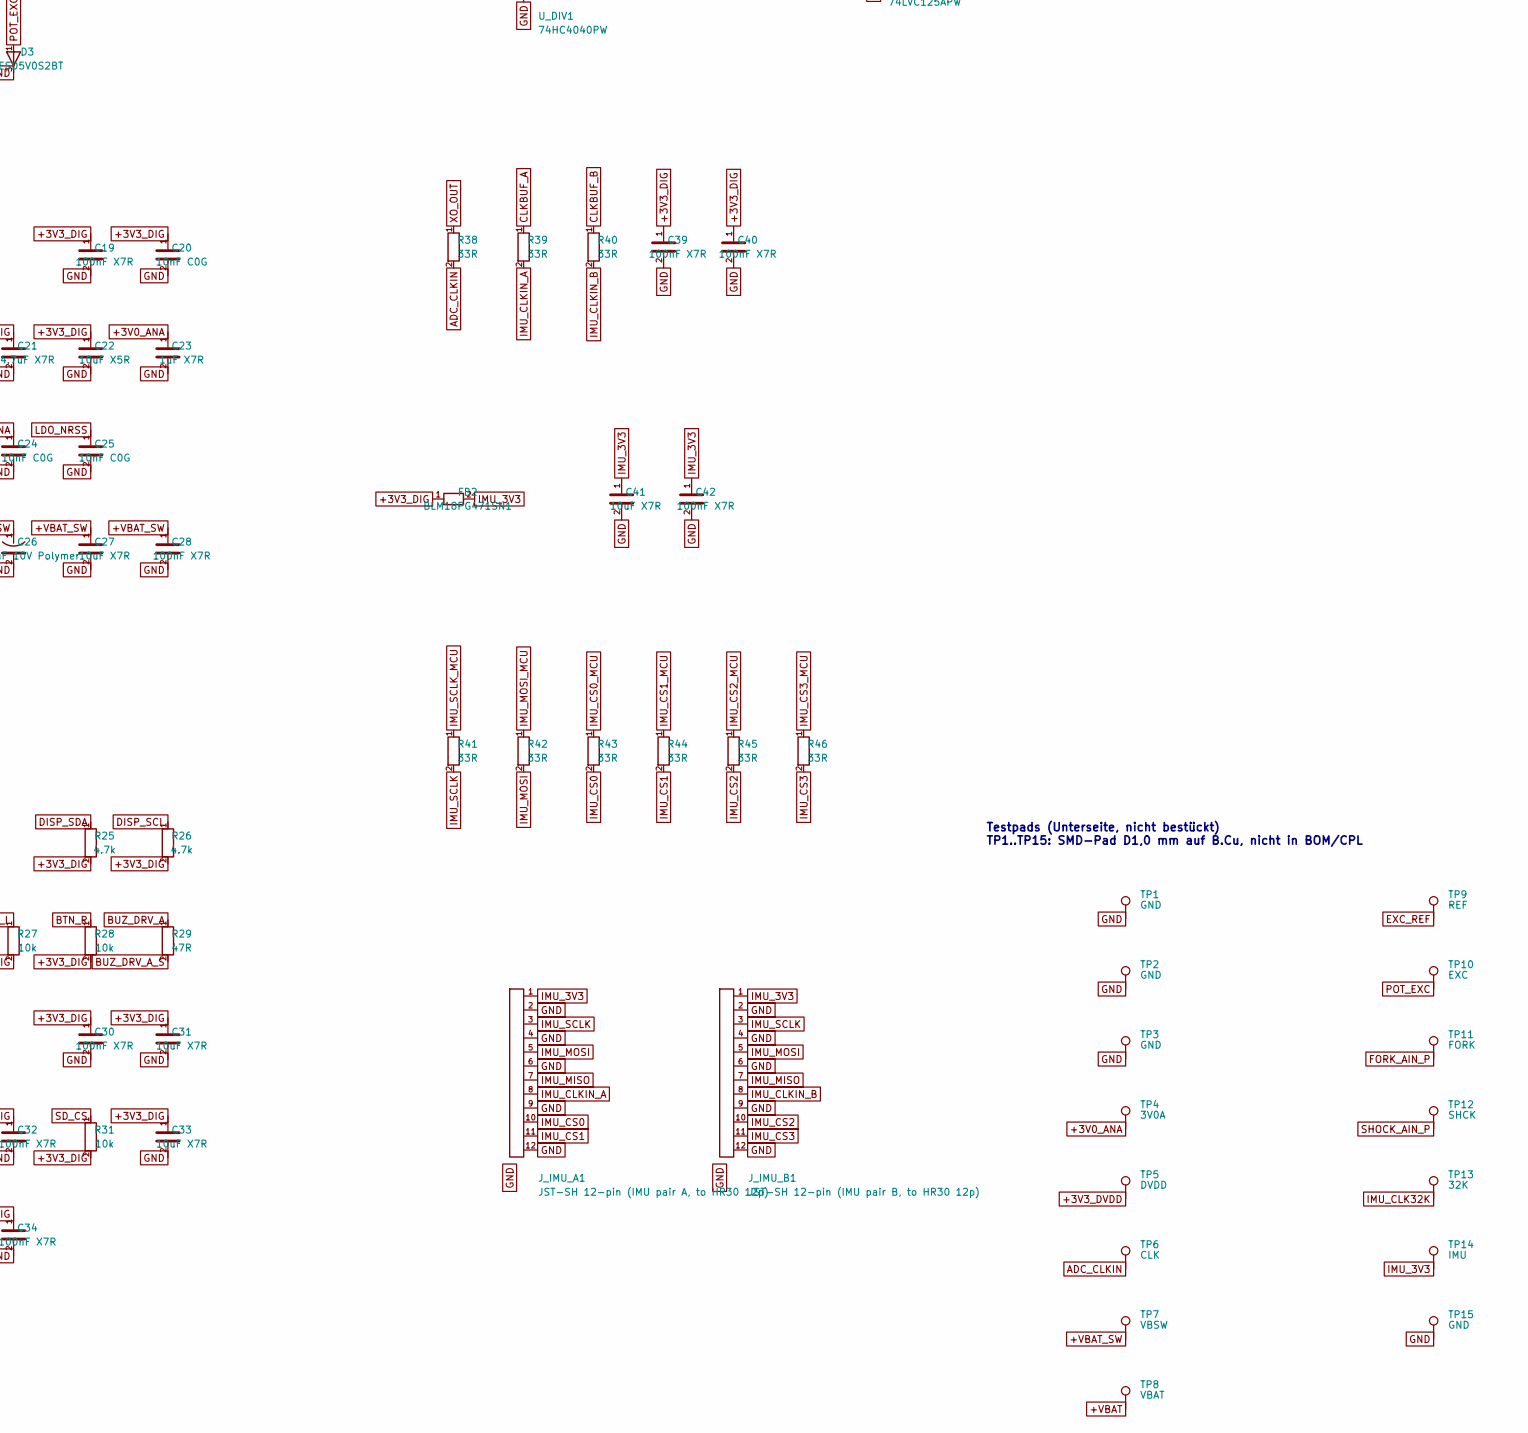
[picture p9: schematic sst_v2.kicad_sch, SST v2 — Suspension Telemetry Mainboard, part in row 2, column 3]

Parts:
BT1: CR1220; BatteryHolder_Keystone_3001_1x12mm
BZ1: PS1240P02BT; Buzzer_TDK_PS1240P02BT_D12.2mm_H6.5mm
C1, C4, C5, C19, C28, C30, C32, C34, C37, C39, C40, C42, C44: 100nF X7R; C_0603_1608Metric
C2, C23, C38: 1uF X7R; C_0603_1608Metric
C3: 220nF X7R; C_0603_1608Metric
C6: 22uF X7R; C_0805_2012Metric
C9, C12, C20, C24, C25, C36: 10nF C0G; C_0603_1608Metric
C21: 4.7uF X7R; C_0805_2012Metric
C22: 10uF X5R; C_0603_1608Metric
C26: 100uF 10V Polymer; CP_EIA-7343-31_Kemet-D
C27, C31, C33, C35, C41: 10uF X7R; C_0805_2012Metric
C_CHG1, C_CHG2: 4.7uF X5R; C_0805_2012Metric
C_FG1: 100nF X7R; C_0603_1608Metric
C_PWR1: 100nF X7R; C_0603_1608Metric
D1: SMAJ5.0CA; D_SMA
D2, D3, D4: PESD5V0S2BT; SOT-23
D_PWR1: RB751S40; D_SOD-523
D_VSYS1: PMEG3020EH; D_SOD-123F
FB1, FB2: BLM18PG471SN1; L_0603_1608Metric
FID1, FID2, FID3: Fiducial; Fiducial_1mm_Mask3mm
H1, H2, H3, H4: M3_NPTH; MountingHole_3.2mm_M3
J_BAT1: JST-PH 2-pin (LiPo); JST_PH_B2B-PH-K_1x02_P2.00mm_Vertical
J_DEBUG1: UART Header 1x3; PinHeader_1x03_P2.54mm_Vertical
J_IMU_A1: JST-SH 12-pin (IMU pair A, to HR30 12p); JST_SH_BM12B-SRSS-TB_1x12-1MP_P1.00mm_Vertical
J_IMU_B1: JST-SH 12-pin (IMU pair B, to HR30 12p); JST_SH_BM12B-SRSS-TB_1x12-1MP_P1.00mm_Vertical
J_OLED1: JST-SH 4-pin (OLED); JST_SH_BM04B-SRSS-TB_1x04-1MP_P1.00mm_Vertical
J_POT1: JST-SH 6-pin (Fork+Shock pot, to HR30 6p); JST_SH_BM06B-SRSS-TB_1x06-1MP_P1.00mm_Vertical
J_SD1: DM3AT-SF-PEJM5; microSD_HC_Hirose_DM3AT-SF-PEJM5
L_FORK_CMC1: DLW5BTM251SQ2L; L_CommonModeChoke_Murata_DLW5BTMxxxSQ2x_5x5mm
L_SHOCK_CMC1: DLW5BTM251SQ2L; L_CommonModeChoke_Murata_DLW5BTMxxxSQ2x_5x5mm
Q_PWR1: DMG2305UX; SOT-23
Q_PWR2, Q_PWR3: 2N7002; SOT-23
Q_RP1: DMG2305UX; SOT-23
R1, R2, R3, R27, R28, R31, R47: 10k; R_0603_1608Metric
R8, R14, R35, R36, R37: 1k 1%; R_0603_1608Metric
R9, R15: 0R; R_0603_1608Metric
R25, R26: 4.7k; R_0603_1608Metric
R29, R34: 47R; R_0603_1608Metric
R32: 20k 0.1%; R_0603_1608Metric
R33: 10k 0.1%; R_0603_1608Metric
R38, R39, R40, R41, R42, R43, R44, R45, R46: 33R; R_0603_1608Metric
R48, R49: 47k; R_0603_1608Metric
R50: 100; R_0603_1608Metric
R_PROG: 3.3k 1%; R_0603_1608Metric
R_PWR1, R_PWR2, R_PWR3, R_PWR4: 100k; R_0603_1608Metric
R_STAT1, R_STAT2: 10k; R_0603_1608Metric
SW_L1: JST SH 2-pin (SW L1); JST_SH_BM02B-SRSS-TB_1x02-1MP_P1.00mm_Vertical
SW_R1: JST SH 2-pin (SW R1); JST_SH_BM02B-SRSS-TB_1x02-1MP_P1.00mm_Vertical
TP1, TP2, TP3, TP15: GND; TestPoint_Pad_D1.0mm
TP4: 3V0A; TestPoint_Pad_D1.0mm
TP5: DVDD; TestPoint_Pad_D1.0mm
TP6: CLK; TestPoint_Pad_D1.0mm
TP7: VBSW; TestPoint_Pad_D1.0mm
TP8: VBAT; TestPoint_Pad_D1.0mm
TP9: REF; TestPoint_Pad_D1.0mm
TP10: EXC; TestPoint_Pad_D1.0mm
TP11: FORK; TestPoint_Pad_D1.0mm
TP12: SHCK; TestPoint_Pad_D1.0mm
TP13: 32K; TestPoint_Pad_D1.0mm
TP14: IMU; TestPoint_Pad_D1.0mm
U1: Pico_2_W; RaspberryPi_Pico_Common_THT
U2: ADS131M04IPWR; TSSOP-20_4.4x6.5mm_P0.65mm
U3: DS3231SN; SOIC-16W_7.5x10.3mm_P1.27mm
U_AAF1: TLV4333IDR; SOIC-14_3.9x8.7mm_P1.27mm
U_ANA_LDO1: TPS7A4700RGWR; Texas_RGW0020A_VQFN-20-1EP_5x5mm_P0.65mm_EP3.15x3.15mm
U_CHG1: MCP73831T-2ACI/OT; SOT-23-5
U_CLKBUF1: 74LVC125APW; TSSOP-14_4.4x5mm_P0.65mm
U_DIV1: 74HC4040PW; TSSOP-16_4.4x5mm_P0.65mm
U_FG1: MAX17048G+T10; TDFN-8-1EP_2x2mm_P0.5mm_EP0.8x1.2mm
U_PWR1: MAX16150AUT+T; SOT-23-6
Y1: ECS-2520MVLC-081.92-BN-TR; Oscillator_SMD_ECS_2520MV-xxx-xx-4Pin_2.5x2.0mm

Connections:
+3V0_ANA: C1.1, C5.1, C6.1, C23.1, C24.1, C37.1, C38.1, R32.1, TP4.1, U2.1 (AVDD), U_AAF1.4 (V+), U_ANA_LDO1.1 (OUT), U_ANA_LDO1.3 (SENSE), U_ANA_LDO1.20 (OUT)
+3V3_DIG: C19.1, C20.1, C21.1, C22.1, C30.1, C31.1, C32.1, C33.1, C34.1, C39.1, C40.1, C44.1, FB1.1, FB2.1, J_OLED1.3, J_SD1.4 (VDD), R1.2, R2.2, R3.2, R25.2, R26.2, R27.2, R28.2, R31.2, R48.2, R49.2, U1.36 (3V3_OUT), U3.2 (VCC), U_ANA_LDO1.13 (EN), U_ANA_LDO1.15 (IN), U_ANA_LDO1.16 (IN), U_CLKBUF1.9 (3A), U_CLKBUF1.10 (~3OE), U_CLKBUF1.12 (4A), U_CLKBUF1.13 (~4OE), U_CLKBUF1.14 (VCC), U_DIV1.16 (VCC), Y1.1 (OE), Y1.4 (VDD)
+3V3_DVDD: C2.1, FB1.2, TP5.1, U2.20 (DVDD)
+VBAT: C_CHG2.1, C_FG1.1, C_PWR1.1, Q_PWR1.2 (S), Q_RP1.2 (S), R_PWR1.1, TP8.1, U_CHG1.3 (V_{BAT}), U_FG1.2 (CELL), U_FG1.3 (VDD), U_PWR1.3 (VCC)
+VBAT_SW: C26.1, C27.1, C28.1, D1.1 (K), D_VSYS1.2 (A), Q_PWR1.3 (D), TP7.1
+VBUS: C_CHG1.1, U1.40 (VBUS), U_CHG1.4 (V_{DD})
ADC_CAP: C3.1, U2.18 (CAP)
ADC_CLKIN: R38.2, TP6.1, U2.17 (CLKIN)
ADC_CS: R2.1, U1.17 (GP13), U2.12 (~CS)
ADC_DRDY: R3.1, U1.26 (GP20), U2.13 (~DRDY)
ADC_RST: C4.1, R1.1, R50.2, U2.11 (SYNC/~RESET)
ADC_RST_MCU: R50.1, U1.10 (GP7)
ADC_SCK: U1.14 (GP10), U2.14 (SCLK)
ADC_SDI: U1.15 (GP11), U2.16 (DIN)
ADC_SDO: U1.16 (GP12), U2.15 (DOUT)
ADC_VREF_PICO: U1.35 (ADC_VREF)
BTN_L: D_PWR1.2 (A), R27.1, U1.6 (GP4)
BTN_R: R28.1, SW_R1.2, U1.7 (GP5)
BUZ_DRV_A: R29.1, U1.29 (GP22)
BUZ_DRV_A_S: BZ1.1 (+), R29.2
CHG_PROG: R_PROG.1, U_CHG1.5 (PROG)
CHG_STAT: R_STAT1.2, R_STAT2.1, U1.9 (GP6)
CHG_STAT_5V: R_STAT1.1, U_CHG1.1 (STAT)
CLKBUF_A: R39.1, U_CLKBUF1.3 (1Y)
CLKBUF_B: R40.1, U_CLKBUF1.6 (2Y)
DISP_SCL: J_OLED1.2, R26.1, U1.5 (GP3), U3.16 (SCL), U_FG1.7 (SCL)
DISP_SDA: J_OLED1.1, R25.1, U1.4 (GP2), U3.15 (SDA), U_FG1.8 (SDA)
EXC_AIN_P: C36.1, R35.2, U2.7 (AIN2P)
EXC_BUF: R34.1, U_AAF1.1 (OUTA), U_AAF1.2 (-INA)
EXC_REF: C35.1, R32.2, R33.1, TP9.1, U_AAF1.3 (+INA)
FORK_AIN_P: C9.1, R8.2, TP11.1, U2.3 (AIN0P)
FORK_BUF: R8.1, U_AAF1.6 (-INB), U_AAF1.7 (OUTB)
FORK_POT_GND_F: L_FORK_CMC1.1, R9.1, U2.4 (AIN0N)
FORK_WIPER_F: L_FORK_CMC1.4, R36.1
FORK_WIPER_IN: R36.2, U_AAF1.5 (+INB)
GND: BT1.2 (-), BZ1.2 (-), C1.2, C2.2, C3.2, C4.2, C5.2, C6.2, C9.2, C12.2, C19.2, C20.2, C21.2, C22.2, C23.2, C24.2, C25.2, C26.2, C27.2, C28.2, C30.2, C31.2, C32.2, C33.2, C34.2, C35.2, C36.2, C37.2, C38.2, C39.2, C40.2, C41.2, C42.2, C44.2, C_CHG1.2, C_CHG2.2, C_FG1.2, C_PWR1.2, D1.2 (A), D2.3 (A), D3.3 (A), D4.3 (A), J_BAT1.2, J_DEBUG1.3, J_IMU_A1.2, J_IMU_A1.4, J_IMU_A1.6, J_IMU_A1.9, J_IMU_A1.12, J_IMU_A1.MP, J_IMU_B1.2, J_IMU_B1.4, J_IMU_B1.6, J_IMU_B1.9, J_IMU_B1.12, J_IMU_B1.MP, J_OLED1.4, J_POT1.6, J_POT1.MP, J_SD1.6 (VSS), J_SD1.SH (SHELL), Q_PWR2.2 (S), Q_PWR3.2 (S), R9.2, R15.2, R33.2, R47.2, R_PROG.2, R_PWR2.2, R_PWR4.2, R_STAT2.2, SW_L1.1, SW_R1.1, TP1.1, TP2.1, TP3.1, TP15.1, U1.3 (GND), U1.8 (GND), U1.13 (GND), U1.18 (GND), U1.23 (GND), U1.28 (GND), U1.33 (GND), U1.38 (GND), U2.2 (AGND), U2.8 (AIN2N), U2.9 (AIN3N), U2.10 (AIN3P), U2.19 (DGND), U3.13 (GND), U_AAF1.11 (V-), U_AAF1.12 (+IND), U_ANA_LDO1.7 (GND), U_ANA_LDO1.8 (1P6V), U_ANA_LDO1.21 (PAD), U_CHG1.2 (V_{SS}), U_CLKBUF1.1 (~1OE), U_CLKBUF1.4 (~2OE), U_CLKBUF1.7 (GND), U_DIV1.8 (GND), U_DIV1.11 (MR), U_FG1.1 (CTG), U_FG1.4 (GND), U_FG1.6 (QSTRT), U_FG1.9 (EP), U_PWR1.2 (GND), Y1.2 (GND)
GP0/UART_TX: J_DEBUG1.2, U1.1 (GP0)
GP1/UART_RX: J_DEBUG1.1, U1.2 (GP1)
IMU_3V3: C41.1, C42.1, FB2.2, J_IMU_A1.1, J_IMU_B1.1, TP14.1
IMU_CLK32K: TP13.1, U_CLKBUF1.2 (1A), U_CLKBUF1.5 (2A), U_DIV1.13 (Q7)
IMU_CLKIN_A: J_IMU_A1.8, R39.2
IMU_CLKIN_B: J_IMU_B1.8, R40.2
IMU_CS0: J_IMU_A1.10, R43.2
IMU_CS0_MCU: R43.1, U1.20 (GP15)
IMU_CS1: J_IMU_A1.11, R44.2
IMU_CS1_MCU: R44.1, U1.27 (GP21)
IMU_CS2: J_IMU_B1.10, R45.2
IMU_CS2_MCU: R45.1, U1.31 (GP26)
IMU_CS3: J_IMU_B1.11, R46.2
IMU_CS3_MCU: R46.1, U1.32 (GP27)
IMU_MISO: J_IMU_A1.7, J_IMU_B1.7, U1.19 (GP14)
IMU_MOSI: J_IMU_A1.5, J_IMU_B1.5, R42.2
IMU_MOSI_MCU: R42.1, U1.12 (GP9)
IMU_SCLK: J_IMU_A1.3, J_IMU_B1.3, R41.2
IMU_SCLK_MCU: R41.1, U1.11 (GP8)
J_FORK_POT_GND: J_POT1.3, L_FORK_CMC1.2
J_FORK_WIPER: D2.1 (K), J_POT1.2, L_FORK_CMC1.3
J_SHOCK_POT_GND: J_POT1.5, L_SHOCK_CMC1.2
J_SHOCK_WIPER: D4.1 (K), J_POT1.4, L_SHOCK_CMC1.3
LDO_NRSS: C25.1, U_ANA_LDO1.14 (NR)
MCU_RUN: U1.30 (RUN)
OPA_D_OUT: U_AAF1.13 (-IND), U_AAF1.14 (OUTD)
POT_EXC: D3.1 (K), J_POT1.1, R34.2, R35.1, TP10.1
PSW_EN: Q_PWR2.1 (G), R_PWR2.1, R_PWR3.1, U_PWR1.4 (OUT)
PSW_GATE: Q_PWR1.1 (G), Q_PWR2.3 (D), R_PWR1.2
PWR_BTN: D_PWR1.1 (K), SW_L1.2, U_PWR1.1 (PB_IN)
PWR_CLR: Q_PWR3.3 (D), R_PWR3.2, U_PWR1.6 (~CLR)
PWR_OFF: Q_PWR3.1 (G), R_PWR4.1, U1.34 (GP28)
Q_RP_G: Q_RP1.1 (G), R47.1
RTC_32K_NC: U3.1 (32kHz)
RTC_SQW_NC: U3.3 (INT/SQW)
RTC_VBAT: BT1.1 (+), U3.14 (VBAT)
SD_CD: J_SD1.10 (CD)
SD_CS: J_SD1.2 (DAT3/CS), R31.1, U1.22 (GP17)
SD_DAT1: J_SD1.8 (DAT1), R48.1
SD_DAT2: J_SD1.1 (DAT2), R49.1
SD_MISO: J_SD1.7 (DAT0/MISO), U1.21 (GP16)
SD_MOSI: J_SD1.3 (CMD/MOSI), U1.25 (GP19)
SD_SCK: J_SD1.5 (CLK/SCK), U1.24 (GP18)
SHOCK_AIN_P: C12.1, R14.2, TP12.1, U2.6 (AIN1P)
SHOCK_BUF: R14.1, U_AAF1.8 (OUTC), U_AAF1.9 (-INC)
SHOCK_POT_GND_F: L_SHOCK_CMC1.1, R15.1, U2.5 (AIN1N)
SHOCK_WIPER_F: L_SHOCK_CMC1.4, R37.1
SHOCK_WIPER_IN: R37.2, U_AAF1.10 (+INC)
VBAT_IN: J_BAT1.1, Q_RP1.3 (D)
VSYS: D_VSYS1.1 (K), U1.39 (VSYS)
XO_OUT: R38.1, U_DIV1.10 (CP), Y1.3 (OUT)

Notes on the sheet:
SST v2 — Suspension Telemetry Mainboard Greenfield revision (post-SBAS853A hardware review) Key signal-quality features: • TPS7A4700 ultra-low-noise LDO (4 µVrms) supplies +3V0_ANA for ADC + Pot • Decoupling per SBAS853A §10: 1 µF X7R on AVDD/DVDD, 220 nF on CAP — single GND plane (no AGND/DGND spl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
MCU — Pico 2 W (U1)
ADC — ADS131M02 (U2) — 2-ch 24-bit Σ∆, simultaneous
TCXO Y1 — 8.192 MHz HCMOS
U_AAF — OPA2333 dual op-amp (zero-drift) Voltage-follower Sallen-Key 2nd-order LPF per channel f_c ≈ 250 Hz, Q = 0.707 (R_SK1=R_SK2=22k, C_SK1=47n, C_SK2=22n) Gain = 1 — Spannungs-Attenuierung 2.5:1 erfolgt nachgelagert
POT-Anschluss & Eingangskette (Gain 0.4 overall) Pin1: +3V0_ANA via 47Ω + lokal 10µF/100nF/10nF Pin2: Wiper → CMC → R_SK1(22k) → SK-Node → R_SK2(22k) → OPA-IN+ → OPA_Out → R_atten1(1.5k 0.1%) → Atten-Node → R_filt_P(1k) → AIN_xP Pin3: VRef- → CMC → R_filt_N(1k) → AIN_xN (Kelvin) Atten-Node → R_atte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
U_ANA_LDO — TPS7A4700 ultra-low-noise LDO +3V3_DIG → +3V0_ANA (4 µVrms) Vout = 1.4 V + 1.6 V: pin 8 (1P6V) an GND, andere ANY-OUT offen NR = 10 nF (C25), EN = +3V3_DIG, SENSE an OUT Input: C22 10 µF an +3V3_DIG; Output: C6 22 µF an +3V0_ANA
POWER — LiPo → Q_RP1 → Q_PWR1 (Soft-Power MAX16150) → Schottky → VSYS +VBAT_SW → D_VSYS1 (PMEG3020EH) → VSYS (Pico) TPS7A4700: +3V3_DIG → +3V0_ANA
STORAGE / RTC / DISPLAY MicroSD J_SD on spi0 (GP16-19), VDD=+3V3_DIG DS3231 U3 on PIO-I2C (GP2/3), shared with OLED RTC_VBAT = CR1220 (BT1) direkt an U3 VBAT 4.7k pullups on DISP_SDA/SCL (mainboard, not OLED) OLED extern (J_OLED): SSD1306-Modul mit eigener Reg
IMU off-board connectors (4-pin JST-SH) i2c0 (GP8/9): Fork (0x6A, SA0=GND) + Rear (0x6B, SA0=VDD) i2c1 (GP14/15): Frame (0x6A, SA0=GND) + Handlebar (0x6B, upgrade) Bus pullups: 4.7k SDA/SCL each bus to +3V3_DIG (mainboard) INT1/INT2 nicht verdrahtet — Firmware pollt.
UI — Buttons + Buzzer + Debug BTN_L/R: TL3315NF160Q, 10k pullup zu +3V3_DIG, 100nF debounce Buzzer: differential drive (BUZ_DRV_A → 47Ω → BZ pin1; BUZ_DRV_B → 47Ω → BZ pin2) BUZ_DRV_A/B sind GP22/GP21 PWM Slice A/B mit B_INV Debug: UART Header 1x3 (GP1 RX / GP0 TX / GND)
Power Flags (drive ERC for power nets)
BOM POOL — Drag to final position in KiCad Generated by gen_passives.py All connections via global labels
Lader Li-Po (USB über Pico-Buchse, VBUS = Pico Pin 40). I_CHG = 1000 V / R_PROG = 300 mA. CHG_STAT: Teiler 10k/20k, 5 V -> 3,3 V an GP6. Laden = 0 V, fertig = 3,3 V.
Testpads (Unterseite, nicht bestückt) TP1..TP15: SMD-Pad D1,0 mm auf B.Cu, nicht in BOM/CPL
Soft-Power + Fuel-Gauge (Rev. 3, 2026-10-03) SW_L1 (Taster links) -> PWR_BTN -> U_PWR1 PB_IN (interner Pull-up 1,4 MOhm an VCC). BTN_L (GP4, R27 10k an +3V3_DIG) ueber D_PWR1 RB751S40 an PWR_BTN: Taste bleibt UI-Taste. U_PWR1 OUT -> PSW_EN -> Q_PWR2 -> PSW_GATE low -> Q_PWR1 (P-MOS) leitet: +VBAT -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

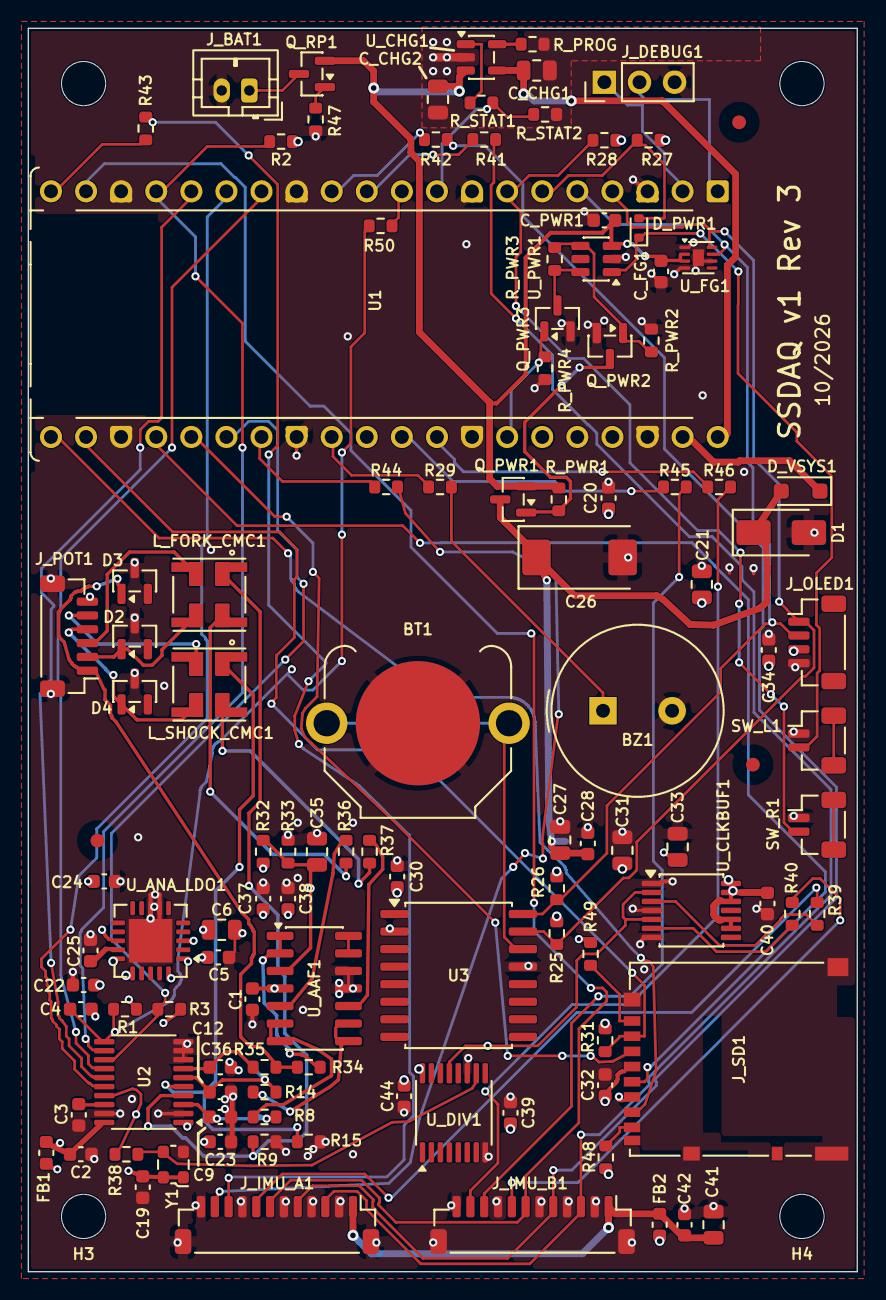
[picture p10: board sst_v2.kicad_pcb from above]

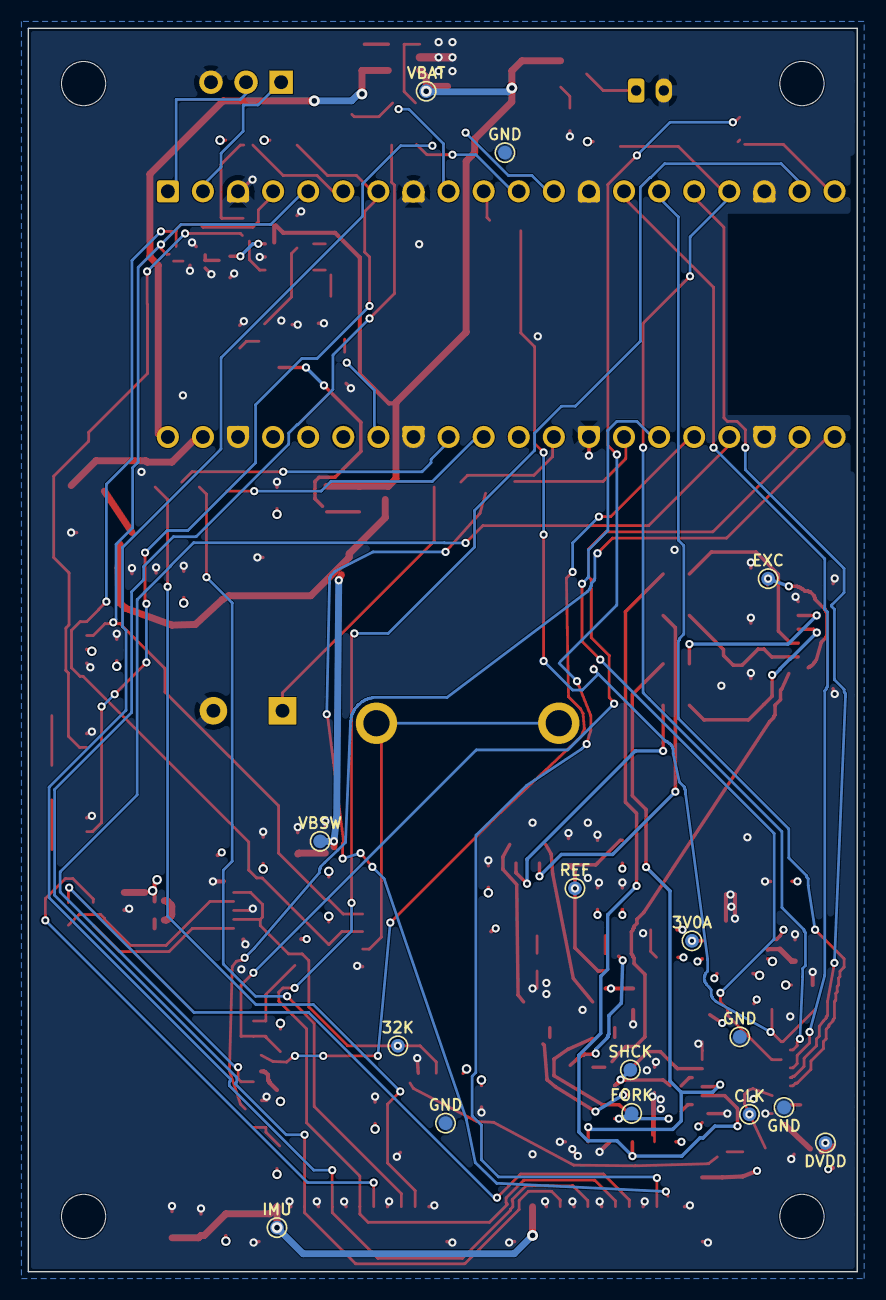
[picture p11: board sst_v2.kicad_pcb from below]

Board: 4 copper layers, 60.0 x 90.0 mm, 133 parts (15 on the bottom side), 82 nets.

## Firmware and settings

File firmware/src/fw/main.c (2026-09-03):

#include <stdint.h>
#include <stdarg.h>
#include <stdio.h>
#include <time.h>

#include "cyw43_ll.h"
#include "device/usbd.h"
#include "pico/platform.h"
#include "pico/multicore.h"
#include "pico/cyw43_arch.h"
#include "pico/sleep.h"
#include "pico/time.h"
#include "pico/types.h"
#include "pico/unique_id.h"
#include "pico/runtime_init.h"
#include "hardware/adc.h"
#include "hardware/gpio.h"
#include "hardware/rtc.h"
#include "hardware/rosc.h"
#include "hardware/structs/timer.h"
#include "hardware/timer.h"
#include "hardware/watchdog.h"
#include "hardware/structs/usb.h"
#include "bsp/board.h"
#include "ff.h"

// For scb_hw so we can enable deep sleep
#include "hardware/structs/scb.h"

#include "sst.h"
#include "../ntp//ntp.h"
#include "../net/tcpserver.h"
#include "../rtc//ds3231.h"
#include "../util/list.h"
#include "../util/config.h"
#include "../sensor/sensor.h"
#include "../sensor/drdy_ring.h"

#include "hardware_config.h"
#include "buzzer.h"
#include "boardid.h"

// On Pico W the RT6154 PS pin hangs on cyw43 WL_GPIO1; high = forced PWM, low = PFM allowed (default).
#define SMPS_FORCE_PWM_WL_GPIO 1

// Buzzer resonance sweep test. Comment out the define to disable.
// Runs once after display init, using the SWEEP_* range below.
// #define BUZZER_SWEEP_TEST
#ifdef BUZZER_SWEEP_TEST
#define SWEEP_FROM_HZ  4800
#define SWEEP_TO_HZ    5600
#define SWEEP_STEP_HZ    25
#define SWEEP_STEP_MS   500
#endif

static volatile enum state state;

// Whether the wireless chip came up in the MSC boot path — VSYS can only be
// read while it is powered (see on_msc).
static bool msc_vsys_ok;
static const uint32_t MSC_BOOT_MAGIC = 0x4d534321; // "MSC!"
// Hang detection in MSC state: a watchdog (MSC_WATCHDOG_MS) is armed while
// in MSC, scratch[5] carries MSC_HANG_MAGIC and scratch[4] the phase code of
// the blocking call in flight (see MSC_PHASE_* and msc_disk.c). After a
// watchdog reset with the magic set, main() shows "HANG P<n>" (or "PANIC"
// with the message, see sst_panic) for 10 s and re-enters MSC state. A
// deliberate soft_reset() clears both first.
// History: the MSC session used to die ~20 s after the host mounted the
// volume. Diagnosed 2026-09-03 with exactly this machinery: a TinyUSB 0.17
// panic "ep 03 was already available", see __wrap_dcd_edpt_clear_stall.
static const uint32_t MSC_HANG_MAGIC = 0x48414e47; // "HANG"
#define MSC_WATCHDOG_MS 4000
#define MSC_PHASE_NONE     0
#define MSC_PHASE_VSYS     1  // read_voltage()
#define MSC_PHASE_TUD      2  // tud_task()
// 3 = sd init, 4 = sd read, 5 = sd write: set in msc_disk.c
// (HardFaults are caught by the SD library's isr_hardfault, which resets
// immediately; a panic() goes through sst_panic below.)
// panic() replacement (PICO_PANIC_FUNCTION, CMakeLists.txt). The stock panic
// prints over UART and then spins; with the stdio UART driver registered by
// TinyUSB's board_init() that print itself hung forever (seen at
// uart_tx_wait_blocking). Keep the format string's flash address and reboot,
// main() shows it after the reset when in the MSC path.
static const uint32_t PANIC_MAGIC = 0x50414e49; // "PANI"
void __attribute__((noreturn)) sst_panic(const char *fmt, ...) {
    __asm volatile("cpsid i");
    watchdog_hw->scratch[6] = (uint32_t)fmt;
    // First argument (the endpoint address for the TinyUSB rp2040 panics).
    va_list ap;
    va_start(ap, fmt);
    watchdog_hw->scratch[2] = va_arg(ap, uint32_t);
    va_end(ap);
    watchdog_hw->scratch[7] = PANIC_MAGIC;
    watchdog_enable(1, 1);
    while (1);
}

// Linker-wrapped dcd_edpt_clear_stall (see CMakeLists.txt). macOS sends
// CLEAR_FEATURE(ENDPOINT_HALT) on the MSC bulk OUT endpoint as a data-toggle
// reset while the next-CBW receive is already armed. TinyUSB 0.17's
// usbd_edpt_clear_stall() then clears the endpoint's busy flag, the MSC class
// re-arms the CBW transfer, and the rp2040 port panics because the old buffer
// is still marked AVAIL ("ep 03 was already available"). Disarm the buffer
// first so the re-issued transfer starts clean. Upstream TinyUSB fixed this
// in dcd_edpt_clear_stall by aborting and re-issuing the in-flight transfer.
void __real_dcd_edpt_clear_stall(uint8_t rhport, uint8_t ep_addr);
void __wrap_dcd_edpt_clear_stall(uint8_t rhport, uint8_t ep_addr) {
    uint8_t num = ep_addr & 0x0f;
    if (num != 0) {
        if (ep_addr & 0x80) {
            usb_dpram->ep_buf_ctrl[num].in = 0;
        } else {
            usb_dpram->ep_buf_ctrl[num].out = 0;
        }
    }
    __real_dcd_edpt_clear_stall(rhport, ep_addr);
}

static uint32_t scb_orig;
static uint32_t clock0_orig;
static uint32_t clock1_orig;

static ssd1306_t disp;
static FIL recording;
static struct tcpserver server;

struct ds3231 rtc;

extern struct sensor fork_sensor;
extern struct sensor shock_sensor;
extern uint16_t linear_sensor_ads1115_last_c_exc(struct sensor *sensor);

#ifdef DEBUG
#define debug_printf(...) printf(__VA_ARGS__)
#else
#define debug_printf(...)
#endif

// ----------------------------------------------------------------------------
// Helper functions

static void display_message(ssd1306_t *disp, char *message) {
    ssd1306_clear(disp);
    ssd1306_draw_string(disp, 0, 10, 2, message);
    ssd1306_show(disp);
}

static void soft_reset() {
      watchdog_enable(1, 1);
      while(1);
}

static bool on_battery() {
    cyw43_thread_enter();
    bool ret = !cyw43_arch_gpio_get(2);
    cyw43_thread_exit();
    return ret;
}

// The missing /3 for the sample sum and *3 for the VSYS/3 divider cancel deliberately.
static float read_voltage() {
    cyw43_thread_enter();
    // Wake the wireless chip: in power-save it clamps the shared ADC3/GPIO29
    // line to ~0 V, which reads as an unplugged supply. Any cyw43 GPIO access
    // wakes it (see pico-examples read_vsys).
    cyw43_arch_gpio_get(2);
    sleep_ms(1); // NOTE ADC3 readings are way too high without this sleep.
    adc_gpio_init(29);   // GPIO29 measures VSYS/3
    adc_select_input(3); // GPIO29 is ADC #3
    uint32_t vsys = 0;
    for(int i = 0; i < 3; i++) {
        vsys += adc_read();
    }
    cyw43_thread_exit();
    const float conversion_factor = 3.3f / (1 << 12);
    float ret = vsys * conversion_factor;
    return ret;
}

static bool msc_present_timeout(uint32_t timeout_us) {
    uint32_t t = time_us_32();
    while (!tud_ready()) {
        if (time_us_32() - t > timeout_us) {
            return false;
        }
        tud_task();
    }
    return true;
}

static bool msc_present() {
    // Wait for a maximum of 1 second for USB MSC to initialize
    return msc_present_timeout(1000000);
}

static bool wifi_connect(bool do_ntp) {
    cyw43_arch_enable_sta_mode();
    bool ret = cyw43_arch_wifi_connect_timeout_ms(config.ssid, config.psk, CYW43_AUTH_WPA2_AES_PSK, 20000) == 0;
    if (ret && do_ntp) {
        sync_rtc_to_ntp();
    }
    return ret;
}

static void wifi_disconnect() {
    cyw43_arch_disable_sta_mode();
    sleep_ms(100);
}

static void calibrate_if_needed() {
    gpio_init(BUTTON_LEFT);
    gpio_pull_up(BUTTON_LEFT);

    FRESULT fr = f_stat("CALIBRATION", NULL);
    if (fr != FR_OK || !gpio_get(BUTTON_LEFT)) {
        state = CAL_IDLE_1;
    } else {
        state = IDLE;
    }
}

// ----------------------------------------------------------------------------
// Data acquisition

static const uint16_t SAMPLE_RATE = 860;

// 1000000 = 860 * 1162 + 680. Carrying the remainder exactly makes the
// 43-tick pattern span precisely 50000 us, without accumulated drift.
static uint32_t grid_t_k_us;
static uint32_t grid_remainder;
static alarm_id_t grid_alarm_id;

// We are using two buffers. Data acquisition happens on core #1 into the active
// buffer (referred to by the pointer active_buffer) and we dump to Micro SD card
// on core #2.
//
// When the active buffer is filled on core #1,
//  - the buffer's pointer is sent to core #2 via the Pico's multicore FIFO
//  - the other buffer's address is read from the FIFO, and set as active buffer.
//  
// Core #2 waits until an address is sent from core #1, and
//  - dumps the content at that address to the card
//  - sends the buffer address to core #1 via FIFO 
// 

struct record databuffer1[BUFFER_SIZE];
struct record databuffer2[BUFFER_SIZE];
struct record * volatile active_buffer = databuffer1;
volatile uint16_t count = 0;

static int64_t data_acquisition_cb(alarm_id_t id, void *user_data) {
    (void)id;
    (void)user_data;

    if (count == BUFFER_SIZE) {
        count = 0;
        multicore_fifo_push_blocking(DUMP);
        multicore_fifo_push_blocking((uintptr_t)active_buffer);
        active_buffer = (struct record *)((uintptr_t)multicore_fifo_pop_blocking());
    }

    active_buffer[count].fork_angle =
        sensor_sample_at(&fork_sensor, grid_t_k_us);
    active_buffer[count].shock_angle =
        sensor_sample_at(&shock_sensor, grid_t_k_us);

    count += 1;

    uint32_t step = 1162;
    grid_remainder += 680;
    if (grid_remainder >= 860) {
        step = 1163;
        grid_remainder -= 860;
    }
    grid_t_k_us += step;

    // A negative delay is relative to the scheduled alarm time, not the actual
    // callback time. That prevents late-tick jitter from accumulating as drift.
    return state == RECORD ? -(int64_t)step : 0;
}

static bool wait_for_sensors_ready(void) {
    absolute_time_t timeout = make_timeout_time_ms(100);
    while ((fork_sensor.available && !sensor_ready(&fork_sensor)) ||
           (shock_sensor.available && !sensor_ready(&shock_sensor))) {
        if (absolute_time_diff_us(get_absolute_time(), timeout) < 0) {
            return false;
        }
        sleep_ms(1);
    }
    return true;
}

static bool report_sensor_counters(struct sensor *sensor,
                                   enum drdy_channel channel,
                                   const char *name) {
    if (!sensor->sample_at) {
        return false;
    }

    struct drdy_ring_counters counters = drdy_ring_get_counters(channel);
    debug_printf(
        "%s drdy=%lu late=%lu i2c=%lu glitch=%lu short=%lu before=%lu "
        "after=%lu torn=%lu\n",
        name, (unsigned long)counters.drdy_count,
        (unsigned long)counters.late_count,
        (unsigned long)counters.i2c_err_count,
        (unsigned long)counters.glitch_count,
        (unsigned long)counters.resample_short_count,
        (unsigned long)counters.resample_before_count,
        (unsigned long)counters.resample_after_count,
        (unsigned long)counters.resample_torn_count);

    // Show only one counter per channel to bound the delay. Priority is sorted
    // by data loss first, then timing anomalies, then held-value fallbacks.
    const char *counter = NULL;
    uint32_t value = 0;
    if (counters.i2c_err_count != 0) {
        counter = "I";
        value = counters.i2c_err_count;
    } else if (counters.resample_torn_count != 0) {
        counter = "T";
        value = counters.resample_torn_count;
    } else if (counters.late_count != 0) {
        counter = "L";
        value = counters.late_count;
    } else if (counters.glitch_count != 0) {
        counter = "G";
        value = counters.glitch_count;
    } else if (counters.resample_before_count != 0) {
        counter = "B";
        value = counters.resample_before_count;
    } else if (counters.resample_after_count != 0) {
        counter = "A";
        value = counters.resample_after_count;
    } else if (counters.resample_short_count != 0) {
        counter = "S";
        value = counters.resample_short_count;
    } else {
        return false;
    }

    char msg[10];
    if (value > 9999) {
        snprintf(msg, sizeof(msg), "%s %s:9999+", name, counter);
    } else {
        snprintf(msg, sizeof(msg), "%s %s:%lu", name, counter,
                 (unsigned long)value);
    }
    display_message(&disp, msg);
    sleep_ms(2000);
    return true;
}

static bool start_sensors() {
    absolute_time_t timeout = make_timeout_time_ms(3000);
    while (!(fork_sensor.check_availability(&fork_sensor) || shock_sensor.check_availability(&shock_sensor))) {
        if (absolute_time_diff_us(get_absolute_time(), timeout) < 0) {
            return false;
        }
        sleep_ms(10);
    }

    FIL calibration_fil;
    FRESULT fr = f_open(&calibration_fil, "CALIBRATION", FA_OPEN_EXISTING | FA_READ);
    if (!(fr == FR_OK || fr == FR_EXIST)) {
        return false;
    }

    uint br;
    uint16_t baseline;
    bool inverted;
    f_read(&calibration_fil, &baseline, sizeof(uint16_t), &br);
    f_read(&calibration_fil, &inverted, sizeof(bool), &br);
    fork_sensor.start(&fork_sensor, baseline, inverted);

    f_read(&calibration_fil, &baseline, sizeof(uint16_t), &br);
    f_read(&calibration_fil, &inverted, sizeof(bool), &br);
    shock_sensor.start(&shock_sensor, baseline, inverted);

    f_close(&calibration_fil);

    return fork_sensor.available || shock_sensor.available;
}

// ----------------------------------------------------------------------------
// Data storage
static int setup_storage() {
    static FATFS fs;
    FRESULT fr = f_mount(&fs, "", 1);
    if (fr != FR_OK) {
        return PICO_ERROR_GENERIC;
    }

    char board_id_str[2 * PICO_UNIQUE_BOARD_ID_SIZE_BYTES + 1];
    pico_get_unique_board_id_string(board_id_str, 2 * PICO_UNIQUE_BOARD_ID_SIZE_BYTES + 1);
    FIL f;
    uint btw;
    fr = f_open(&f, "BOARDID", FA_CREATE_NEW | FA_WRITE);
    if (fr == FR_OK) {
        f_write(&f, board_id_str, 2*PICO_UNIQUE_BOARD_ID_SIZE_BYTES, &btw);
    }
    f_close(&f);

    fr = f_mkdir("uploaded");
    if (!(fr == FR_OK || fr == FR_EXIST)) {
        return PICO_ERROR_GENERIC;
    }

    fr = f_mkdir("trash");
    if (!(fr == FR_OK || fr == FR_EXIST)) {
        return PICO_ERROR_GENERIC;
    }

    return 0;
}

// Read on core 0, consumed by open_datafile() on core 1. See the write site.
static volatile time_t pending_timestamp = 0;

static int open_datafile() {
    // start from 1, 0 is the special value for the headers in tcpserver
    uint16_t index = 1;
    FIL index_fil;
    FRESULT fr = f_open(&index_fil, "INDEX", FA_OPEN_EXISTING | FA_READ);
    if (fr == FR_OK || fr == FR_EXIST) {
        uint br;
        f_read(&index_fil, &index, 2, &br);
        if (br == 2) {
            index = index + 1;
        }
    }
    f_close(&index_fil);

    fr = f_open(&index_fil, "INDEX", FA_OPEN_ALWAYS | FA_WRITE);
    if (fr == FR_OK) {
        f_lseek(&index_fil, 0);
        uint bw;
        f_write(&index_fil, &index, 2, &bw);
        f_close(&index_fil);
    } else {
        return PICO_ERROR_GENERIC;
    }

    char filename[10];
    sprintf(filename, "%05u.SST", index);
    fr = f_open(&recording, filename, FA_CREATE_NEW | FA_WRITE);
    if (fr != FR_OK) {
        return fr;
    }

    // DS3231 and the display share the PIO-I2C SM. Display runs on core 0,
    // open_datafile() on core 1, so the timestamp is read on core 0 into
    // pending_timestamp. A plain global, not extra FIFO words: the OPEN
    // handler drains the FIFO before it runs, which would eat any word
    // pushed after OPEN. push(OPEN) / pop(index) is the ordering barrier.
    struct header h = {"SST", 4, SAMPLE_RATE, pending_timestamp};
    f_write(&recording, &h, sizeof(struct header), NULL);

    return index;
}

static void data_storage_core1() {
    int err = setup_storage();
    multicore_fifo_push_blocking(err);

    int index;
    enum command cmd;
    uint16_t size;
    struct record *buffer;
    while (true) {
        cmd = (enum command)multicore_fifo_pop_blocking();
        switch(cmd) {
            case OPEN:
                multicore_fifo_drain();
                index = open_datafile();
                multicore_fifo_push_blocking(index);
                multicore_fifo_push_blocking((uintptr_t)databuffer2);
                break;
            case DUMP:
                buffer = (struct record *)((uintptr_t)multicore_fifo_pop_blocking());
                multicore_fifo_push_blocking((uintptr_t)buffer);
                f_write(&recording, buffer, sizeof(struct record)*BUFFER_SIZE, NULL);
                f_sync(&recording);
                break;
            case FINISH:
                size = (uint16_t)multicore_fifo_pop_blocking();
                buffer = (struct record *)((uintptr_t)multicore_fifo_pop_blocking());
                f_write(&recording, buffer, sizeof(struct record)*size, NULL);
                f_sync(&recording);
                f_close(&recording);
                break;
        }
    }
}

// ----------------------------------------------------------------------------
// Setup functions

static void setup_display(ssd1306_t *disp) {
#ifdef SPI_DISPLAY
    spi_init(DISPLAY_SPI, 1000000);
    gpio_set_function(DISPLAY_PIN_SCK, GPIO_FUNC_SPI);  // SCK
    gpio_set_function(DISPLAY_PIN_MOSI, GPIO_FUNC_SPI); // MOSI

    disp->external_vcc = false;
    ssd1306_proto_t p = {
        DISPLAY_SPI,
        DISPLAY_PIN_CS,   // CS
        DISPLAY_PIN_MISO, // DC
        DISPLAY_PIN_RST   // RST
    };
    ssd1306_init(disp, DISPLAY_WIDTH, DISPLAY_HEIGHT, p);
#else
    ssd1306_proto_t p = {DISPLAY_ADDRESS, I2C_PIO, I2C_SM, pio_i2c_write_blocking};
    ssd1306_init(disp, DISPLAY_WIDTH, DISPLAY_HEIGHT, p);
#endif // SPI_DISPLAY
            
    ssd1306_flip(disp, DISPLAY_FLIPPED);
    ssd1306_clear(disp);
    ssd1306_show(disp);
}

// ----------------------------------------------------------------------------
// State handlers
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
int main() {
    board_init();
    buzzer_init();
    buzzer_sound_wake();
    tusb_init();
    rtc_init();
    adc_init();
    fork_sensor.init(&fork_sensor);
    shock_sensor.init(&shock_sensor);
#ifndef NDEBUG
    stdio_uart_init();
#endif

    uint offset = pio_add_program(I2C_PIO, &i2c_program);
    i2c_program_init(I2C_PIO, I2C_SM, offset, PIO_PIN_SDA, PIO_PIN_SDA+1);

    datetime_t dt;
    ds3231_init(&rtc, I2C_PIO, I2C_SM,
                pio_i2c_write_blocking,
                pio_i2c_read_blocking);
    sleep_ms(1); // without this, garbage values are read from the RTC
    ds3231_get_datetime(&rtc, &dt);
    rtc_set_datetime(&dt);

    setup_display(&disp);

#ifdef BUZZER_SWEEP_TEST
    buzzer_sweep_test();
#endif

    bool force_msc = watchdog_caused_reboot() &&
                     watchdog_hw->scratch[3] == MSC_BOOT_MAGIC;
    if (force_msc) {
        watchdog_hw->scratch[3] = 0;
    }

    if (force_msc ? msc_present_timeout(10000000) : msc_present()) {
        // The wireless chip has to be powered for the VSYS-based unplug
        // detection in on_msc — see there.
        msc_vsys_ok = cyw43_arch_init() == 0;
        if (watchdog_caused_reboot() && watchdog_hw->scratch[5] == MSC_HANG_MAGIC) {
            char msg[12];
            ssd1306_clear(&disp);
            if (watchdog_hw->scratch[7] == PANIC_MAGIC) {
                // The format string lives in flash at the same address as
                // long as the same image is running.
                const char *fmt = (const char *)watchdog_hw->scratch[6];
                char line[22];
                snprintf(msg, sizeof(msg), "PANIC %02lX", (unsigned long)watchdog_hw->scratch[2]);
                ssd1306_draw_string(&disp, 0, 0, 2, msg);
                for (int i = 0; i < 3; i++) {
                    snprintf(line, sizeof(line), "%.21s", fmt + 21 * i);
                    ssd1306_draw_string(&disp, 0, 18 + 10 * i, 1, line);
                }
            } else {
                snprintf(msg, sizeof(msg), "HANG P%lu", (unsigned long)watchdog_hw->scratch[4]);
                ssd1306_draw_string(&disp, 0,  0, 2, msg);
            }
            ssd1306_show(&disp);
            sleep_ms(10000);
        }
        watchdog_hw->scratch[6] = 0;
        watchdog_hw->scratch[7] = 0;
        // Any watchdog reset from here on returns into MSC state and
        // reports the phase that was in flight.
        watchdog_hw->scratch[3] = MSC_BOOT_MAGIC;
        watchdog_hw->scratch[4] = MSC_PHASE_NONE;
        watchdog_hw->scratch[5] = MSC_HANG_MAGIC;
        watchdog_enable(MSC_WATCHDOG_MS, 1);
        state = MSC;
        display_message(&disp, "MSC MODE");
    } else {
        display_message(&disp, "INIT STOR");
        multicore_launch_core1(&data_storage_core1);
        int err = (int)multicore_fifo_pop_blocking();
        if (err < 0) {
            display_message(&disp, "CARD ERR");
            while(true) { tight_loop_contents(); }
        }

        if (!load_config()) {
            display_message(&disp, "CONF ERR");
            while(true) { tight_loop_contents(); }
        }

        setup_ntp(config.ntp_server);
        cyw43_arch_init_with_country(config.country);
        setenv("TZ", config.timezone, 1);
        tzset();

        scb_orig = scb_hw->scr;
        clock0_orig = clocks_hw->sleep_en0;
        clock1_orig = clocks_hw->sleep_en1;

        boardid_load_current_suffix();

        calibrate_if_needed();

        create_button(BUTTON_LEFT, NULL, on_left_press, on_left_longpress);
        create_button(BUTTON_RIGHT, NULL, on_right_press, on_right_longpress);
    }

    while (true) {
        state_handlers[state]();
    }

    return 0;
}

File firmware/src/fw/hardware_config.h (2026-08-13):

#ifndef _HARDWARE_CONFIG_H
#define _HARDWARE_CONFIG_H

// ----------------------------------------------------------------------------
// PIO I2C (for DS3231 and default display)

#define I2C_PIO          pio0
#define I2C_SM           0
#define PIO_PIN_SDA      2
// SCL has to be PIO_PIN_SDA+1

// ----------------------------------------------------------------------------
// Battery

#define BATTERY_MIN_V    3.3f
#define BATTERY_MAX_V    4.2f
#define BATTERY_RANGE    (BATTERY_MAX_V - BATTERY_MIN_V)

// ----------------------------------------------------------------------------
// Buttons

#define BUTTON_LEFT      4
#define BUTTON_RIGHT     5

// ----------------------------------------------------------------------------
// Display

#define DISPLAY_WIDTH    128
#define DISPLAY_HEIGHT    64
#define DISPLAY_FLIPPED    0

#ifdef SPI_DISPLAY
#define DISPLAY_SPI      spi1
#define DISPLAY_PIN_MISO 12
#define DISPLAY_PIN_MOSI 11
#define DISPLAY_PIN_SCK  10
#define DISPLAY_PIN_CS   13
#define DISPLAY_PIN_RST  6
#else
#define DISPLAY_ADDRESS  0x3c
#endif // SPI_DISPLAY

// ----------------------------------------------------------------------------
// MicroSD card reader

#ifdef SPI_MICROSD
#define MICROSD_SPI      spi0
#define BAUD_RATE        (6.75 * 1000 * 1000) // (25 * 1000 * 1000))
#define MICROSD_PIN_MISO 16
#define MICROSD_PIN_MOSI 19
#define MICROSD_PIN_SCK  18
#define MICROSD_PIN_CS   17
#else
#define SD_SDIO_PIO      pio1
#define SD_SDIO_PIN_CMD  18
#define SD_SDIO_PIN_D0   19
// The other SDIO pins have to be:
//   CLK = SD_SDIO_PIN_D0 - 2
//   D1 = SD_SDIO_PIN_D0 + 1
//   D2 = SD_SDIO_PIN_D0 + 2
//   D3 = SD_SDIO_PIN_D0 + 3
#endif // SPI_MICROSD

// ----------------------------------------------------------------------------
// Fork and shock sensors

#ifdef FORK_LINEAR
#define FORK_I2C         i2c0
#define FORK_PIN_SDA     8
#define FORK_PIN_SCL     9
#define FORK_PIN_DRDY    21
#else
#define FORK_I2C         i2c0
#define FORK_PIN_SDA     8
#define FORK_PIN_SCL     9
#define FORK_PIN_DRDY    21
#endif // FORK_LINEAR

#ifdef SHOCK_LINEAR
#define SHOCK_I2C        i2c1
#define SHOCK_PIN_SDA    14
#define SHOCK_PIN_SCL    15
#define SHOCK_PIN_DRDY   27
#else
#define SHOCK_I2C        i2c1
#define SHOCK_PIN_SDA    14
#define SHOCK_PIN_SCL    15
#define SHOCK_PIN_DRDY   27
#endif // SHOCK_LINEAR

#endif // _HARDWARE_CONFIG_H

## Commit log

2025-05-27 Several changes in GUI and backend
    Removed second y-axis in wheel travel diagram.
    Flipped x- with y-axis in travel histograms.
    Increased the number of bins in travel histograms.
    Changed x-axis from absolute to relative travel in travel histograms.
    Added marker and textboxes with statistical data (avg, 95th percentile, max) in travel and speed histograms.
    Replaced Savitzky-Golay filter with Whittaker-Henderson smoothing to better preserve amplitudes of narrow peaks.
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2025-06-08 Optimized WH_LAMBDA based on parameter study
    wh_lambda max. comp. velocity (mm/s) 95th percentile comp. velocity (mm/s)
    14600 2857 692
    380 5299 1168
    130 5657 1226
    100 5793 1249
    75 5995 1275
    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
2026-02-15 [ui] added switch for relative and absolute unit in travel hist. comp.
2026-03-08 layout: fill vertical space for LR/SW charts and notes panel
    - Switch Leverage Ratio and Shock-Wheel displacement Bokeh figures
    to sizing_mode='stretch_both' with min_height=255 so they expand
    to fill available grid-cell height instead of leaving empty space.
    - Remove fixed min-height from .description-box and set height:100%
    so the notes panel always fills its grid row.
    - Add height:100% to .lr, .sw, .description wrapper elements and
    their inner .bk-root containers to propagate height correctly.
    - Replace grid-auto-rows:max-content with explicit proportional rows
    (max-content max-content 0.95fr 1.05fr) in the large-screen media
    queries of both layout-double.css and layout-single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
2026-03-08 feat: add velocity balance comparison to Travel hist. comp. tab
    Split the comparison tab into two 50/50 columns:
    - Left: existing travel histogram comparison + FFT comparison (unchanged)
    - Right: new combined velocity balance comparison figure
    The new figure shows compression and rebound trendlines (lines only,
    no scatter dots) in a single chart with a horizontal zero-line divider.
    Compression trendlines sit in Q1 (positive velocity), rebound trendlines
    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
2026-03-08 Fix chart x-axis label clipping in dashboard tabs
2026-04-10 feat: integrate passive piezo buzzer on GPIO 7
    Add buzzer driver (PWM, non-blocking via alarm) and wire acoustic
    feedback to all button actions and state transitions per plan.
    [buzzer.c, main.c]
2026-04-15 Use BOARDID file as source of board identity
    - tcpserver: read board ID from BOARDID file on SD card instead of
    querying the Pico hardware directly; fall back to hardware ID if
    the file is missing or cannot be parsed
    - main: only write the BOARDID file on boot if it does not yet exist
    (FA_CREATE_NEW instead of FA_OPEN_ALWAYS), so a manually placed
    custom board ID is preserved across reboots
    [buzzer.c, main.c]
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2026-04-24 fix: forward-declare SNTP time hooks for gcc 14+
    Newer arm-none-eabi toolchains (gcc 14/15) treat implicit function
    declarations as errors, so lwIP's sntp.c failed to compile because
    the SNTP_GET_SYSTEM_TIME / SNTP_SET_SYSTEM_TIME_US macros reference
    get_system_time_us and set_system_time_us without having seen a
    prototype. Add explicit prototypes next to the macro definitions.
2026-04-24 fix: make buzzer_sound_confirm IRQ-safe
    buzzer_sound_confirm() is called from on_left_press / on_right_press /
    on_right_longpress, which run in alarm IRQ context via the button
    debouncer. The previous double-tone used sleep_ms(15) between tones,
    which blocks on the default alarm pool from within an alarm callback
    and can deadlock the pool.
    Collapse to a single 4 kHz tone (kept at PS1240P02BT resonance). All
    other sound functions either already avoid sleep_ms in IRQ context
    (buzzer_sound_cal) or are only invoked from non-IRQ contexts
    (sound_start/stop/sleep/wake/error).
    [buzzer.c]
2026-04-24 feat: RTC sync via iPhone over local TCP
    Add STATUS_TIME_SYNC (code 7) to the DAQ's TCP protocol so the iOS
    app can push its current UTC epoch to the DAQ whenever they share
    an access point, without the DAQ needing internet access.
    On receipt, the 8-byte int64 payload is passed to set_system_time_us()
    which updates both the Pico-internal RTC and the battery-backed
    DS3231. The server acknowledges with STATUS_TIME_SYNCED (code 11)
    and waits for STATUS_FILE_RECEIVED before continuing, matching the
    existing request/ACK pattern.
    Advertise the protocol revision via an mDNS TXT record ("proto=2")
    so older iOS clients can skip the time-sync call on v1 firmware —
    an unknown status code would othe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
2026-04-24 feat: BOARDID selection from SD-card templates after calibration
    Replaces the fixed hardware-ID BOARDID with user-selectable templates
    (BOARDID.<suffix>) chosen via buttons/OLED after a successful baseline
    calibration. Selected suffix is persisted in BOARDID.CUR and shown on
    the idle screen, so one DAQ can be moved between bikes.
    Drops the compressed-calibration stage (CAL_IDLE_2/CAL_COMP); CAL_EXP
    now writes CALIBRATION directly and transitions to the new
    BOARDID_SELECT menu (or IDLE if no templates exist).
    [main.c]
2026-05-08 fix: force shock-wheel polynomial through origin
    Unconstrained least-squares left a non-zero constant term in the 3rd-order
    fit, biasing every rear-travel sample by coeffs[0] so the signal never
    returned to 0 even when the shock was fully extended (airtime). The
    calibration defines Wheel(shock=0)=0 as a hard physical constraint, so
    zero out coeffs[0] after the fit. Bumps CurrentProcessingVersion.
2026-05-09 align velocity pipeline with Sufni.Bridge: 5-tap derivative, p=3/lambda=11, rear shock-travel reorder
    Mirrors the filter-pipeline improvements that landed in Sufni.Bridge so that
    both implementations produce identical processed blobs from the same raw data.
    WH parameters:
    - WH_ORDER 2 -> 3, WH_LAMBDA 5 -> 11. Same -3 dB cutoff (~91 Hz at 860 SPS) but
    steeper roll-off above, suppressing the central-difference noise gain at f_s/4
    without sacrificing impulse fidelity.
    Differentiation:
    - calculateDerivative goes from 3-tap to 5-tap central difference (4th-order
    accurate) for interior samples, with 3-tap and forward/backward fallbacks at
    the edges. Wider aperture bridges 1-LSB plateaus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
2026-05-16 fw: fix hang on TCP serve auto-exit (buzzer running forever)
    When Sufni.Bridge auto-exits the import via STATUS_FINISHED, the firmware
    hung after the confirm beep — buzzer stuck on, never returning to IDLE.
    Two issues addressed:
    - tcp_server_recv() called tcp_server_close() on STATUS_FINISHED from
    within the client_pcb's own recv callback while p != NULL, closing
    both client and server pcbs from lwIP callback context. The subsequent
    mdns teardown in tcpserver_serve() could then stall, blocking the
    buzzer's silence alarm and freezing on_serve_tcp() before
    wifi_disconnect / state = IDLE. The manual right-button path did not
    hit this because tcpserver_finish() only sets the stat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
    [main.c]
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2026-05-31 dashboard: handle current app-format linkage blobs
    Newer Sufni.Bridge blobs (ProcessingVersion 19) no longer serialise the derived
    linkage fields (MaxFrontTravel / MaxRearTravel / ShockWheelCoeffs are computed at
    runtime in the app) and some carry Wheelbase. The dashboard's strict Linkage
    dataclass rejected those.
    - psst.py: Linkage now reconstructs the derived fields when absent — sin(HA)*
    stroke for front travel, a 3rd-order shock->wheel polyfit (constant term forced
    to 0) from the LeverageRatio pairs for the coefficients, and poly(MaxRearStroke)
    for rear travel — exactly mirroring the C# getters (validated against a blob
    that still stores them). Adds the Wheelbase field, whic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
2026-05-31 gosst: port single-sample velocity spike rejection (parity with Sufni.Bridge)
    The velocity pipeline already matched the C# app (Whittaker-Henderson order 3 /
    lambda 11, 5-tap central difference, identical edge handling), but gosst was
    missing the post-difference single-sample spike rejection that the app applies in
    ComputeVelocity. Without it, isolated 1-sample ADC glitches produced unphysical
    velocity spikes that corrupt the velocity histograms, spectra and balance stats —
    so gosst-processed imports diverged from app-processed sessions.
    - Add SPIKE_JERK_LIMIT = 5.0e9 mm/s³ (matches Parameters.SpikeJerkLimit).
    - Add rejectSingleSampleSpikes(), a direct port of RejectSingleSampleSpikes,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
2026-07-08 firmware: keep last sensor reading per instance, not per function
    rotational_sensor_measure() (AS5600 and TeraRanger Evo Mini variants)
    cached the last reading in a function-static variable shared by the
    fork and shock instances via the same function pointer. With one
    sensor unavailable, measure() returned the other sensor's last value
    instead of 0xFFFF / its own last reading.
    Store the value in a new per-instance field sensor->last_measurement
    (initialized to 0xFFFF), matching linear_ads1115.c's per-instance
    error behavior. Only affects AS5600/EvoMini setups; the linear
    ADS1115 path is unchanged.
    [rotational.c, rotational_teraranger_evo_mini.c]
2026-07-08 gosst: airtime detection parity with Sufni.Bridge (fix stroke.go)
    Three divergences from the C# reference (Strokes.cs) that weakened the
    dashboard's airtime detection:
    - categorize(): candidate travel gate used STROKE_LENGTH_THRESHOLD *
    STROKE_LENGTH_THRESHOLD_FAC (15 mm) instead of AIRTIME_TRAVEL_THRESHOLD
    (3 mm, the constant was declared but unused) -> false positives
    - filterStrokes(): top-out merge used the 0.5 mm threshold instead of the
    15 mm one and required matching velocity signs, defeating the oscillation
    merge it was meant to do -> false negatives
    - merge now rebuilds the stroke via newStroke() so Stat is recomputed over
    the full merged span instead of keeping the first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
2026-07-10 airtime: port reworked detection to gosst, fix reprocess gate
    Bring gosst in line with Sufni.Bridge 4c72cfa: estimate each element's own
    top-out instead of assuming 0 mm, treat hovering as a rate (creep budget)
    rather than a fixed displacement, and gate unpaired candidates on a
    contiguous at-rest run near top-out. Overlap now measures against the
    shorter stroke, air candidates are tracked independently of the idling
    split (comp/rebound/idling classification left bit-for-bit unchanged), and
    detection is bounded above by AIRTIME_DURATION_MAX. CurrentProcessingVersion
    4 -> 5.
    Cross-language parity check (C# travel/velocity arrays fed through the Go
    pipeline): 302/305 corpus sessions match to t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
2026-07-12 fw: don't let the client FIN race the TCP serve auto-exit
    If the client signals STATUS_FINISHED and closes, its FIN can reach
    tcp_server_recv before the main loop observes the flag; the closed-
    connection path then overwrote the status with an error and the server
    never shut down. Keep STATUS_FINISHED sticky in that case.
2026-07-12 fw: fix MSC error reporting, survive host suspend, button init glitch
    msc_disk.c: the SCSI callbacks returned the positive block_dev_err_t
    codes to TinyUSB, which reads any positive return as "bytes
    transferred" — a failing card produced garbage sectors and mount
    timeouts instead of clean errors. Errors now set a SCSI sense and take
    the -1 STALL path. tud_msc_start_stop_cb returned sd->init()'s DSTATUS
    as a bool, i.e. success exactly on failure. Card init is centralized in
    sd_ready(), which retries on every host poll so a card left confused by
    a mid-transfer MCU reset recovers without replugging.
    main.c/on_msc: leaving MSC mode on !tud_ready() reset the device on any
    transient host-side s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
    [main.c, pushbutton.c]
2026-07-26 fw(ads1115): fix MAX_ADC_3P3V cast precedence, guard calibration baseline on read error
    [linear_ads1115.c]
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2026-07-26 fw: make shared sample buffer state volatile, clamp battery percentage, fix expanded-calibration baseline check
    [main.c]
2026-07-26 gosst: derive velocity dead band from the calibration, not fixed ADC constants
    FORK_TRAVEL_PER_LSB / SHOCK_TRAVEL_PER_LSB encoded one specific setup:
    an ADS1115 at PGA 4.096 V with a 0-3.3 V sensor swing (26400 usable
    codes) driving a 200 mm fork and a 75 mm shock sensor. They are wrong
    for any other ADC and already wrong for any calibration that does not
    span the full code range.
    Calibration.Evaluate is applied directly to the raw ADC code, so the
    millimetres represented by one code are simply the local derivative of
    the calibration:
    travelPerLsb = abs(Evaluate(ref + 1) - Evaluate(ref))
    evaluated at the median raw sample of that side, so non-linear methods
    are sampled in the middle o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
2026-08-13 fw: DRDY-Zeitstempel-Ringpuffer fuer beide ADS1115 (AP3)
    Jeder DRDY-Impuls loest eine ISR aus, die zuerst timer_hw->timerawl liest
    und dann den Wandlungswert per I2C holt. Zeitstempel und Wert landen als
    Paar im Ring. Damit wird die ADC-Uhr beobachtet statt angenommen.
    Die ISRs haengen sich per gpio_add_raw_irq_handler_with_order_priority
    ein, weil pushbutton.c den globalen GPIO-Callback belegt. Alle
    Zeitvergleiche laufen wrap-sicher ueber (int32_t)(a - b); timerawl
    laeuft nach 71,6 min ueber.
    Ein Intervall-Gate pro Kanal (0,8 mal Nominalperiode) verwirft Glitches,
    etwa Einkopplung vom SD-SPI auf die ALRT-Leitung. Der I2C-Read hat 500 us
    Timeout, damit ein haengender Bus die ISR nicht bloc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
    [drdy_probe.c, drdy_ring.c, hardware_config.h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]
2026-08-13 fw: Catmull-Rom-Resampler auf dem DRDY-Ring (AP4)
    drdy_ring_resample(channel, t_k) liefert den Messwert zum Zeitpunkt t_k,
    interpoliert aus vier Stuetzstellen des Rings. Damit entsteht die Ausgabe
    auf einem exakten Quarzraster statt auf der driftenden ADC-Uhr.
    Die Rechnung laeuft in Q16-Festkomma ueber int64-Zwischenwerte, im
    Horner-Schema. Der RP2040 hat keine FPU. Der ADS1115 liefert ein
    vorzeichenbehaftetes Wort, deshalb interpoliert der Code auf int16.
    Baseline und Clamp auf 0 bleiben im Aufrufer — clampt man die
    Stuetzstellen, verzerrt man die Kurve.
    Vier neue Zaehler decken die Randfaelle ab: zu wenige Stuetzstellen,
    t_k vor dem Fenster, t_k hinter dem Fenster, und die ISR ueberhol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
    [drdy_ring.c]
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2026-08-14 fw: fix MSC bootloop (cyw43 clamps VSYS ADC in power-save)
    The CYW43 in power-save clamps the shared ADC3/GPIO29 line to ~0 V,
    so read_voltage() in MSC mode saw ~67 mV and treated a plugged cable
    as an unplug, resetting every ~750 ms. IDLE mode only worked because
    on_battery() woke the chip first.
    - wake the cyw43 via cyw43_arch_gpio_get(2) before the ADC read
    - lower the unplug threshold 4.4 V -> 4.30 V (measured USB VSYS
    4.93 V, battery max ~4.2 V)
    - force MSC on the next boot via watchdog scratch[3] after an
    on_idle/on_cal_idle USB reset, with a 10 s enumeration window;
    cold boots keep the 1 s window
    Verified on hardware: ADC now reads 4927 mV minimum, no more resets.
    Co-Authored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
    [main.c]
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2026-08-14 fw: SMPS in PWM zwingen waehrend RECORD (Pufferrauschen behoben)
    Der RT6154 lief bei vollem Akku und geringer Last im Puls-Skip-Betrieb
    (PFM). Zwischen den Pulsen sackte die 3V3-Versorgung ein, einseitig nach
    unten. Das erschien als puffergekoppeltes Breitband-Gleichtaktrauschen auf
    beiden ADS1115, sichtbar ab Record ~248 nach jedem Puffertausch.
    on_rec_start setzt WL_GPIO1 (SMPS-PSM-Pin) high und zwingt PWM, solange die
    Aufnahme laeuft; on_rec_stop nimmt es zurueck.
    Verifikation (00282, voller Akku, 121 s Ruhe): MAD-sigma Fork/Shock 0,0 LSB
    ueber den ganzen Zyklus, kein Sag, Korrelation 0,06 (vorher 0,82).
    Kontrolllinien 88,7/177,3 Hz erhalten. Effekt war alt (13/205 v3-Archiv-
    Aufnahmen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
    [main.c]
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2026-08-22 fw: Buzzer auf gemessene Resonanz 5125 Hz abgestimmt
    Die reale Resonanz des verbauten PS1240P02BT liegt bei 5125 Hz, nicht
    bei den nominellen 4000 Hz. Eine Sweep-Messung (2000-6000 Hz grob,
    4800-5600 Hz fein) ergab den Peak bei 5125 Hz mit ~87,5 dB. Die Spitze
    ist schmal: +-400 Hz kosten 7 dB.
    Alle Toene liegen jetzt im Band 4700-5125 Hz. Die Intervalle sind
    dadurch eng. confirm (5125 Hz) und cal (4900 Hz) bleiben Einzeltoene,
    weil beide im Alarm-IRQ laufen und kein sleep_ms nutzen duerfen; sie
    unterscheiden sich nur ueber die Tonhoehe. Der Error-Ton nutzt 4700 Hz
    als Kontrast und ist auf drei Toene erweitert.
    buzzer_sweep_test() bleibt fuer spaetere Messungen im Code, hinter dem
    auskommen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
    [buzzer.c, main.c]
2026-08-26 fw: Session-Timestamp direkt aus der DS3231
    Die Session-Timestamps lagen ~30 s hinter der echten Zeit. Grund: die
    DS3231 wurde nur einmal beim Boot gelesen und in die interne RP2040-RTC
    kopiert; jeder Aufnahme-Timestamp kam danach aus dieser frei laufenden
    RTC. Ihre Genauigkeit ist die des 12-MHz-Quarzes, nicht die der TCXO,
    und korrigiert wurde sie nur bei einer WLAN-Verbindung der App — beim
    Download über USB/MSC gar nicht.
    rtc_timestamp() liest jetzt die DS3231, prüft den Wert und zieht die
    interne RTC nach. Bei unplausiblem Wert still Fallback auf die interne
    RTC, damit eine Aufnahme nie blockiert. Die Prüfung schließt dotw ein —
    rtc_set_datetime() lehnt einen Wert außerhalb 0.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
    [main.c]
2026-09-03 fw: MSC-Abbruch ~20 s nach Mount behoben (TinyUSB-0.17-Panic umgangen)
    Ursache: macOS schickt kurz nach dem Mount CLEAR_FEATURE(ENDPOINT_HALT)
    auf den MSC-Bulk-OUT-Endpunkt (0x03), waehrend der Empfang des naechsten
    CBW schon scharf ist. usbd_edpt_clear_stall() loescht in TinyUSB 0.17 das
    busy-Flag, der MSC-Klassentreiber schaltet den CBW-Empfang erneut scharf,
    und der rp2040-Port loescht beim Clear-Halt nur das STALL-Bit, der alte
    Puffer bleibt AVAIL. Ergebnis: panic("ep 03 was already available"). Der
    Panic-Text blieb in uart_tx_wait_blocking haengen (stdio-UART wird von
    TinyYUSBs board_init() registriert), das Display fror bei "MSC MODE" ein,
    das Geraet fiel vom Bus. Upstream TinyUSB (0.2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
    [main.c]
2026-09-03 docs: MSC-Abbruch nach Mount als behoben dokumentiert (9b24da0)
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2026-09-27 hw: KiCad-Projekt sst_v2 Rev. 3 (ADS131M04, ICM-42686, geroutet)
    - Schaltplan Rev. 3: ADS131M04, TLV4333-Puffer, JST-SH-Stecker zu HR30,
    74HC4040/74LVC125-Taktkette (Q7 = 32 kHz)
    - Platine 4-lagig geroutet, DRC ohne offene Verbindungen/Clearance-Fehler
    - Pico 2 W gesockelt (RaspberryPi_Pico_Common_THT), Hauptschalter als
    J_PWR1 (JST SH) nach außen geführt
    - Y1 ECS-2520MVLC-081.92 bei U2, XO_OUT im Analogbereich nur auf F.Cu
    - Analognetze mit >= 1 mm Abstand zu Takt/SPI, keine schnellen Netze
    über der In2-Trennung auf B.Cu
    - CMC DLW5BTM251SQ2L mit STEP-Modell, ESD D2-D4 PESD5V0S2BT
    - Fertigungsdaten fab/: Gerber, BOM und CPL im PCBWay-Format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
    [DLW5BTM251SQ2L.step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]
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2026-09-27 hw: Rev. 3 Review — LDO-Pinbelegung, VSYS-Diode, Verpolschutz, Fertigungsdaten
    Fehler behoben:
    - TPS7A4700: Symbol nach SBVS204G (GND-Pin lag an 3,3 V, OUT/IN vertauscht,
    ANY-OUT an 3,3 V), Footprint Texas RGW0020A, LDO-Bereich neu geroutet,
    Eingangs-C 10 uF (C22), Ausgangs-C 22 uF (C6)
    - USB-VBUS speiste in den LiPo: Schottky D_VSYS1 zwischen +VBAT_SW und VSYS
    - RTC-Backup-Diode verpolt: entfernt, CR1220 direkt an VBAT
    - Buzzer-Footprint auf 5-mm-Raster (TDK PS1240P02BT)
    - R18 an 3V3_EN entfernt, DS3231-RST offen
    - ADS131M04 DVDD aus +3V3_DIG über FB1 (Logikpegel 3,3 V)
    - CMC nach Murata-Ersatzschaltbild beschaltet (Gleichtaktdämpfung)
    - J_DEBUG1 als 1x3 UART (SWD-Pins waren unverbu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
    [sst_v2-B_Cu.gbl, sst_v2-B_Mask.gbs, sst_v2-B_Paste.gbp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]
2026-09-28 hw: Umplatzierung, Nacharbeit und Lader MCP73831
    Umplatzierung:
    - Pico 2 mm nach links, USB-Buchse innerhalb der Platine
    - Poti-Eingang links, OLED/Taster rechts, Analogblock 2 mm nach rechts
    - R49 (47k) an SD_DAT2, Y1-3D-Modell SG210
    Nacharbeit:
    - J_SD1 innerhalb der Kante und weg von H4
    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
    [sst_v2-B_Cu.gbl, sst_v2-B_Mask.gbs, sst_v2-B_Paste.gbp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]
2026-09-30 hw: Platinenbeschriftung SSDAQ v2 Rev 3 an den linken Rand
    [sst_v2.kicad_pcb]
2026-09-30 hw: Schaltung — R_STAT2 15k, R50 in ADC_RST, +3V3_DVDD, Fiducials
    - R_STAT2 20k -> 15k: CHG_STAT max. 3,15 V bei VBUS 5,25 V
    - R50 100 Ohm zwischen GP7 (ADC_RST_MCU) und ADC_RST
    - Netz +3V0_DVDD -> +3V3_DVDD, PWR_FLAG hinter FB1 (ERC-Warnung entfaellt)
    - FID1-FID3 (Symbol Fiducial in sst_v2_local), Titelblock Rev. 3
    [sst_v2.kicad_sch]
2026-09-30 hw: Layout — Fertigungsregeln, Antennen-Sperrflaeche, Abblockung, R50
    - 23 Vias +3V3_DIG 0,7/0,4 mm (Restring 0,15), Silkscreen 0,15 mm / 1,0 mm
    - min_via_annular_width und min_text_thickness 0,15
    - Rule Area Pico-Antenne: alle Kupferlagen, keine Bahnen/Vias/Pours,
    volle Pico-Breite + 1 mm; ADC_CS/SCK/SDI/SDO neu geroutet
    - C1 an U_AAF1 Pin 4, C_CHG1 an U_CHG1 Pin 4 (C_CHG1/C_CHG2 getauscht)
    - R50 unter dem Pico an Pin 10, FID1-FID3, Titelblock Rev. 3
    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
    [sst_v2.kicad_pcb]
2026-09-30 hw: Fertigungsdaten Rev. 3 (2026-09-30) neu erzeugt
    Gerber, Bohrdaten, Zip, BOM (R50, R_STAT2 15k) und CPL (103 Positionen).
    [sst_v2-B_Cu.gbl, sst_v2-B_Mask.gbs, sst_v2-B_Paste.gbp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]
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2026-09-30 hw: R_STAT2 10k (CHG_STAT max. 2,6 V), R50-Silkscreen 0,15 mm, Fertigungsdaten neu
    [sst_v2-B_Cu.gbl, sst_v2-B_Mask.gbs, sst_v2-B_Paste.gbp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]
2026-09-30 hw: Lader an die Oberkante verlegt, Thermalflaeche an VSS
    U_CHG1, C_CHG1/C_CHG2, R_PROG, R_STAT1/R_STAT2 von unter dem Pico nach
    x 113-123,6 / y 48,3-55,2 mm (zwischen J_PWR1 und J_DEBUG1). GND-Zone
    "Lader Thermal" (F.Cu, Prioritaet 2, volle Anbindung) 0,77 cm2, 6 GND-Vias
    0,6/0,3 am VSS-Pad. +VBUS, +VBAT, CHG_STAT neu geroutet, alte Leiterbahnen
    und GND-Stichleitungen unter dem Pico entfernt. Courtyard-Ausnahmen der
    sechs Teile aus sst_v2.kicad_dru entfernt (R50 bleibt). R42-Referenz
    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
    [sst_v2-B_Cu.gbl, sst_v2-B_Mask.gbs, sst_v2-B_Paste.gbp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]
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2026-10-03 hw: Referenzen 0,8 mm auf Silkscreen, J_DEBUG1/R_STAT1 umgesetzt, Fertigungsdaten neu
    Alle Referenzen von Hand positioniert, 0,8 mm Hoehe, 0,15 mm Strich
    (PCBWay-Minimum). Ausgeblendete und F.Fab-Referenzen auf F.Silkscreen.
    Gerber/Bohrdaten mit --subtract-soldermask, Zip und CPL neu erzeugt.
    ERC 0 Fehler, DRC 0 Fehler, 0 offene Verbindungen, 0 Paritaetsfehler.
    [sst_v2-B_Cu.gbl, sst_v2-B_Mask.gbs, sst_v2-B_Paste.gbp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]
2026-10-03 hw: Testpads TP1-TP15, Soft-Power MAX16150, Fuel-Gauge MAX17048
    Testpads: 15 SMD-Pads D 1,0 mm auf B.Cu (GND, Versorgungen, ADC-Takt,
    Referenz, ADC-Eingaenge, IMU-Takt/-Versorgung), nicht bestueckt.
    Soft-Power: J_PWR1 entfaellt. MAX16150A schaltet ueber Q_PWR1 (DMG2305UX)
    +VBAT -> +VBAT_SW. SW_L ist Ein/Aus- und UI-Taster (PB_IN direkt, BTN_L
    ueber RB751S40). GP28 = PWR_OFF (ueber 2N7002 an CLR), Teiler
    VBAT_SENSE R19/R20/C29 entfaellt.
    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
    [sst_v2-B_Cu.gbl, sst_v2-B_Mask.gbs, sst_v2-B_Paste.gbp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]
2026-10-03 hw: Pico 7 mm nach links, Pico-Netze neu geroutet
    U1 von x 141,4 nach 134,4: Antennenende 0,2 mm vor der linken
    Platinenkante, USB-Ende bei x 137,1 (7,4 mm Platine davor). Der
    90-Grad-Micro-B-Stecker ragt dadurch rund 7 mm weniger ueber die Kante,
    das Gehaeuse wird schmaler. Keepout "Pico antenna" mitverschoben
    (x 84,5-94,0), R50 direkt an GP7, Platinentexte an den rechten Rand.
    Leiterbahnen 2697 -> 2735 mm, Vias 250 -> 264. ERC 0 Fehler, DRC
    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
    [sst_v2-B_Cu.gbl, sst_v2-B_Mask.gbs, sst_v2-B_Paste.gbp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]
